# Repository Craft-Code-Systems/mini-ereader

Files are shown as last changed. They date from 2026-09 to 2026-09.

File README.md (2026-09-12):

# Mini E-Reader

> A pocket, frontlit e-paper reader you can build and hack.
> ESP32-S3 + 4.26" E-Paper (800×480) + tunable-white frontlight,
> USB-C charged, LiPo powered.

This repository holds the open hardware (KiCad) and project documentation
for a small e-reader. Docs follow the [Colophon](https://usecolophon.dev)
method: a Brief (this file), Decisions (`docs/adr/`), a Log
(`docs/research-log.md`), a Runbook (`docs/runbook.md`), and a Changelog.

> **One KiCad project, one source of truth.** The board lives at the repo root:
> **`ereader.kicad_pcb`**, with the electrical design in the `ereader-*.md`
> docs — `ereader-connection-list.md` (net-by-net source of truth),
> `ereader-schematic.md` (subsystem schematic), `ereader-pcb-design.md`
> (full spec), `ereader-footprints.md` (BOM/footprint picklist) — and the
> `ereader-kicad.net` netlist. (Rev C — placed, planed, stitched, DRC-ruled;
> routing pending.) An earlier, simpler `hardware/` *reference spec* was
> removed once `ereader.*` superseded it; the historical comparison is in
> `docs/research-log.md`. The Rev C parts are reconciled into the ADRs:
> [0006](./docs/adr/0006-i2c-managed-power-path.md) (power) supersedes 0003
> and [0007](./docs/adr/0007-lm3630a-frontlight-driver.md) (frontlight)
> supersedes 0005.

## Why

Commercial e-readers are closed and hard to modify. This is a compact,
documented reference design — cheap parts, two-layer board, hand- or
JLCPCB-assemblable — for reading plain text / EPUB on a persistent,
sunlight-readable display with an adjustable frontlight and Wi-Fi sync.
A buildable learning platform, not a product.

## Scope & non-scope

**In scope**
- Schematic + 2-layer PCB: MCU, 4.26" SPI E-Paper, tunable frontlight,
  power (USB-C + 1S LiPo), buttons, optional microSD.
- A bill of materials and fabrication-ready outputs.
- Automated ERC/DRC + gerber export in CI.

**Out of scope (for now)**
- Enclosure / industrial design (CAD).
- Firmware (tracked separately once hardware is proven).
- Touch input, audio, multi-panel support.
- Certification / mass production.

## Success criteria

1. Schematic captured with **ERC clean** in KiCad 8.
2. PCB placed + routed with **DRC clean**; gerbers export in CI.
3. A built prototype: powers from USB and battery, charges, enumerates
   over native USB, refreshes the E-Paper, and lights the frontlight with
   independent brightness + colour-temperature control.

## Capabilities

- Render text/EPUB to a 4.26" 800×480 monochrome E-Paper panel over SPI.
- Tunable-white frontlight: independent cold/warm channels, PWM brightness
  and colour-temperature mixing.
- Wi-Fi/BLE (ESP32-S3) for fetching and syncing books.
- Battery power (1S LiPo) with USB-C charging and USB-priority power path.
- Battery state-of-charge and charge-status telemetry.
- Three navigation buttons; BOOT/RESET jumper pads (screwdriver-shortable) for flashing.
- Optional microSD for local library storage.

## Non-functional baseline

- **Power:** deep-sleep with the page retained in the µA range; runs from a
  single LiPo; charges over USB-C.
- **Cost/build:** two-layer FR-4, common parts, low-cost assembly.
- **Serviceability:** test points on key rails and buses; native-USB
  programming with no external bridge.
- **Docs:** every significant decision captured as an ADR before it is
  built.

## Stack

- **MCU:** ESP32-S3-WROOM-1 (Wi-Fi/BLE, PSRAM, native USB).
- **Display:** Good Display **GDEY0426T82-FL01C** — 4.26" 800×480 E-Paper,
  controller **SSD1677**, 4-wire SPI, 24-pin FPC, with an integrated dual
  frontlight (5+5 series white LEDs, VF≤15 V, IF≤15 mA).
- **Power:** MCP73831 charger, discrete USB-priority load-share,
  AP2112K-3.3 LDO; 2× TPS61165 frontlight boost drivers.
- **EDA:** KiCad 8. **CI:** GitHub Actions (`kicad-cli` ERC/DRC/export).

## Status & milestones

**v0.1 — design captured; reviewable schematic in `ereader-schematic.md`; native Eeschema `.kicad_sch` + routed PCB not yet drawn in KiCad.**

- [x] Architecture, power tree, net list, pin map — `ereader-pcb-design.md` + `ereader-connection-list.md`
- [x] Decisions recorded — `docs/adr/0001`–`0005`
- [x] KiCad board `ereader.*` placed + config that opens cleanly
- [x] BOM + SKiDL netlist generator
- [x] CI: `kicad-cli` ERC/DRC/export workflow
- [~] Schematic — reviewable subsystem diagrams in `ereader-schematic.md`; native Eeschema capture + **ERC clean** pending
- [ ] PCB placed, routed + **DRC clean**
- [ ] Prototype built + brought up

Live verification state: the milestone checklist above.

## Key decisions

| # | Decision |
|---|---|
| [0001](./docs/adr/0001-mcu-esp32-s3.md) | ESP32-S3-WROOM-1 as the MCU |
| [0002](./docs/adr/0002-display-and-frontlight.md) | 4.26" 800×480 E-Paper + laminated tunable frontlight |
| [0003](./docs/adr/0003-power-architecture.md) | USB-C + 1S LiPo, load-share, 3.3 V LDO *(superseded by 0006)* |
| [0004](./docs/adr/0004-native-usb-programming.md) | Native-USB programming (no UART bridge) |
| [0005](./docs/adr/0005-frontlight-driver.md) | Dual boost constant-current frontlight driver *(superseded by 0007)* |
| [0006](./docs/adr/0006-i2c-managed-power-path.md) | I2C-managed power path: BQ25628E + TPS62840 + MAX17048 |
| [0007](./docs/adr/0007-lm3630a-frontlight-driver.md) | LM3630A single-boost dual-sink frontlight driver |
| [0008](./docs/adr/0008-navigation-input.md) | Navigation input: 3 side buttons + ALPS SLLB510200 lever switch |

## Getting started

```
# Open the board in KiCad 8
kicad ereader.kicad_pro

# Read the electrical design (source of truth)
less ereader-connection-list.md
```

See [`docs/runbook.md`](./docs/runbook.md) for capture, verification,
CI, fabrication, and bring-up. Component-level detail lives in
[`ereader-pcb-design.md`](./ereader-pcb-design.md) and
[`ereader-schematic.md`](./ereader-schematic.md).

## Repository layout

```
README.md              This Brief
CHANGELOG.md           Project history
ereader.*              The KiCad board (project, PCB, netlist, cmp)
ereader-*.md           Electrical source of truth: connection-list, schematic, pcb-design, footprints, README
ereader.pretty/        Project footprints (side tactile, ALPS SLLB5 lever)
ereader.3dshapes/      Simple 3D bodies for the project footprints
fp-lib-table           Registers the ereader.pretty footprint library
fab.py                 Gerber/drill export helper (preflight-gated)
gen_netlist.py         SKiDL netlist generator (real symbols → clean import)
preflight.py           Board↔netlist parity check (CI gate; fab.py guard)
docs/
  adr/                 Decisions (0001–0008 + template)
  research-log.md      Dated exploration notes
  runbook.md           Capture / verify / fabricate / bring-up
templates/             Colophon document templates (for ongoing use)
.github/workflows/     CI (KiCad ERC/DRC/export)
```

## License

[MIT](./LICENSE) for code, hardware, and documentation. *(This repository
started from the [Colophon](https://usecolophon.dev) template; the doc
method is reused under MIT here — the template's separate CC BY methodology
license has been removed.)*

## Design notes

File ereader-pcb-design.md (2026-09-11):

# Mini E-Reader — PCB Design Spec (Rev C)

Schematic-level ref. Not gerbers. Follow in KiCad. All part numbers byte-exact — verify against latest datasheets before order.

Rev C: frontlight FULLY RESOLVED from FL0426-S01C (2 independent 4-wire strings), CHG_CE hardware fallback locked in, magnet alignment silk markers, battery band set.

---

## 1. Decisions / assumptions

- MCU = **ESP32-S3-WROOM-1-N16R8** (kept). 8 MB octal PSRAM holds 800×480×2-plane framebuffer (96 KB) + EPUB render + fonts. 16 MB flash = OTA A/B + fonts + cache.
- Panel = **GDEY0426T82-FL01C** (frontlight cool/warm, 800×480, SSD1677, SPI, 3V3 logic). Panel FPC = 24-pin 0.5 mm. Frontlight FPC = 6-pin 0.5 mm (**FL0426-S01C**, confirmed §7).
- Battery = single-cell Li-Po, **~1000–2000 mAh, thin large-area**. Fast charge not needed → conservative Ichg (§8).
- USB-C = charge + native USB-OTG data + program (one connector; native USB-Serial/JTAG on S3).
- SoC charge cap (stop 80 / resume 50) = ESP32 over I2C, + hardware CE fallback (§8).
- Program/recovery = native USB + BOOT + RESET **jumper pads** (bare exposed
  pads, momentarily shorted with a screwdriver tip or tweezers — no switch part).

---

## 2. Block diagram

```
              USB-C (16p)
          VBUS │ CC1/CC2(5.1k) │ D+ D-  │ SBU(nc)
               │               │        │
        ┌──────┴──────┐   ┌────┴────┐   │
   ESD  │ USBLC6-2SC6 │   │(to S3   │   ESD (same array)
        └──────┬──────┘   │ USB19/20)│
               │VBUS               │
        ┌──────┴───────┐           │
        │ BQ25628E     │ I2C0(0x6B)│
        │ 2A buck chg  ├───────────┼──┐
        │ CE ◄─GPIO14  │           │  │
        └──┬────────┬──┘           │  │I2C0
        BAT│      SYS│             │  │
     ┌─────┴───┐  ┌──┴─────────┐   │  │
     │ Li-Po 1S│  │ TPS62840   │   │  │
     └────┬────┘  │ buck 3V3   │   │  │
      VBAT│       └──┬─────────┘   │  │
     ┌────┴─────┐ 3V3│             │  │
     │MAX17048  │    ├─────────────┼──┼──► ESP32-S3-WROOM-1-N16R8
     │gauge 0x36│────┘ I2C0        │  │      │  │  │
     └──────────┘                  │  │      │  │  └─I2C1(0x36)─► LM3630A ─► FL 6p FPC
                                   USB │      │  └─SPI──────────► EPD 24p FPC
                                       └─USB  └─SPI──────────► microSD
   Inputs: 3× side btn + SLLB510200 (CW/CCW/push) → GPIO pull-up, wake
   Prog:   BOOT(GPIO0) + RESET(EN) jumper pads (short w/ screwdriver)
```

---

## 3. BOM (core)

| Ref | Part | Fn | Notes |
|-----|---|-----|---|
| U1 | ESP32-S3-WROOM-1-N16R8 | MCU+radio | pre-certified module (FCC/IC/CE). Follow integration guide |
| U2 | TI **BQ25628E** | 1S I2C buck charger 2A | addr 0x6B. EN_CHG reg + CE pin (§8) |
| U3 | Maxim **MAX17048G+T10** | fuel gauge (ModelGauge, no sense R) | addr 0x36, I2C0 |
| U4 | TI **LM3630A** | dual-string I2C backlight boost | addr 0x36 → I2C1 (§7) |
| U5 | TI **TPS62840** | 3V3 buck 750 mA, Iq 60 nA | LDO alt if area-tight |
| U6 | ST **USBLC6-2SC6** | USB ESD array | D+/D-/CC/VBUS |
| J1 | USB-C recept 16-pin (e.g. GCT USB4085) | power+data | |
| J2 | 24-pin 0.5 mm FPC, bottom-contact | EPD | flip-lock |
| J3 | 6-pin 0.5 mm FPC | frontlight | 1=C+ 2=C− 3=NC 4=NC 5=W+ 6=W− |
| J4 | microSD push-pull holder | storage | |
| SW1–3 | Würth **WS-TASU 436351045816** (side push) | page/menu | `ereader:WE_WS-TASU_436351045816`; actuator faces board edge; Ø0.75 boss holes |
| SW4 | ALPS **SLLB510200** (510100 = alt) | lever+push (CW/CCW/press) | 10 mA/5 V max, 9.5×8.8×2.2 mm; `ereader:ALPS_SLLB5_Lever`; 2mm-pitch pads + Ø1.1 locators |
| JP5 | Bare pads (no MPN) | BOOT | GPIO0→GND, shorted momentarily w/ screwdriver/tweezers; `ereader:JumperPad_2P_P2.0mm` |
| JP6 | Bare pads (no MPN) | RESET | EN→GND, shorted momentarily w/ screwdriver/tweezers; `ereader:JumperPad_2P_P2.0mm` |
| — | 5.1 kΩ ×2 | CC1/CC2 Rd (sink) | |
| — | 100 kΩ | EN pull-up + 1 µF | module EN weak ~2 MΩ |
| — | 100 kΩ pull-up ×2 | EPD_CS, SD_CS idle-high thru boot | §5 |
| — | 100 kΩ pull-down ×1 | FL_HWEN (FL off at boot) | §5 |
| — | 100 kΩ strap ×1 | CHG_CE boot-default = charge-on | §8 |
| — | 4.7 kΩ ×4 | I2C0 + I2C1 pull-ups | |
| LE/QE/DE1-3/RE1-2/CE1-9 | SSD1677 external DC-DC (L+N-FET+3×Schottky+sense R+rail caps) | now captured line items | §6; copy interconnect 1:1 from Good Display ref |

---

## 4. Power tree

```
USB VBUS 5V ──► BQ25628E ──► SYS ──► TPS62840 ──► 3V3 rail
                    └──────► BAT (Li-Po 1S)
3V3  → U1 (≥500 mA headroom; RF bursts >avg), microSD, EPD VDD, gauge, logic
VBAT → LM3630A boost → ~15–18 V (2×5-series strings), Iset ≤15 mA/ch
VBAT → MAX17048 sense
```

- 3V3 survives S3 TX burst (~0.5 A): TPS62840 (750 mA) + 22 µF bulk at module 3V3.
- **I2C clash fix = 2 buses (locked).** Keeps sense-less MAX17048 + dual-ch LM3630A. 1-bus alt only if forced: gauge → BQ27441-G1A @0x55 (needs sense R).

---

## 5. ESP32-S3 pin map

Safe pins: 1–18, 21, 38–42, 47, 48. **Never 26–37** (26–32 flash, 33–37 octal PSRAM). USB 19/20 native. GPIO21 = static enable only.

| Signal | GPIO | Dir | Note |
|---|---|-----|---|
| EPD_SCLK | 12 | O | SPI ≤10–20 MHz |
| EPD_MOSI | 11 | O | DIN |
| EPD_CS | 10 | O | 100k pull-up (idle-high thru boot) |
| EPD_DC | 9 | O | |
| EPD_RST | 8 | O | boot-low harmless (re-reset in init) |
| EPD_BUSY | 7 | I | |
| SD_SCK | 41 | O | own SPI bus |
| SD_MOSI | 42 | O | |
| SD_MISO | 40 | I | |
| SD_CS | 39 | O | 100k pull-up (idle-high) |
| I2C0_SDA | 17 | IO | charger 0x6B + gauge 0x36 |
| I2C0_SCL | 18 | IO | |
| I2C1_SDA | 16 | IO | LM3630A 0x36 |
| I2C1_SCL | 38 | IO | |
| BTN_A | 4 | I | pull-up, RTC-wake |
| BTN_B | 5 | I | pull-up, RTC-wake |
| BTN_C | 6 | I | pull-up, RTC-wake |
| LEV_CW | 1 | I | pull-up, RTC-wake |
| LEV_CCW | 2 | I | pull-up, RTC-wake |
| LEV_PUSH | 15 | I | pull-up, RTC-wake |
| CHG_INT | 47 | I | BQ25628E /INT |
| GAUGE_ALRT | 48 | I | MAX17048 /ALRT (low-SoC wake) |
| FL_HWEN | 21 | O | LM3630A HWEN; 100k pull-down (FL off at boot) |
| CHG_CE | 14 | O | BQ25628E CE; 100k strap = charge-on default (§8) |
| BOOT | 0 | I | strap; JP5→GND (jumper pad); module 10k pull-up |
| RESET | EN | I | JP6→GND (jumper pad); 100k pull-up + 1 µF |
| USB_D- | 19 | — | native → J1 |
| USB_D+ | 20 | — | native → J1 |

Free/unused after this map: 3(strap), 13. All 6 btn/lever inputs RTC-capable → wake sources; assign BTN_A + LEV_PUSH, ext1-mask rest.

### Glitch-safe by design
- ⚠ GPIO1–18 ~60 µs low pulse at power-up; 18/19/20 glitch high. Audited:
- EPD_CS(10) + SD_CS(39): 100k pull-up → idle high thru boot → no spurious select. ✓
- FL_HWEN(21): 100k pull-down → frontlight OFF until firmware. ✓
- CHG_CE(14): 100k strap to charge-on level → boot-low pulse benign (charger debounces; default is charge-on anyway). ✓
- EPD_RST(8): boot-low benign (re-reset in init). ✓
- I2C0/1 + all btn/lever: pull-ups present → absorbed. ✓
- No glitch-sensitive load (gate/latch/relay) hangs unpulled off a glitchy pin. Glitch-safe. ✓

---

## 6. EPD subsystem (SSD1677)

4-line SPI (SDA-in only; write-mostly). Tie **BS1** for 4-wire SPI.

Match the **panel datasheet pin numbers exactly** (24-pin EPD FPC, 0.5 mm):
- Logic: SCLK, SDA(MOSI), CS, DC, RST, BUSY, VDD=3V3, VSS=GND, BS (tie low = 4-wire SPI).
- Booster/analog: GDR, RESE, VSH1/VSH2, VSL, VGL, VGH, VCOM, VCI, VDD, VPP — external DC-DC + reservoir caps per the **Good Display reference circuit** ("ESP32 Sample Code" zip). Copy 1:1; rail values non-negotiable. Short FPC stubs; guard-ground under booster caps.

**External DC-DC — exact values** (from the Good Display GDEY0426T82-FL01C reference circuit; verify against the panel datasheet before order. Designators are from that reference — renumber to match the `ereader` schematic):
- **L** 47 µH, ≥500 mA (NR3015 class): +3V3 → switch node (boost FET drain).
- **Q** Si1308EDL N-MOSFET (SOT-23): gate = GDR, drain = switch node, source = RESE. **R** 1 MΩ GDR→GND (gate pulldown) + **R** 2.2 Ω RESE→GND (current sense).
- **D×3** MBR0530 Schottky (≥30 V, ≥500 mA): one builds PREVGH (→ VGH); two build the PREVGL (→ VGL) charge-pump path.
- **Caps (all ≥25 V, X5R/X7R):** 4.7 µF on VSH1, VSH2, VSL, VGL/PREVGL, VGH/PREVGH, and the +3V3 boost input; 1 µF on VCI, VDD, VCOM.
- Internal rails: **VGH ≈ +20 V, VGL ≈ −20 V, VSH ≈ +15 V, VSL ≈ −15 V, VCOM ≈ −2 V** — hence the ≥25 V cap rating. Panel VCI draw is small (~7.5 mA), so the +3V3 boost input is light.

> **Now captured** (Rev C4) in `ereader-kicad.net` / `ereader-connection-list.md` as
> `LE` (47µH), `QE` (Si1308EDL), `DE1‑DE3` (MBR0530), `RE1` (2.2Ω sense), `RE2` (1MΩ
> GDR pulldown), `CE1‑CE6` (4.7µF/25V rails), `CE7‑CE9` (1µF/25V). ⚠ The diode/charge‑pump
> **interconnect + orientation + J2 FPC pin numbers are a functional placeholder** —
> transcribe them 1:1 from the Good Display reference before capture/route. Some SSD1677
> rails may be internally generated (external reservoir cap only); the reference is the
> authority on the actual diode/pump-cap count.

- Mechanical: EPD 24p FPC + FL 6p FPC both exit the bottom edge → place J2 + J3 adjacent on bottom edge.

---

## 7. Frontlight (LM3630A) — CONFIRMED

Source: **FL0426-S01C** drawing. Two **independent 4-wire** series strings (NOT common-anode):

| FL pin | Net | String |
|---|---|---|
| 1 | LED C+ | Cold anode |
| 2 | LED C− | Cold cathode |
| 3 | NC | — |
| 4 | NC | — |
| 5 | LED W+ | Warm anode |
| 6 | LED W− | Warm cathode |

- Cold = 5 series LED, Warm = 5 series LED. Per-LED Vf 2.8–3.6 V → string VF ≤15 V; IF ≤15 mA each. (10 LEDs total; "7 LED" web spec = wrong rev.)

**Final wiring (LM3630A single boost, dual sink):**
```
LM3630A OUT (boost) ──┬── FL pin1 (C+)
                      └── FL pin5 (W+)      ← both anodes tie to OUT
FL pin2 (C−) ── LM3630A LED1 sink (Bank A = COOL)
FL pin6 (W−) ── LM3630A LED2 sink (Bank B = WARM)
FL pin3,4 = NC
```
- Equal string length → shared boost OUT is efficient; boost regulates to the active sink. Set OVP ≥18 V (5×3.6). Program each bank Iset ≤15 mA; PWM per bank.
- Independent on/off + brightness per bank → full cool/warm blend + global dim. Firmware over I2C1 (0x36). FL_HWEN(21) = hard off in standby.
- No common-anode strap option needed (topology confirmed 4-wire). Drop that DNP.
- EMI: boost L + Cout loop <5 mm, local ceramics, far from antenna + FPC.

---

## 8. Charging + SoC optimization (ESP32-managed + HW fallback)

Chain: BQ25628E (charge control) + MAX17048 (SoC truth), both I2C0.

Primary control = **ESP32 over I2C** (BQ25628E EN_CHG) — the 80/50 mechanism, no fixed hardware threshold:
```c
soc = max17048_read_soc();            // %
if (soc >= 80) bq25628_charge_dis();  // clear EN_CHG
if (soc <= 50) bq25628_charge_en();   // set EN_CHG
```
- Hysteresis 50↔80 stops chatter.
- Default charge-on at power-up (before firmware) → dead-battery recovery; firmware then applies 80/50.
- **HW fallback (locked): CHG_CE → GPIO14**, 100k strap to charge-on level. Firmware can hard-cut even if I2C hangs; still ESP32-commanded (not a fixed threshold).
- **Ichg conservative** (fast charge not needed): set ~0.3–0.5C via reg → e.g. 500 mA for a 1.5 Ah cell. Gentler on a thin large-area pack; less heat. BQ25628E caps at 2 A regardless.
- Optional longevity: VREG 4.10–4.15 V (vs 4.20).
- Gauge /ALRT → GPIO48: low-SoC → wake + graceful shutdown.
- Enable BQ25628E thermal reg / JEITA; add NTC if pack has one.

---

## 9. USB-C

- Sink only: CC1,CC2 each 5.1 kΩ → GND (Rd). No source/DRP.
- VBUS → BQ25628E VBUS (+ input cap, + TVS via U6).
- D+/D- → S3 GPIO19/20 native + through U6 ESD. 90 Ω diff, length-match, short.
- SBU1/2 = NC. Shield → chassis via R+C (or direct per EMC).
- Full-speed (12 Mbps) fine for book sync/MSC + JTAG/programming.

---

## 10. Compliance (FCC / CE)

**Intentional radiator** handled by module. ESP32-S3-WROOM-1 = **FCC ID 2AC7Z-ESPS3WROOM1** + IC + CE/RED (modular). Inherit by:
- Module at board edge, antenna over edge, honor keep-out (no copper any layer, no traces, no fill, no parts).

**Magnets (phone-attach) — #1 RF risk:**
- Magnets live in the **3D-printed shell** (avoid NdFeB near reflow). PCB carries **silk alignment markers only** (see §11) so you register the shell's magnet pockets to the board — magnets are NOT on the PCB.
- Keep magnet zone ≥10–15 mm from antenna keep-out; opposite end from module.
- ⚠ Bigger issue = the **phone's own MagSafe ring + metal chassis** (always behind device). Orient antenna edge to overhang / clear the phone magnet array + metal. Antenna over free space, not over phone metal.

**Unintentional radiator / product testing still required:**
- FCC Part 15B (verification) — USB, switchers, digital.
- CE: EN 55032 + EN 55035; RED via module + product EMC; LVD N/A (<50 V). RoHS + REACH.
- Switchers (charger buck + FL boost) = main 15B risk: minimal switch-node loops, ceramics close, solid GND, spread-spectrum if available, optional shield can over FL boost.
- USB: ESD array (U6) + DNP common-mode choke footprint on D+/D-.
- Solid uninterrupted GND on layer 2; stitch vias around edge + keep-out.
- Use WROOM-1 (PCB antenna), not WROOM-1U, unless you certify an external antenna.

---

## 11. Layout rules (priority order)

1. Module antenna at edge, keep-out clear; magnet zone far (+ mind phone magnet ring, §10).
2. Continuous GND plane under everything except antenna keep-out.
3. FL boost: L + Schottky + Cout in <5 mm loop, far from antenna + FPC.
4. Charger buck loop tight; input cap at VBUS pin.
5. EPD booster caps hugging FPC pins; short stubs. J2 + J3 adjacent on bottom edge.
6. USB D+/D- 90 Ω diff, ESD at connector then module.
7. Decouple module 3V3: 22 µF + 4×0.1 µF at power pins; bulk at buck.
8. EN: 100 kΩ pull-up + 1 µF + RESET(JP6). BOOT(JP5)→GPIO0→GND.
9. Boot-default pulls: EPD_CS/SD_CS 100k↑, FL_HWEN 100k↓, CHG_CE 100k strap = charge-on.
10. I2C0 + I2C1: 4.7 kΩ pull-ups each to 3V3.
11. **Magnet alignment silk markers**: on the face nearest the shell magnets, print crosshair/circle fiducials at each magnet pocket center so the printed shell registers to the PCB. Copper-free zones there (mechanical only). Mirror position on far end from antenna.
12. Test points: 3V3, VBAT, SYS, I2C0, I2C1, BOOT, EN.

---

## 12. Stack / process

- 4-layer (SIG / GND / PWR / SIG). Controlled-Z for USB pair. ENIG finish (FPC + fine pitch).

---

## 13. Status

- Frontlight: **RESOLVED** — 2 independent strings (5 cool + 5 warm), 4-wire, LM3630A dual-bank (§7).
- Battery: ~1000–2000 mAh thin cell; only sets Ichg reg + case (non-schematic-blocking). Watch mechanical: recess the thin cell, no flex over components.
- Nothing outstanding blocks schematic capture.

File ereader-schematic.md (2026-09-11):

# Mini E-Reader — Schematic (subsystem view)

> **Why this file exists / why there is no `.kicad_sch`.** This board was captured
> **netlist-first**: the electrical design lives in
> [`ereader-connection-list.md`](./ereader-connection-list.md) (source of truth) →
> [`ereader-kicad.net`](./ereader-kicad.net) (netlist) → [`ereader.kicad_pcb`](./ereader.kicad_pcb)
> (placement). No schematic sheet was ever drawn, so KiCad's **Schematic Editor
> (Eeschema) has nothing to open** — that is the answer to "why is there no schematic".
>
> KiCad **cannot** auto-generate a schematic from a netlist or from the PCB (there is
> no netlist→schematic or PCB→schematic importer). A native `.kicad_sch` has to be
> *drawn* in Eeschema. The diagrams below are that schematic in reviewable form —
> they render directly on GitHub (Mermaid) and mirror the connection list net-for-net.
>
> **To get a native Eeschema schematic:** create a new schematic in the `ereader`
> project, drop the symbols for U1–U6 / J1–J5 / SW1–SW4 / JP5–JP6 / passives, and
> wire them to match these diagrams (label-based wiring is fine — same-named net
> labels connect). Run **ERC**, then it drives the same `ereader-kicad.net`.

All pin **numbers** on U1 are the exact ESP32‑S3‑WROOM‑1 datasheet pins; IC pins on
U2–U6 are by **function name** (remap to your chosen symbol's pads). Nets are taken
verbatim from the connection list.

---

## 1. System block diagram

```mermaid
flowchart LR
  USBC["USB-C J1<br/>(VBUS + USB2 + CC)"]
  ESD["U6 USBLC6-2SC6<br/>ESD"]
  CHG["U2 BQ25628E<br/>1S buck charger (I2C 0x6B)"]
  BATT["J5 Li-Po 1S"]
  GAUGE["U3 MAX17048<br/>fuel gauge (I2C 0x36)"]
  BUCK["U5 TPS62840<br/>3V3 buck"]
  MCU["U1 ESP32-S3-WROOM-1<br/>N16R8"]
  FL["U4 LM3630A<br/>dual FL boost (I2C1)"]
  EPD["J2 EPD FPC 24p<br/>SSD1677 / GDEY0426T82"]
  FLC["J3 Frontlight FPC 6p<br/>FL0426-S01C"]
  SD["J4 microSD"]
  NAV["SW1-3 side buttons<br/>SW4 SLLB5 lever"]

  USBC -->|"+VBUS"| CHG
  USBC --- ESD
  ESD ---|"USB_DP/DM"| MCU
  CHG -->|"+SYS"| BUCK
  CHG <-->|"+VBAT"| BATT
  CHG -->|"+VBAT"| GAUGE
  CHG -->|"+VBAT"| FL
  BUCK -->|"+3V3"| MCU
  MCU -->|"SPI 4-wire"| EPD
  MCU -->|"SPI"| SD
  MCU <-->|"I2C0"| CHG
  MCU <-->|"I2C0"| GAUGE
  MCU <-->|"I2C1"| FL
  FL -->|"FL_OUT + sinks"| FLC
  NAV -->|"GPIO active-low"| MCU
```

---

## 2. Power tree

```mermaid
flowchart TB
  J1["USB-C J1<br/>VBUS A4/B4/A9/B9"]
  CVBUS["C_VBUS"]
  U2["U2 BQ25628E"]
  LC["L_C ~1uH"]
  J5["J5 Li-Po +"]
  U3["U3 MAX17048"]
  U4["U4 LM3630A IN"]
  L2["L2 22uH"]
  U5["U5 TPS62840"]
  L1["L1 2.2uH"]
  RAIL3V3["+3V3 rail<br/>U1.2, J2.VDD, J4.VDD, pull-up rails, C_3V3 22uF+4x0.1uF"]

  J1 -->|"+VBUS"| U2
  J1 --- CVBUS
  U2 -->|"SW"| LC -->|"+SYS"| U5
  U2 <-->|"BAT = +VBAT"| J5
  U2 -->|"+VBAT"| U3
  U2 -->|"+VBAT"| U4
  U2 -->|"+VBAT"| L2
  U5 -->|"SW"| L1 -->|"+3V3"| RAIL3V3
  U5 -.->|"VIN = +SYS"| U2
```

`GND`: U1.1/40/41(EPAD), U2 PGND/GND/EP, U3/U4/U5/U6 GND, J1 GND+shield, J2.VSS,
J4.VSS, J5.−, all cap returns, all pull-down / switch returns.

---

## 3. MCU GPIO map (U1 = ESP32‑S3‑WROOM‑1)

| Pin | GPIO | Net | Goes to |
|-----|---|-----|---|
| 2 | 3V3 | +3V3 | supply |
| 1 / 40 / 41 | GND/EPAD | GND | ground |
| 3 | EN | EN | JP6 (RESET), R3 pull-up, C_EN |
| 27 | IO0 | IO0_BOOT | JP5 (BOOT) |
| 4 | IO4 | BTN_A | SW1.1 |
| 5 | IO5 | BTN_B | SW2.1 |
| 6 | IO6 | BTN_C | SW3.1 |
| 39 | IO1 | LEV_CW | SW4.CW |
| 38 | IO2 | LEV_CCW | SW4.CCW |
| 8 | IO15 | LEV_PUSH | SW4.PUSH |
| 10 | IO17 | I2C0_SDA | U2, U3, R8 |
| 11 | IO18 | I2C0_SCL | U2, U3, R9 |
| 9 | IO16 | I2C1_SDA | U4, R10 |
| 31 | IO38 | I2C1_SCL | U4, R11 |
| 20 | IO12 | EPD_SCLK | J2 |
| 19 | IO11 | EPD_MOSI | J2 |
| 18 | IO10 | EPD_CS | J2, R4 |
| 17 | IO9 | EPD_DC | J2 |
| 12 | IO8 | EPD_RST | J2 |
| 7 | IO7 | EPD_BUSY | J2 |
| 34 | IO41 | SD_SCK | J4 |
| 35 | IO42 | SD_MOSI | J4 |
| 33 | IO40 | SD_MISO | J4 |
| 32 | IO39 | SD_CS | J4, R5 |
| 14 | IO20 | USB_DP | U6, J1 |
| 13 | IO19 | USB_DM | U6, J1 |
| 24 | IO47 | CHG_INT | U2.INT, R12 |
| 22 | IO14 | CHG_CE | U2.CE, R7 |
| 23 | IO21 | FL_HWEN | U4.HWEN, R6 |

Strap/PSRAM/unused pins (IO3/13/45/46/35/36/37, RXD0/TXD0) → NC or test-point.

---

## 4. Navigation input (this is the input scheme from ADR 0008)

Nav contacts are **active-low momentary to GND** with the ESP32‑S3 **internal
pull-ups**; every one sits on an RTC‑capable GPIO so it can wake the MCU from deep
sleep. **SW1–SW3 are side-actuated (right-angle) tactiles** and **SW4 is the ALPS
SLLB5 two-way lever + push** — the actuators face the **board edge** because the
screen covers the whole front and magnets hold the back to the phone, so nothing
can be pressed from the top or bottom faces. **JP5/JP6 (BOOT/RESET) are not
switches** — they're bare exposed 2-pad jumpers, momentarily shorted with a
screwdriver tip or tweezers when you actually need to flash/recover the board;
they read open (floating high through the pull-up) in normal use, so there's no
switch part, cap, or accidental-press risk sitting on a rarely-used recovery path.

```mermaid
flowchart LR
  subgraph MCU["U1 ESP32-S3 (internal pull-ups, RTC-wake)"]
    IO4["IO4"]; IO5["IO5"]; IO6["IO6"]
    IO1["IO1"]; IO2["IO2"]; IO15["IO15"]
    IO0["IO0"]; EN["EN"]
  end
  SW1["SW1 side tact<br/>BTN_A"]; SW2["SW2 side tact<br/>BTN_B"]; SW3["SW3 side tact<br/>BTN_C"]
  SW4["SW4 ALPS SLLB5 lever<br/>CW / CCW / PUSH / COM"]
  JP5["JP5 jumper pad<br/>BOOT (screwdriver-shortable)"]; JP6["JP6 jumper pad<br/>RESET (screwdriver-shortable)"]
  GND(["GND"])

  IO4 -- "BTN_A" --> SW1 --> GND
  IO5 -- "BTN_B" --> SW2 --> GND
  IO6 -- "BTN_C" --> SW3 --> GND
  IO1 -- "LEV_CW" --> SW4
  IO2 -- "LEV_CCW" --> SW4
  IO15 -- "LEV_PUSH" --> SW4
  SW4 -- "COM" --> GND
  IO0 -- "IO0_BOOT" --> JP5 --> GND
  EN -- "EN" --> JP6 --> GND
```

`R3` (100k) pulls **EN** up with `C_EN` (1µF) for a clean reset; BOOT uses the
module's internal strap pull-up.

---

## 5. I2C buses

```mermaid
flowchart LR
  U1["U1 ESP32-S3"]
  R8["R8 4.7k"]; R9["R9 4.7k"]; R10["R10 4.7k"]; R11["R11 4.7k"]
  U2["U2 BQ25628E 0x6B"]; U3["U3 MAX17048 0x36"]; U4["U4 LM3630A"]
  V3["+3V3"]

  U1 -- "I2C0_SDA (IO17)" --> U2 & U3
  U1 -- "I2C0_SCL (IO18)" --> U2 & U3
  U1 -- "I2C1_SDA (IO16)" --> U4
  U1 -- "I2C1_SCL (IO38)" --> U4
  V3 --- R8 & R9 & R10 & R11
  R8 --- U2
  R9 --- U2
  R10 --- U4
  R11 --- U4
```

U3 (fuel gauge) and U4 (frontlight) both answer at 0x36 — that clash is exactly why
U4 is on a **separate bus (I2C1)**.

---

## 6. E‑paper (SSD1677 @ J2, 4‑wire SPI)

```mermaid
flowchart LR
  U1["U1 ESP32-S3"]
  R4["R4 100k"]; V3["+3V3"]
  J2["J2 EPD FPC 24p<br/>SSD1677 / GDEY0426T82"]

  U1 -- "EPD_SCLK (IO12)" --> J2
  U1 -- "EPD_MOSI (IO11)" --> J2
  U1 -- "EPD_CS (IO10)" --> J2
  U1 -- "EPD_DC (IO9)" --> J2
  U1 -- "EPD_RST (IO8)" --> J2
  J2 -- "EPD_BUSY (IO7)" --> U1
  V3 --- R4 --- J2
```

`J2.BS1` tied **low** (→GND) for 4‑wire SPI.

### 6a. EPD external DC‑DC (SSD1677 boost + charge pumps)

The SSD1677 needs an external boost + charge‑pump for its ±20 V gate / ±15 V source
rails. Now captured as real parts (LE/QE/DE1‑3/RE1‑2/CE1‑9) feeding J2's support pins:

```mermaid
flowchart LR
  V3["+3V3"]; LE["LE 47µH"]; QE["QE Si1308EDL<br/>N-FET"]
  SW["EPD_SW"]; DE1["DE1 MBR0530"]; DE2["DE2"]; DE3["DE3"]
  J2["J2 SSD1677<br/>GDR/RESE/VGH/VGL<br/>VSH1/VSH2/VSL/VCOM/VCI"]
  RE1["RE1 2.2Ω"]; RE2["RE2 1MΩ"]; GND(["GND"])

  V3 --> LE --> SW
  SW --> QE
  J2 -- "GDR" --> QE
  QE -- "RESE" --> RE1 --> GND
  J2 -- "GDR" --> RE2 --> GND
  SW --> DE1 -- "VGH" --> J2
  SW --> DE2 --> DE3 -- "VGL" --> J2
  J2 -. "VSH1/VSH2/VSL/VCOM reservoir caps CE1-3,CE9→GND" .- GND
  V3 -. "VCI/VDD caps CE6-8→GND" .- GND
```

> ⚠ **VERIFY & COPY 1:1.** The diode/charge‑pump interconnect, diode **orientation**, and
> the J2 (GDEY0426T82) **FPC pin numbers** are a functional PLACEHOLDER — transcribe them
> exactly from the Good Display GDEY0426T82‑FL01C reference schematic ("ESP32 Sample Code"
> zip) and the panel datasheet before capture + route. Rail cap **values are
> non‑negotiable** (≥25 V). See `ereader-connection-list.md` → *EPD external DC‑DC*.

---

## 7. microSD (SPI @ J4) and USB‑C data

```mermaid
flowchart LR
  U1["U1 ESP32-S3"]
  R5["R5 100k"]; V3["+3V3"]
  J4["J4 microSD"]
  U6["U6 USBLC6-2SC6"]
  J1["J1 USB-C"]
  R1["R1 5.1k"]; R2["R2 5.1k"]; GND(["GND"])

  U1 -- "SD_SCK (IO41)" --> J4
  U1 -- "SD_MOSI (IO42)" --> J4
  J4 -- "SD_MISO (IO40)" --> U1
  U1 -- "SD_CS (IO39)" --> J4
  V3 --- R5 --- J4
  U1 -- "USB_DP (IO20)" --- U6 --- J1
  U1 -- "USB_DM (IO19)" --- U6 --- J1
  J1 -- "CC1" --- R1 --> GND
  J1 -- "CC2" --- R2 --> GND
```

---

## 8. Charger (BQ25628E) + 3V3 buck (TPS62840)

```mermaid
flowchart LR
  VBUS["+VBUS"]; SYS["+SYS"]; VBAT["+VBAT"]; V3["+3V3"]
  U2["U2 BQ25628E"]; LC["L_C ~1uH"]; CBTST["C_BTST 0.047uF"]
  R7["R7 100k"]; R12["R12 10k"]; R14["R14 10k"]; R15["R15 10k"]; GND(["GND"])
  U5["U5 TPS62840"]; L1["L1 2.2uH"]
  U1["U1 ESP32-S3"]

  VBUS --> U2
  U2 -- "SW" --> LC --> SYS
  U2 -- "BTST" --- CBTST
  U2 --- VBAT
  U1 -- "CHG_CE (IO14)" --> U2
  U2 -- "CHG_INT" --> U1
  U2 -- "INT" --- R12 --> V3
  U2 -- "CE" --- R7 --> GND
  U2 -- "TS" --- R14 --> V3
  U2 -- "TS" --- R15 --> GND
  SYS --> U5
  U5 -- "SW" --> L1 --> V3
```

`CE low = charge enabled`; R7→GND makes charge-on the power-up default, GPIO14 drives
high to hard-disable.

---

## 9. Frontlight boost (LM3630A → FL0426‑S01C, 4‑wire)

```mermaid
flowchart LR
  VBAT["+VBAT"]; U4["U4 LM3630A"]; L2["L2 22uH"]; D1["D1 Schottky 30V"]
  CFL["C_FL >=25V"]; J3["J3 FL FPC 6p"]
  U1["U1 ESP32-S3"]; R6["R6 100k"]; GND(["GND"])

  VBAT --> U4
  VBAT --> L2 -- "FL_SW" --> U4
  U4 -- "FL_SW" --> D1 -- "FL_OUT" --> CFL
  D1 -- "FL_OUT" --> J3
  J3 -- "FL_COOL_K (C-)" --> U4
  J3 -- "FL_WARM_K (W-)" --> U4
  U1 -- "FL_HWEN (IO21)" --> U4
  U4 --- R6 --> GND
```

`FL_OUT` feeds both J3.1 (C+) and J3.5 (W+); LED1/LED2 sink the cool/warm banks;
`R6→GND` keeps the frontlight off by default until GPIO21 enables it.

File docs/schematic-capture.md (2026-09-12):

# Schematic Capture Worksheet (Eeschema)

Follow this once to draw a native `ereader.kicad_sch`. It turns the netlist-first
design into a proper schematic-driven project so that **Update PCB from Schematic**
works cleanly and the "pad *X* not found in footprint" errors disappear.

## Why this is needed (read once)

`ereader-kicad.net` names IC pins by **function** (`IN`, `SDA`, `SW`, `LED1`…).
KiCad's netlist import binds those names to footprint **pads**, but real footprints
number their pads (QFN `1..n`, BGA `A1/B1…`). With no symbol in between, the names
never match — that is the 56 `pad ... not found` errors seen on netlist import.

A **symbol** solves it: the symbol pairs each pin *name* with the datasheet pad
*number*. So in schematic capture you only attach nets to named pins; KiCad maps
name → pad number for you. **You never hand-map pads.**

> `ereader-connection-list.md` stays the human source of truth (net-by-net).
> The schematic *implements* it. Once the schematic drives the board, the
> hand-authored `ereader-kicad.net` is retired (Eeschema generates its own).

## One-time setup

1. Open `ereader.kicad_pro` in the KiCad project manager.
2. Open the **Schematic Editor**. It will be empty (there is no `.kicad_sch`
   yet — that is expected, and is why *Update PCB from Schematic* / F8 errored).
   Save immediately as `ereader.kicad_sch` in the project folder.
3. Capture per the tables below, then annotate → ERC → assign footprints →
   **Update PCB from Schematic**.

## Capture method: label-based wiring (do this, it's fast)

You do **not** need to draw wires across the sheet. Use **global labels**
(`Place → Add Global Label`, hotkey **Ctrl+H**) whose text is the **net name**
from `ereader-connection-list.md`. Two pins carrying the same-named global label
are connected. So the loop for every pin is:

1. Place the symbol.
2. On each pin, drop a short wire stub + a **global label** named after its net.
3. Move on. Same net name anywhere = one net.

Power nets (`+3V3`, `+VBAT`, `+SYS`, `+VBUS`, `GND`) are cleanest with **power
symbols** (`Place → Add Power`, **P**) instead of labels — `GND`, `+3V3`, etc.

## Symbol + footprint picklist

The symbol carries the pin→pad map, so **use a matched symbol+footprint pair**.
KiCad-stock ones are safe as-is; for the `SnapEDA` rows, download the symbol AND
its footprint together (they are internally consistent) and confirm the package
against the MPN. Footprints reflect the corrections in `ereader-footprints.md`.

| Ref | MPN | Symbol (lib_id or source) | Footprint |
|-----|-----|---|---|
| U1 | ESP32-S3-WROOM-1-N16R8 | `RF_Module:ESP32-S3-WROOM-1` (stock) | `RF_Module:ESP32-S3-WROOM-1` |
| U2 | BQ25628ERYKR | SnapEDA / TI | **18-pin WQFN 2.5×3.0mm (RYK)** — vendor land |
| U3 | MAX17048G+T10 | KiCad `Battery_Management` if present, else SnapEDA/ADI | µDFN-8 2×2mm |
| U4 | LM3630AYFQR | SnapEDA / TI | DSBGA-12, 0.4mm |
| U5 | TPS62840DLCR | KiCad `Regulator_Switching` if present, else SnapEDA/TI | **VSON-HR 8-pin 2.0×2.0mm (DLC)** |
| U6 | USBLC6-2SC6 | `Power_Protection:USBLC6-2SC6` (stock) | `Package_TO_SOT_SMD:SOT-23-6` |
| J1 | USB-C 16P | `Connector:USB_C_Receptacle_USB2.0` | `...:USB_C_Receptacle_HRO_TYPE-C-31-M-12` |
| J2 | EPD 24p FPC | `Connector:Conn_01x24` (numbered) | `...:Hirose_FH12-24S-0.5SH...` |
| J3 | FL 6p FPC | `Connector:Conn_01x06` | `...:Hirose_FH12-6S-0.5SH...` |
| J4 | microSD | `Connector:microSD_HC` (or holder symbol) | `...:microSD_HC_Hirose_DM3AT-SF-PEJM5` |
| J5 | Li-Po 1S | `Connector:Conn_01x02` | `Connector_JST:JST_PH_S2B-PH-K...` |
| SW1-3 | WE WS-TASU | `Switch:SW_Push` | `ereader:WE_WS-TASU_436351045816` |
| SW4 | ALPS SLLB510200 | `Switch:SW_...` w/ pins CW/CCW/PUSH/COM | `ereader:ALPS_SLLB5_Lever` |
| JP5/JP6 | jumper pads | `Jumper:SolderJumper_2_Open` | `ereader:JumperPad_2P_P2.0mm` |
| QE | Si1308EDL | `Transistor_FET:Si1308EDL` or `Device:Q_NMOS_GSD` | `Package_TO_SOT_SMD:SOT-23` |
| DE1-3 | MBR0530 | `Device:D_Schottky` | `Diode_SMD:D_SOD-123` |
| D1 | Schottky 30V | `Device:D_Schottky` | `Diode_SMD:D_SOD-123` |
| L1/LC | 2.2µH / 1µH | `Device:L` | `Inductor_SMD:L_0805_2012Metric` |
| L2/LE | 22µH / 47µH | `Device:L` | `L_1210_3225Metric` |
| R* | see BOM | `Device:R` | `Resistor_SMD:R_0402_1005Metric` |
| C* | see BOM | `Device:C` | per `ereader-footprints.md` |

## Wiring — go subsystem by subsystem

`ereader-connection-list.md` is the authoritative pin→net list; the Mermaid
diagrams in `ereader-schematic.md` show each subsystem. Capture in this order,
labeling each pin with its net name from the connection list:

1. **U1 (MCU).** Its pins are **numbered** in the connection list (exact
   WROOM-1 datasheet pins) and the stock symbol uses those same numbers —
   attach each net (`+3V3`, `GND`, `EPD_SCLK`, `I2C0_SDA`, `USB_DP`, …) to the
   matching pin. Tie unused strap/PSRAM pins per §"Unused module pins".
2. **Power** (§ Power): USB-C `J1` → `U6` ESD → `U2` charger → `U5` buck →
   `+3V3`; `U3` gauge; `J5` battery. Use power symbols for the rails.
3. **I²C** (§ I2C): `R8/R9` on `I2C0`, `R10/R11` on `I2C1`.
4. **EPD `J2`** (§ EPD): logic pins + the support rails.
5. **EPD external DC-DC** (§ EPD external DC-DC): `LE/QE/DE1-3/RE1/RE2/CE1-9`.
6. **microSD `J4`**, **USB-C `J1`** (§ microSD / USB-C).
7. **Buttons/lever** (§ Buttons/lever), **BOOT/RESET** (§ Program/reset).
8. **Charger switching**, **buck**, **frontlight boost** (their § sections).
9. **Decoupling** (§ Decoupling): place each cap on its rail per the table.

## Three things that need care

- **J2 (EPD FPC) pin numbers.** The connection list gives J2 pins by function
  (`SCLK`, `GDR`, `VGH`, …). The `Conn_01x24` symbol has numbered pins 1-24. Map
  each function to its **FPC pin number from the GDEY0426T82-FL01C datasheet**
  before wiring — this is the one mapping the datasheet must supply. (J4 microSD
  uses named pads that already line up.)
- **EPD DC-DC interconnect is a placeholder.** Capture `LE/QE/DE1-3/RE1-2/CE1-9`
  per § EPD external DC-DC, but **transcribe the diode/charge-pump topology and
  orientation 1:1 from the Good Display GDEY0426T82-FL01C reference schematic**
  before trusting it. Rail cap values are non-negotiable (≥25V).
- **Footprint swaps will re-do routing.** When you assign the correct U2/U5
  lands (and any others), *Update PCB from Schematic* replaces the placeholder
  footprints on the board — the traces routed to those old lands are dropped and
  must be re-routed. Expect this; it is why the wrong placeholders should be
  fixed before investing in routing them.

## Finish

1. **Annotate** (`Tools → Annotate`) — keep the existing refdes (U1, U2, …).
2. **ERC** (`Inspect → Electrical Rules Checker`) — resolve every error.
3. **Assign footprints** (the table above) — every symbol gets one.
4. **Update PCB from Schematic** (F8) — the parts bind by pad number; the
   "pad not found" errors are gone.
5. Place + route the new/changed parts; stitch the 3 `GND_F.Cu` islands.
6. `python3 preflight.py` (still valid: board must contain every part) → DRC → 0/0.

Once the schematic drives the board, delete or stop maintaining
`ereader-kicad.net` (Eeschema now generates the netlist), and update the
milestone checklist in `README.md`.

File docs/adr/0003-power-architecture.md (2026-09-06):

# Decision 0003: USB-C + 1S LiPo, discrete load-share, 3.3 V LDO

**Status:**      Superseded by [Decision 0006](./0006-i2c-managed-power-path.md)
**Date:**        2026-09-05

> Superseded 2026-09-06: the canonical board (`ereader.*`, Rev C) uses an
> I2C-managed power path (BQ25628E charger, TPS62840 buck, MAX17048 gauge).
> See [Decision 0006](./0006-i2c-managed-power-path.md). The Context and
> reasoning below are preserved as the trail.

## Context

The reader must run from a rechargeable battery, charge over USB-C, and
provide a clean 3.3 V rail to an MCU whose Wi-Fi TX peaks near 500 mA. A
single-cell LiPo (3.0–4.2 V) is the obvious chemistry for a pocket device.
Three sub-decisions: charger, source selection (USB vs battery), and
regulation. (The frontlight's ~15 V rail is a separate boost stage — see
[Decision 0005](./0005-frontlight-driver.md).)

The tension is regulation: an LDO is tiny and quiet but cannot boost, so
the 3.3 V rail sags once the cell falls below ~3.4 V, wasting the battery
tail; a buck-boost uses the whole range but adds cost, area, and switching
noise near the RF module and ADC.

## Decision

Charge with **MCP73831** (PROG-set, 500 mA). Select the source with a
**discrete load-share** — a DMG2305UX P-FET (battery→VSYS, off when USB
present) plus a Schottky (USB→VSYS) — so USB powers the system and only
charges the cell when plugged. Regulate VSYS→3.3 V with an **AP2112K-3.3**
LDO (600 mA), generously bulk-decoupled for TX bursts.

## Considerations

**Pro:** Minimal BOM and board area; every part is cheap, common, and
hand-solderable; the load-share avoids charging and discharging the cell
at once; the LDO is silent (no switching noise near the RF module or ADC).

**Con:** LDO dropout wastes the 3.0–3.4 V battery tail; the discrete
load-share has a Schottky drop (~0.3 V) on the USB path and no proper DPPM.

Rejected for v0.1, kept as upgrade paths:
- **MCP73871** power-path charger — seamless switching + DPPM, but larger
  and more complex. Adopt if "run while charging a dead battery" matters.
- **TPS63020 buck-boost** on 3.3 V — uses the full 3.0–4.2 V range, at the
  cost of area, EMI, and BOM. Adopt if runtime per charge is the priority.

## Consequences

- Bulk capacitance near the module 3V3 pins must cover 500 mA TX bursts
  (≥ 22 µF local + 10 µF rail); see `ereader-pcb-design.md`.
- Usable battery floor is ~3.4 V; firmware low-battery warning triggers
  above that.
- Charge current (R_PROG) is re-chosen for the actual cell capacity
  (≤ 1C). 2.0 kΩ = 500 mA is the placeholder.
- A battery-sense divider to an ADC and the charger STAT line to a GPIO
  give firmware state-of-charge and charge state.
- The frontlight boost stage draws from VSYS, not +3V3.

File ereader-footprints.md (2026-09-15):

# Mini E-Reader — Footprint / Land-Pattern Picklist

✓ = in KiCad 8 official libs (use as-is). ⚑ = pull from SnapEDA / Ultra-Librarian / mfr, verify pad map.
Always DRC land vs the ordered part's datasheet before route.

## Actives

| Ref | MPN | Package | Footprint | Source | Notes |
|-----|-----|---|---|---|---|
| U1 | ESP32-S3-WROOM-1-N16R8 | 41-pin SMD module | `RF_Module:ESP32-S3-WROOM-1` | ✓ KiCad | symbol `RF_Module:ESP32-S3-WROOM-1`. Honor antenna keep-out in courtyard |
| U2 | BQ25628E**RYK**R | **18-pin WQFN-HR (HotRod), 2.5×3.0mm, 0.5mm pitch (RYK), no EP** | `ereader:WQFN-HR18__RYK_TEX` | ⚑ TI Ultra-Librarian | ✅ package confirmed (SLUSFA4C). HotRod = pads 1–18, **no thermal pad** (ground via the pin array) |
| U3 | MAX17048G+T10 | **TDFN-8, 2.0×2.0mm, 0.5mm pitch, WITH EP** | `ereader:SON50P200X200X80-9N` | ⚑ SnapEDA / ADI | ✅ EP confirmed (symbol package = "TDFN-8", SnapEDA pairs the 9N/EP land). EP = pad 9 → GND. Uses the same 2×2 9N land as U5 (both TDFN/VSON-8+EP); confirm EP/pad dims vs the ADI drawing before route |
| U4 | LM3630A**YFQ**R | DSBGA-12 (12-bump, 0.4mm pitch) | ⚑ TI Ultra-Librarian | ✅ DSBGA-only part (no WSON variant exists — earlier note was wrong). 0.4mm BGA → check fab min ball/via; hardest part to self-assemble (see README) |
| U5 | TPS62840**DLC**R | **VSON-HR-8 (DLC), 2.0×2.0mm, 0.5mm pitch, WITH EP** | `ereader:SON50P200X200X80-9N` | ⚑ TI Ultra-Librarian | ✅ package confirmed (SLVSEC6D). EP = pad 9 → GND (added to symbol) |
| U6 | USBLC6-2SC6 | SOT-23-6 | `Package_TO_SOT_SMD:SOT-23-6` | ✓ KiCad | symbol `Power_Protection:USBLC6-2SC6` ✓ |

## Connectors

| Ref | MPN | Footprint | Source | Notes |
|-----|-----|---|---|---|
| J1 | USB-C 16-pin recept (USB2, e.g. HRO TYPE-C-31-M-12 / GCT USB4085) | `Connector_USB:USB_C_Receptacle_HRO_TYPE-C-31-M-12` | ✓ KiCad | 16-pin = power+USB2 only. Add 2 mount posts to GND |
| J2 | EPD FPC 24p 0.5mm | `Connector_FFC-FPC:Hirose_FH12-24S-0.5SH_1x24-1MP_P0.50mm_Horizontal` ✓ KiCad | ⚑ verify | ⚠ match **contact side** (GDEY0426T82 FPC = bottom-contact) + flip-lock. Pick a flip-lock ZIF |
| J3 | FL FPC 6p 0.5mm | `Connector_FFC-FPC:Hirose_FH12-6S-0.5SH_1x06-1MP_P0.50mm_Horizontal` ✓ KiCad | ⚑ verify | same contact-side rule as J2 |
| J4 | microSD push-pull | `Connector_Card:microSD_HC_Hirose_DM3AT-SF-PEJM5` | ✓ KiCad | or Molex 5031821852 |
| J5 | Li-Po 1S | `Connector_JST:JST_PH_S2B-PH-K_1x02_P2.00mm_Horizontal` | ✓ KiCad | or SH 1.0mm if slim |

## Switches

| Ref | MPN | Footprint | Source | Notes |
|-----|-----|---|---|---|
| SW1-3 | Würth **WS-TASU 436351045816** (4.7×3.5mm side push, boss) | `ereader:WE_WS-TASU_436351045816` | ⚑ project lib (from WE datasheet) | **Side-actuated** — actuator faces the board edge (screen covers the front, magnets the back, so no top/bottom access). The old `SW_SPST_TL3342` was **top-actuated** — wrong. Land per WE datasheet rev 001.003: 4 pads 1.2×0.7mm at x=±2.8/y=±1.35 + **2× Ø0.75 boss holes** at y=±1.375 (pins 1≡3 / 2≡4). DRC vs datasheet before fab |
| SW4 | ALPS **SLLB510200** (SLLB510100 = pin-compatible alt) | `ereader:ALPS_SLLB5_Lever` | ⚑ project lib (from ALPS datasheet) | 2-dir lever + push, 9.5×8.8×2.2mm. Land per ALPS SLLB5 datasheet (p.491): 4 signal pads 1.0×1.3mm on 2mm pitch in order CW/COM/PUSH/CCW + **2× Ø1.1 locator holes** at x=±1.9 + solder lugs. DRC vs the ALPS drawing before fab |
| JP5, JP6 | — (bare pads; no switch part, no MPN to order) | `ereader:JumperPad_2P_P2.0mm` | ⚑ project lib (hand-drawn, no datasheet) | **BOOT/RESET are now exposed jumper pads, not tactiles.** Two 1.2×1.2mm SMD pads on 2.0mm pitch (0.8mm exposed air-gap) at the same board location the SW5/SW6 tactiles used to occupy — still edge-adjacent so the same case cutout/access point works. Momentarily bridge the pair with a screwdriver tip or tweezers to pull BOOT/RESET low; open circuit (floating on the pull-up) otherwise. No mechanical part to place or order, so this also drops two BOM line items. Pads must stay reachable from outside the case, same access constraint that drove the side-tactile placement |

## Passives / discrete

| Ref | Value | Footprint | Notes |
|-----|---|---|---|
| R1-15 | see BOM | `Resistor_SMD:R_0402_1005Metric` | 0603 if hand-solder |
| C* (0.1/1µF) | — | `Capacitor_SMD:C_0402_1005Metric` | |
| CS,CB,CI,CO,CF,CU1 (10-22µF) | — | `Capacitor_SMD:C_0805_2012Metric` | CF ≥25V (FL_OUT) |
| L1 | 2.2µH | `Inductor_SMD:L_0805_2012Metric` | buck; ≥1A Isat |
| LC | ~1µH | `Inductor_SMD:L_0805_2012Metric` | charger buck; per BQ25628E |
| L2 | 22µH | `Inductor_SMD:L_1210_3225Metric` | FL boost; ≥0.3A, per LM3630A |
| D1 | Schottky 30V | `Diode_SMD:D_SOD-123` | FL boost rectifier |

## EPD support (SSD1677 external DC-DC, local to J2)
Now captured as real BOM line items (designators from `ereader-kicad.net`), place hugging J2:

| Ref | Value | Footprint | Notes |
|-----|---|---|---|
| LE | 47µH | `Inductor_SMD:L_1210_3225Metric` | boost inductor +3V3→SW, ≥500mA (NR3015 class) |
| QE | Si1308EDL | `Package_TO_SOT_SMD:SOT-23` | boost N-FET; verify SOT-23 pin order G/S/D vs the chosen MPN |
| DE1..3 | MBR0530 | `Diode_SMD:D_SOD-123` | charge-pump Schottky ≥30V; verify count/orientation vs reference |
| RE1 | 2.2Ω | `Resistor_SMD:R_0402_1005Metric` | RESE current-sense |
| RE2 | 1MΩ | `Resistor_SMD:R_0402_1005Metric` | GDR gate pull-down |
| CE1..6 | 4.7µF/25V X7R | `Capacitor_SMD:C_0805_2012Metric` | VSH1/VSH2/VSL/VGL/VGH + boost input |
| CE7..9 | 1µF/25V X7R | `Capacitor_SMD:C_0603_1608Metric` | VCI/VDD/VCOM |

⚠ The exact **diode/charge-pump interconnect, orientation, and J2 FPC pin numbers** are a
functional placeholder — **copy 1:1 from the Good Display GDEY0426T82-FL01C reference
schematic** before route. Rail cap values non-negotiable; keep ratings ≥25V.

## Library setup
1. KiCad official libs cover ✓ rows out of the box.
2. For ⚑ rows: SnapEDA (free login) or TI/ADI Ultra-Librarian → export KiCad symbol+footprint → add as project-local lib.
3. Confirm every ⚑ package suffix against the exact orderable MPN (JLCPCB/LCSC/Mouser stock) before committing land patterns.

## Project footprint library (`ereader.pretty`)
The switches now resolve from a **project-local library** registered in
[`fp-lib-table`](./fp-lib-table) as nickname **`ereader`** (`${KIPRJMOD}/ereader.pretty`):
- `WE_WS-TASU_436351045816` — Würth WS-TASU side-push tactile (SW1-3); land + Ø0.75 boss holes drawn from the WE datasheet.
- `ALPS_SLLB5_Lever` — the SLLB5 lever (SW4), pads CW/COM/PUSH/CCW on 2mm pitch + 2× Ø1.1 locator holes + lugs, drawn from the ALPS datasheet.
- `JumperPad_2P_P2.0mm` — bare 2-pad jumper (JP5 BOOT, JP6 RESET), two 1.2×1.2mm exposed pads on 2mm pitch, no switch part.

The two switches carry simplified 3D bodies in `ereader.3dshapes/*.wrl` (referenced with
`scale 0.3937` so KiCad renders them 1:1 in mm) so they show in the 3D viewer without
KiCad's stock libraries, **except `JumperPad_2P_P2.0mm`**, which is flat copper with no
3D body — nothing to model. The switch lands are **stand-ins** — swap in the vendor
STEP/WRL and DRC the land vs the ordered MPN before fab; the jumper pad is hand-drawn
geometry (no datasheet to verify against) — DRC the pad size/spacing against your
fab's minimum clearance and your enclosure's access cutout before fab.

- `ALPS_SLLB5_Lever` 3D body — the SLLB5 is a **flat, low "fan"/semicircular puck**
  (W 9.5 × D 8.8 × **H 2.2 mm**, the datasheet Lever-Return family) that lies on the
  board with the terminal row along the front edge and a **low sideways rocker/toggle
  lever** on top (flick left↔right = CW/CCW, press = PUSH). The earlier body rendered as
  a tall block with an upward knob — wrong; it is now the flat puck + sideways lever.

## Self-contained 3D bodies (whole board renders without KiCad's stock libraries)
Every placed component now references a **project-local** body in
`ereader.3dshapes/*.wrl` (`${KIPRJMOD}/…`, `scale 0.3937`) instead of KiCad's stock
`${KICAD*_3DMODEL_DIR}` packs, so `ereader.kicad_pcb` shows a full 3D view even on a
machine/CI without the KiCad 3D-model add-on installed (the previous stock refs went
missing there). These are **simplified stand-ins** (boxes/cylinders sized from each
part's datasheet/footprint outline, colour-coded by class: black IC epoxy, beige MLCC,
grey inductors/plastics, metal shells for USB-C/microSD, natural nylon for the JST) —
they are for visualisation only. Swap in vendor STEP/WRL models before fabrication.
Fiducials, M2 mounting holes, and the bare `JumperPad_2P_P2.0mm` have no body — nothing
to model.

## Netlist / .cmp footprint status (Rev C3)
In `ereader-kicad.net` + `ereader.cmp`:
- **Assigned (import clean):** U1, U6, J1, J2 (full FH12-24S name), J3 (full FH12-6S name), J4, J5, L1/L2/LC, D1, **SW1-4** (SW1-3 → `ereader:WE_WS-TASU_436351045816`, SW4 → `ereader:ALPS_SLLB5_Lever`), **JP5/JP6** (→ `ereader:JumperPad_2P_P2.0mm`), all R/C.
- **Left BLANK on purpose → assign in KiCad *Footprint Assignment* (CvPcb):** U2 BQ25628E, U3 MAX17048, U4 LM3630A, U5 TPS62840. No official KiCad footprint exists → pull from SnapEDA/Ultra-Librarian per confirmed MPN, or draw the land from the datasheet. Blank = no "not found" error; component just awaits a footprint.
- ⚠ J1 USB-C string assumes `USB_C_Receptacle_HRO_TYPE-C-31-M-12` exists in your install (it imported fine for you). If a future error hits it, blank it and assign your exact 16-pin part.
- SW4 is no longer a pin-header placeholder — its pads are named **CW / CCW / PUSH / COM**, so the lever's nets (LEV_CW/CCW/PUSH + GND) now connect on netlist import. Verify the land against the ALPS SLLB5 drawing before route.
- **JP5/JP6 replace the SW5/SW6 tactiles (Rev C3).** BOOT/RESET are no longer a switch part — they're bare exposed pads you short momentarily with a screwdriver tip or tweezers. Same board position as the old SW5/SW6, same nets (`IO0_BOOT`/`EN` on pad 1, `GND` on pad 2), so nothing else in the netlist changed. Drops two Würth tactiles from the BOM.

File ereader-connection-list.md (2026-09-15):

# Mini E-Reader — Net-by-Net Connection List (tool-agnostic)

Master connectivity. Source of truth for the netlist + schematic. Endpoints = `RefDes.PinName`.
Module U1 pin **numbers** are exact (ESP32-S3-WROOM-1 datasheet). IC pins by **function name** — remap to your symbol's pads.

⚠ Polarity note: BQ25628E **CE low = charge ENABLED**. Default charge-on = CE pulled **low** (R7→GND). GPIO14 drives high to hardware-disable.

---

## Components

| Ref | Part | Notes |
|-----|---|---|
| U1 | ESP32-S3-WROOM-1-N16R8 | 41-pin module |
| U2 | BQ25628E | 1S buck charger, I2C 0x6B |
| U3 | MAX17048 | fuel gauge, I2C 0x36 |
| U4 | LM3630A | dual backlight boost, I2C 0x36 (I2C1) |
| U5 | TPS62840 | 3V3 buck |
| U6 | USBLC6-2SC6 | USB/CC ESD (SOT-23-6) |
| J1 | USB-C recept 16-pin | power + USB2 |
| J2 | FPC 24p 0.5mm | EPD (SSD1677) |
| J3 | FPC 6p 0.5mm | frontlight (FL0426-S01C) |
| J4 | microSD holder | |
| J5 | JST-PH/SH 2p | Li-Po battery |
| L1 | 2.2µH | TPS62840 buck |
| L2 | 22µH | LM3630A boost |
| L_C | ~1µH | BQ25628E buck (SW→SYS) |
| D1 | Schottky ~30V | LM3630A boost |
| SW1..3 | tactile | BTN_A/B/C |
| SW4 | SLLB510200 | lever CW/CCW/PUSH + COM |
| JP5 | jumper pad (2-pin, open) | BOOT |
| JP6 | jumper pad (2-pin, open) | RESET |
| R1,R2 | 5.1k | CC1,CC2 Rd |
| R3 | 100k | EN pull-up (+C_EN 1µF) |
| R4,R5 | 100k | EPD_CS, SD_CS pull-up |
| R6 | 100k | FL_HWEN pull-down |
| R7 | 100k | CHG_CE pull-down (charge-on default) |
| R8,R9 | 4.7k | I2C0 SDA/SCL pull-up |
| R10,R11 | 4.7k | I2C1 SDA/SCL pull-up |
| R12,R13 | 10k | CHG_INT, GAUGE_ALRT pull-up |
| R14,R15 | 10k+10k | BQ25628E TS divider (or NTC) |
| LE | 47µH | EPD SSD1677 boost inductor (+3V3→SW), ≥500mA |
| QE | Si1308EDL | EPD boost N-MOSFET (SOT-23): G=GDR, S=RESE, D=EPD_SW |
| DE1..3 | MBR0530 | EPD charge-pump Schottky (≥30V), builds VGH / VGL rails |
| RE1 | 2.2Ω | EPD RESE current-sense (RESE→GND) |
| RE2 | 1MΩ | EPD GDR gate pull-down (GDR→GND) |
| CE1..CE6 | 4.7µF/25V | EPD rail reservoirs: VSH1, VSH2, VSL, VGL, VGH, +3V3 boost input |
| CE7..CE9 | 1µF/25V | EPD rail decoupling: VCI, VDD, VCOM |
| CGA,CGB | 0.1µF+1µF | MAX17048 CELL local decoupling (+VBAT) |
| C4I | 1µF | LM3630A IN local decoupling (+VBAT) |
| C_RG (CRG) | 4.7µF | BQ25628E REGN internal-LDO bypass (→GND) [datasheet Fig 9-1] |
| C_PM (CPM) | 10µF | BQ25628E PMID bulk bypass (→GND) [datasheet Fig 9-1] |
| CPM2 | 0.1µF | BQ25628E PMID HF bypass (→GND) [datasheet Fig 9-1] |
| R17 | 1.65k (E96, 1%) | BQ25628E ILIM set (→GND) → ~1.5A input limit (RILIM=2500/IINREG) |
| R16 | 267k (E96, 1%) | TPS62840 VSET output-select (→GND) = 3.3V out (datasheet Table 1, TPS62840DLC column) |
| C_* | decoupling | see notes |

---

## Nets

### Power
```
+VBUS   : J1.VBUS(A4,B4,A9,B9), U2.VBUS, U6.VBUS, C_VBUS.1, TVS
+SYS    : U2.SYS, L_C.2, U5.VIN, U5.EN, C_SYS.1
          (U5.EN sits on the INPUT rail = always-on. Do NOT tie EN to +3V3:
           it is the buck's own output, so the rail could never start.)
+VBAT   : U2.BAT, U3.CELL, U3.VDD, U4.IN, L2.1, J5.+, C_BAT.1
          (U3.VDD is a SEPARATE fuel-gauge supply pin, 2.5–4.5V, not the same
           pad as CELL sense — both sit on +VBAT.)
+3V3    : U5.VOS(=output sense; VOS←L1←SW), U1.2, J2.VCI, J2.VDDIO, J4.VDD,
          R3.1, R4.1, R5.1, R8.1, R9.1, R10.1, R11.1, R12.1, R13.1,
          C_3V3(bulk 22µF + 4×0.1µF)
          (J2.VDD is the SSD1677 internal LDO output → decap only, NOT on +3V3.)
GND     : U1.1, U1.40, U1.41(EPAD), U2.GND (RYK HotRod WQFN-HR18: pads 1-18, no exposed pad),
          U3.GND, U3.CTG, U3.QSTRT, U3.EP, U4.GND, U4.SEL, U4.PWM,
          U5.GND, U5.EP(pad9 thermal), U5.MODE, U5.STOP,
          U6.GND, J1.GND(A1,B1,A12,B12)+shield, J2.VSS, J2.BS1,
          J4.VSS, J4.shield(P1–P4), J5.-, all C.2 / pull-down returns / SW returns
```

### I2C
```
I2C0_SDA : U1.10(IO17), U2.SDA, U3.SDA, R8.2
I2C0_SCL : U1.11(IO18), U2.SCL, U3.SCL, R9.2
I2C1_SDA : U1.9(IO16),  U4.SDA, R10.2
I2C1_SCL : U1.31(IO38), U4.SCL, R11.2
```

### EPD (SSD1677 @ J2) — match GDEY0426T82 datasheet pin numbers
```
EPD_SCLK : U1.20(IO12), J2.SCLK
EPD_MOSI : U1.19(IO11), J2.SDA(DIN)
EPD_CS   : U1.18(IO10), J2.CS,  R4.2
EPD_DC   : U1.17(IO9),  J2.DC
EPD_RST  : U1.12(IO8),  J2.RST
EPD_BUSY : U1.7(IO7),   J2.BUSY
J2.BS1   : GND (tie low = 4-wire SPI, per datasheet)
```

### EPD external DC-DC (SSD1677 boost + charge pump, local to J2)
Transcribed **1:1 from the Good Display GDEY0426T82-FL01C spec §8.2 Reference Circuit.**
The external L1(=LE) boost + charge pump builds VGH(+)/VGL(−); the panel derives
VSH1/VSH2/VSL/VCOM internally (external reservoir caps only). Ref part map:
LE=L1(47µH), QE=Q1(Si1308EDL), DE1/DE2/DE3=D1/D2/D3(MBR0530), RE2=R1(1M), RE1=R2(2.2Ω),
CE6=C4, CE10=C3, CE5=C5, CE2=C2, CE7=C6, CE8=C7, CE1=C9, CE3=C10, CE4=C11, CE9=C12.
```
+3V3       : LE.1 (boost input), CE6.1 (=C4 input cap)      [CE6.2→GND, 4.7µF/25V]
EPD_SW     : LE.2, QE.D, DE3.A, CE10.1(=C3)                 (boost switch node / pump drive)
EPD_GDR    : J2.GDR, QE.G, RE2.1                             [RE2.2→GND, 1MΩ pulldown]
EPD_RESE   : J2.RESE, QE.S, RE1.1                            [RE1.2→GND, 2.2Ω sense]
EPD_NODEX  : CE10.2(=C3), DE2.A, DE1.K                       (charge-pump node)
EPD_VGH    : J2.VGH, DE3.K, CE5.1  (PREVGH, +)              [CE5.2→GND, 4.7µF/25V]
EPD_VGL    : J2.VGL, DE1.A, CE4.1  (PREVGL, −)              [CE4.2→GND, 4.7µF/25V]
GND        : DE2.K   (D2 cathode clamps node X to GND)
EPD_VSH1   : J2.VSH1, CE1.1                                   [CE1.2→GND, 4.7µF/25V]
EPD_VSH2   : J2.VSH2, CE2.1                                   [CE2.2→GND, 4.7µF/25V]
EPD_VSL    : J2.VSL, CE3.1                                    [CE3.2→GND, 4.7µF/25V]
EPD_VCOM   : J2.VCOM, CE9.1                                   [CE9.2→GND, 1µF/25V]
+3V3       : J2.VCI (analog 3.3V), CE7.1                      [CE7.2→GND, 1µF/25V]
+3V3       : J2.VDDIO (=VCI, both 3.3V)
EPD_VDD    : J2.VDD, CE8.1 (SSD1677 internal LDO out, decap only)  [CE8.2→GND, 1µF/25V]
J2.VPP     : NC (OTP program pin, per ref)
```
> ✅ **Now matches the Good Display reference** (diode roles, C3 coupling cap, and the
> node-X charge pump). Rail caps are ≥25V per the ref spare-part table (C1–C12).
> Historical caveat retained below for context:
> and the J2 (GDEY0426T82) **FPC pin numbers** above are a functional PLACEHOLDER —
> transcribe them exactly from the Good Display GDEY0426T82-FL01C reference schematic
> ("ESP32 Sample Code" zip) and the panel datasheet before schematic capture and
> routing. Rail **cap values are non-negotiable**; ratings must stay ≥25V. Some SSD1677
> rails (VGH/VGL/VSH/VSL) may be generated internally with only reservoir caps external —
> the reference is the authority on how many diodes/pump caps are actually needed.

### microSD (SPI mode @ J4)
```
SD_SCK  : U1.34(IO41), J4.CLK
SD_MOSI : U1.35(IO42), J4.CMD(DI)
SD_MISO : U1.33(IO40), J4.DAT0(DO)
SD_CS   : U1.32(IO39), J4.CD/DAT3(CS, pin2), R5.2
(J4.DAT1,DAT2 → pull-up 10k to 3V3 or leave per holder)
(J4 shell/shield tabs P1–P4 → GND; card-detect SWA/SWB left NC)
```

### Buttons / lever (active-low, internal pull-up)
```
BTN_A    : U1.4(IO4),  SW1.1     (SW1.2→GND)
BTN_B    : U1.5(IO5),  SW2.1     (SW2.2→GND)
BTN_C    : U1.6(IO6),  SW3.1     (SW3.2→GND)
LEV_CW   : U1.39(IO1), SW4.CW
LEV_CCW  : U1.38(IO2), SW4.CCW
LEV_PUSH : U1.8(IO15), SW4.PUSH
SW4.COM  : GND
```

### Program / reset
```
IO0_BOOT : U1.27(IO0), JP5.1     (JP5.2→GND)
EN       : U1.3(EN),   JP6.1, R3.2, C_EN.1   (JP6.2→GND, C_EN.2→GND)
```
JP5/JP6 are bare exposed pads (no switch part) — short them momentarily with a
screwdriver tip or tweezers to trigger BOOT/RESET. See §4 of
`ereader-schematic.md` and `ereader-footprints.md`.

### USB-C
```
USB_DP : U1.14(IO20), U6.I/O1(pads 1+6), J1.DP1(A6)+DP2(B6)
USB_DM : U1.13(IO19), U6.I/O2(pads 3+4), J1.DM1(A7)+DM2(B7)
CC1    : J1.CC1(A5), R1.1   (R1.2→GND)
CC2    : J1.CC2(B5), R2.1   (R2.2→GND)
J1.SBU1(A8), J1.SBU2(B8) : NC ; J1.shield = pad SH → GND
U6.VBUS(pad5) : +VBUS (clamp ref) ; U6.GND(pad2) → GND
```

### Charger switching (BQ25628E)
```
CHG_SW   : U2.SW, L_C.1, C_BTST.1
CHG_BTST : U2.BTST, C_BTST.2      (0.047µF SW→BTST)
TS_BIAS  : U2.TS_BIAS, R14.1                        (regulated bias for the TS divider)
TS       : U2.TS, R14.2, R15.1    (R15.2→GND)       (fixed divider, or NTC to GND)
REGN     : U2.REGN, C_RG(CRG).1   (→GND, 4.7µF)   internal-LDO bypass  [datasheet Fig 9-1]
PMID     : U2.PMID, C_PM(CPM).1 + CPM2.1  (→GND, 10µF + 0.1µF)          [datasheet Fig 9-1]
CHG_INT  : U1.24(IO47), U2.*INT(pin11), R12.2
CHG_CE   : U1.22(IO14), U2.*CE(pin14), R7.1   (R7.2→GND = charge-on default)
ILIM     : U2.ILIM, R17.1  (R17.2→GND, 1.65kΩ)  → IINREG = 2500/RILIM ≈ 1.5A input limit.
           REQUIRED: EN_EXTILIM resets to 1 (ILIM pin active from power-on); an open pin
           would clamp input current to ~0. Retune RILIM=2500/IINREG(A); keep 0.4–2A (no RC).
U2.*PG, U2.STAT, U2.*QON : NC (open-drain / internal pull-up; optional in Fig 9-1).
```

### 3V3 buck (TPS62840DLCR — resistor-programmed output)
```
BUCK_SW : U5.SW, L1.1        (L1.2→+3V3)
U5.VIN  : +SYS
U5.EN   : +SYS (always-on from the INPUT rail; NOT +3V3 — see Power note)
VSET    : U5.VSET, R16.1     (R16.2→GND)  ← R16 = 267k (E96,1%) sets 3.3V out (TPS62840DLC, datasheet Table 1)
U5.VOS  : +3V3 (output-voltage sense; this part has VOS, no FB pin)
U5.MODE : GND (Power-Save, auto PFM/PWM; tie high for forced-PWM)
U5.STOP : GND (normal switching; STOP high halts switching for noise-free measurement)
```

### Frontlight boost (LM3630A) — FL0426-S01C confirmed 4-wire
```
FL_SW     : U4.SW, L2.2, D1.A
FL_OUT    : D1.K, C_FL.1(≥25V), J3.1(C+), J3.5(W+)
FL_COOL_K : J3.2(C-), U4.LED1 (Bank A = COOL sink)
FL_WARM_K : J3.6(W-), U4.LED2 (Bank B = WARM sink)
J3.3, J3.4 : NC
U4.HWEN   : FL_HWEN = U1.23(IO21), R6.1   (R6.2→GND = FL off default)
U4.OVP    : set ≥18V per datasheet resistors (or internal)
L2.1      : +VBAT   (boost inductor VBAT→SW)
U4.IN     : +VBAT
```

---

## Decoupling / bulk (place close to pins)
```
U1 3V3  : 22µF + 4×0.1µF          → CU1 + CU2..CU5
U2 VBUS : 1µF ; SYS: 10µF ; BAT: 10µF ; BTST: 0.047µF   → CV / CS / CB / CBT
U5      : Cin 10µF (SYS), Cout 10µF (3V3)   → CI / CO
U4      : Cin 1µF (VBAT), Cout ≥1µF/25V (FL_OUT)   → C4I / CF
U3 CELL : 0.1µF + 1µF             → CGA / CGB
EPD     : rail reservoirs CE1..CE6 (4.7µF/25V), CE7..CE9 (1µF/25V)  — see EPD DC-DC above
```

## Unused module pins (leave NC / test-point)
```
U1.15(IO3 strap), U1.16(IO46 strap), U1.21(IO13), U1.26(IO45 strap),
U1.28(IO35 PSRAM), U1.29(IO36 PSRAM), U1.30(IO37 PSRAM),
U1.36(RXD0/IO44), U1.37(TXD0/IO43), U1.13? no(used).
Tip: bring RXD0/TXD0 to test-points for a UART fallback console.
```

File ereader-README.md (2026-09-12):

# Mini E-Reader — KiCad Package (README)

Open **`ereader.kicad_pro`** in KiCad 7/8 → open the **PCB Editor** (Pcbnew). Press `Home` to zoom-to-fit.

## What's here
| File | What |
|---|---|
| `ereader.kicad_pro` | project |
| `ereader.kicad_pcb` | **board: all 49 parts placed by subsystem + outline (66×115mm) + antenna keep-out silk + magnet markers + 71% of nets wired (ratsnest)** |
| `ereader-kicad.net` | netlist (import to refresh nets) |
| `ereader.cmp` | ref↔footprint map |
| `ereader-connection-list.md` | master net-by-net (source of truth) |
| `ereader-schematic.md` | schematic (subsystem Mermaid diagrams; renders on GitHub) |
| `ereader-footprints.md` | footprint picklist + ✓/⚑ status |
| `ereader.pretty/` + `ereader.3dshapes/` | project footprints (side tactile, SLLB5 lever, bare jumper pad) + simple 3D bodies for the switches |
| `ereader-pcb-design.md` | full design spec (power, pinmap, compliance, layout) |

## Honest status — what this IS / IS NOT
**IS:** an openable project; every part positioned in a real floorplan; board outline; keep-out + magnet fiducials; ratsnest for the module, all passives, and most of USB-C; a reviewable schematic (`ereader-schematic.md`).
**IS NOT:** routed, not a Gerber, not manufacturing-ready, **not** a native Eeschema `.kicad_sch` — the design is netlist-first (see `ereader-schematic.md` for why, and how to draw one).

## Manual steps remain (unavoidable — this is the engineering)

> **First:** in the PCB editor, `File → Import → Netlist… → ereader-kicad.net`
> (match **by Reference**, leave **"Delete extra footprints" unchecked** so the
> FID/H board-only parts survive, then **Update PCB**).
> Rev C4 added the **EPD external DC-DC block** (LE/QE/DE1-3/RE1-2/CE1-9) plus
> local decoupling (CGA/CGB/C4I). These are in the netlist/`.cmp` but **not yet
> placed on the .kicad_pcb** — the re-import brings them in as unplaced parts.
>
> ⚠ **Not** *Update PCB from Schematic* (F8) and **do not open the Schematic
> Editor** — there is no `.kicad_sch`, so those error with "The schematic for
> this board cannot be found." This project is netlist-first; import the `.net`.

1. **Fix the flagged parts + name-only pins** (~29% of endpoints unconnected by design, listed below):
   - **Placeholder footprints (real land = wrong)** → replace with exact per datasheet: `U2` BQ25628E (**18-pin WQFN 2.5×3.0mm RYK** — current placeholder is a wrong 24-pin QFN), `U3` MAX17048 (µDFN-8 2×2), `U4` LM3630A (DSBGA-12 0.4mm), `U5` TPS62840 (**VSON-HR/DLC 8-pin 2×2mm** — current placeholder is oversized 3×2). Pull from SnapEDA / Ultra-Librarian; see `ereader-footprints.md`. (`SW1-4` use the project-local `ereader.pretty` lands — still DRC vs the ordered MPN. `JP5`/`JP6` bare jumper pads — check pad spacing vs fab minimum.)
   - **Name-only pins** don't auto-match numeric pads → assign in symbol or connect while routing:
     - `J2` (EPD FPC): logic + the new support rails (GDR, RESE, VGH, VGL, VSH1, VSH2, VSL, VCOM, VCI, BS1) → **map each to the GDEY0426T82 24-pin FPC number from the panel datasheet.** This is the one genuinely datasheet-blocked remap.
     - `J4` (microSD): the netlist uses the DM3AT pad names (CLK/CMD/DAT0/DAT3/VDD/VSS) so it should map on import — just add DAT1/DAT2 pull-ups + wire the card-detect/shield pads.
     - `U2-U5`/`U6`: IC function-name pins → pads of the real symbol.
     (`SW4` resolved — pads named CW/CCW/PUSH/COM.)
   - **EPD DC-DC interconnect** → the diode/charge-pump wiring + orientation are a functional placeholder; **copy 1:1 from the Good Display GDEY0426T82-FL01C reference schematic** (see `ereader-connection-list.md` → *EPD external DC-DC*).
2. **Place-tune → route → DRC → Gerbers.** Follow §11 layout rules in the design spec (antenna keep-out, FL-boost + charger loops tight, EPD boost loop tight, USB 90Ω diff, GND plane).

## EasyEDA instead?
EasyEDA **Pro** → File → Import → *KiCad* accepts `ereader.kicad_pcb`. No separate EasyEDA project provided (KiCad is the cleaner base here).

## Notes baked into the board
- Antenna keep-out = top silk band + label. No copper any layer there; keep magnets ≥10-15mm away.
- Magnet fiducials = 2 silk crosshair circles (align the printed shell magnets; magnets NOT on PCB).
- BQ25628E `CE` low = charge enabled → `R7`→GND = charge-on default; GPIO14 drives high to hard-disable.

## Rev 2 — route-ready additions
- **4-layer stackup** (SIG / GND / PWR / SIG).
- **GND planes**: filled zones on In1.Cu (plane), F.Cu, B.Cu — poured everywhere except the antenna keep-out band. Re-fill with `B` after you move parts.
- **Net classes** (Board Setup → Net Classes):
  - `Power` 0.40mm track / 0.20 clearance / 0.8-0.4 via → GND, +VBUS, +SYS, +VBAT, +3V3, FL_OUT, FL_SW, CHG_SW, BUCK_SW, **EPD_SW, EPD_VGH, EPD_VGL, EPD_VSH1, EPD_VSH2, EPD_VSL, EPD_PREVGL** (EPD boost node + ±20V/±15V rails — keep the EPD_SW loop tight, and give the ±20V rails clearance for their ~40V swing).
  - `USB` 0.25mm, diff-pair 0.20/0.13 → USB_DP, USB_DM (tune to 90Ω against your real stackup).
  - `Default` 0.20/0.15 → everything else.
- **`ereader-placement.svg`** = subsystem floorplan to eyeball before you commit.

## Rev 3 — mechanical + fab pipeline
- **Mounting holes** H1-H4 (M2, 2.2mm) at corners — relocate to match your shell.
- **Fiducials** FID1-3 (bottom edge) for assembly.
- **GND via stitching** — 58 vias, ~6mm pitch perimeter ring, tied to GND, knitting the planes.
- **DRC ruleset (JLCPCB 4-layer)** baked into `ereader.kicad_pro`: min track 0.15mm, clearance 0.15mm, via 0.45/0.30, edge clearance 0.30, annular ≥0.13. Track/via/diff-pair presets loaded.
- **`fab.py`** — one command to emit Gerbers + Excellon drill + zip:  `python3 fab.py`  → `ereader-gerbers.zip` (11 layers + PTH/NPTH). The zip is a build artifact (git-ignored) — regenerate it, don't commit it.

## ⛔ The one gate that remains: ROUTING
The board is **placed, planed, stitched, and DRC-ruled — but NOT routed** (no signal traces).
Gerbers from `fab.py` at this stage = pours + pads + vias, **no traces between pads → not manufacturable yet.** Fab them and you get a dead board.

To finish:
1. Swap the 4 placeholder footprints (U2-U5) for exact parts; remap the name-only pins (EPD/microSD/ICs) so their nets connect. (SW1-6 lands are in `ereader.pretty` — still DRC vs the ordered switch datasheets.)
2. **Route** every ratsnest line (Route → Route Tracks). Honor §11 of the design spec: antenna keep-out, tight FL-boost + charger switch loops, USB 90Ω diff pair, star-ground the analog returns.
3. Run **DRC** → zero unconnected, zero violations.
4. `python3 fab.py` (or Pcbnew → Plot) → upload `ereader-gerbers.zip` to JLCPCB.

**Why I don't autoroute it for you:** this is an RF (2.4GHz module) + USB + switching-converter board. An autorouter connects nets but wrecks the antenna keep-out, switch-node loops, and diff-pair impedance — i.e. exactly the FCC/CE compliance you specified. Routing is the engineering, and it's yours (or a layout contractor's). I can export a **Specctra DSN** for freerouting if you accept it won't be compliance-ready.

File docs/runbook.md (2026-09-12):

# Runbook

How to work on the Mini E-Reader: open the design, verify it, run CI,
produce fabrication files, and bring up a board.

## Prerequisites

- **KiCad 8.x** with its standard symbol/footprint libraries (they ship
  with KiCad). The project files are KiCad 8 format. The switch footprints
  come from the project-local `ereader.pretty` library (`fp-lib-table`).

## Open the project

```
kicad ereader.kicad_pro
```

This is the single canonical KiCad project (at the repo root). The board
(`ereader.kicad_pcb`) is **placed but not routed**; no native Eeschema
schematic is captured yet. The electrical design itself is
`ereader-connection-list.md` (net-by-net source of truth) +
`ereader-pcb-design.md`, drawn up in `ereader-schematic.md`.
First check: the PCB editor opens without file errors. If KiCad offers to
upgrade the file version, accept and re-save.

## Capture the schematic

Three routes:

0. **Regenerate the netlist with SKiDL** (`gen_netlist.py`) — the automated
   path. `pip install skidl` and run `python3 gen_netlist.py` in your KiCad
   environment: it builds every connection from `ereader-connection-list.md`
   using **real symbols**, so pins carry their datasheet pad numbers and the
   emitted `ereader-kicad.net` imports with **no "pad not found"** errors. Fill
   the `CFG` block for the non-stock parts (U2-U5, J2, SW4 — SnapEDA symbols in
   `ereader.kicad_sym`) and read "KNOWN ITEMS TO VERIFY" at the bottom of the
   script (U5.FB, diode polarity, J2 FPC pinout, EPD DC-DC 1:1). First run
   surfaces any pin-name/library mismatch to fix. Then import per route 2.
1. **By hand in Eeschema** (a real schematic makes IC pins bind to footprint
   pads by number — same fix, visual + ERC). Follow the step-by-step
   [`docs/schematic-capture.md`](./schematic-capture.md) worksheet: symbol +
   footprint picklist, label-based wiring, and the per-subsystem order, drawn
   from `ereader-schematic.md` / `ereader-connection-list.md` /
   `ereader-footprints.md`.
2. **Refresh nets from the netlist**: in the PCB editor, *File → Import →
   Netlist…* → click the folder icon → pick `ereader-kicad.net` → match
   footprints **by Reference** → **Update PCB**. New parts drop in (piled at
   one spot) to be placed + routed. This is the connectivity source; it does
   not draw a schematic (see `ereader-schematic.md` for why the design is
   netlist-first and how to get a native `.kicad_sch`).

   > ⚠ **Do NOT use *Tools → Update PCB from Schematic* (F8), and do not open
   > the Schematic Editor** — this project has no `.kicad_sch`, so both fail
   > with "The schematic for this board cannot be found." Use *File → Import →
   > Netlist…* instead. In that dialog, **leave "Delete extra footprints"
   > unchecked**, or KiCad will remove the fiducials (FID1-3) and mounting
   > holes (H1-4), which are board-only and not in the netlist.

## Verify (the "review" step)

- **ERC** in Eeschema: *Inspect → Electrical Rules Checker*. Resolve every
  error; justify any warning kept.
- **Footprint assignment**: every symbol → a real footprint.
- **DRC** in the PCB editor after layout: *Inspect → Design Rules Checker*.
  Zero unrouted, zero clearance errors.
- Update the milestone checklist in `/README.md` as items go green.

## CI: KiCad in the cloud

`.github/workflows/kicad.yml` runs on pushes/PRs that touch
`ereader.kicad_pcb`, `ereader-kicad.net`, or the workflow itself (and on demand
via *Run workflow*). In the `kicad/kicad:8.0` container it:

- prints `kicad-cli version`,
- runs **DRC** on the board (`ereader.kicad_pcb`),
- exports **gerbers** + drill, uploaded as the `kicad-outputs`
  build artifact.

CI is now a **hard gate** (the board is meant to be routed):

1. **`preflight.py`** — fails if any `ereader-kicad.net` component is missing
   from `ereader.kicad_pcb`. kicad-cli DRC never compares board vs netlist, so
   this catches a board routed before *Update PCB from Netlist* (which is how a
   board reached `main` missing the whole EPD DC-DC block — see CHANGELOG).
2. **DRC** — `kicad-cli pcb drc --refill-zones --exit-code-violations`; a
   nonzero result (violations or unconnected items) fails the job.
3. Gerbers export only when both gates pass, so no fab output is ever produced
   from an out-of-sync or DRC-dirty board.

This is the persistent "KiCad-capable environment"; day-to-day capture and
routing happen locally in KiCad. Run `python3 preflight.py` locally before you
commit a routed board.

## Fabrication outputs (JLCPCB / generic)

**First run `python3 preflight.py`** — it must report every netlist component
present on the board. `fab.py` runs the same check and refuses to emit gerbers
from an out-of-sync board (override with `--force` only for a deliberate
partial/debug export). Then, from the PCB editor once DRC is clean (or download
the CI artifact):

- **Gerbers**: *File → Plot* → F.Cu, B.Cu, F/B.SilkS, F/B.Mask, F/B.Paste,
  Edge.Cuts → `fab/`. Then *Generate Drill Files* (Excellon).
- **BOM**: *Tools → Generate BOM*, or use `ereader-footprints.md` as the master picklist.
- **Placement (CPL)**: *File → Fabrication Outputs → Component Placement*.
- Zip the gerbers + drill for the fab house.

`fab/`, `gerbers/`, `*.zip`, and `*.kicad_prl` are git-ignored (outputs /
per-user state, not source).

## Bring-up (first power-on)

1. Inspect solder; ohmmeter-check VBUS/VBAT/VSYS/+3V3 → GND for shorts.
2. Power via USB-C only (no battery). Confirm +3V3 = 3.3 V.
3. Confirm the board enumerates as a USB serial/JTAG device.
4. Flash a blinky/serial test over native USB (if the toolchain can't
   auto-enter the bootloader: bridge the JP5 BOOT pads with a screwdriver tip
   or tweezers and hold, briefly bridge the JP6 RESET pads and release them,
   then release JP5).
5. Bring up the E-Paper with a controller driver matched to the panel.
6. Bring up the frontlight (LM3630A over **I2C1**, addr 0x36 — SDA=GPIO16,
   SCL=GPIO38): drive **FL_HWEN=GPIO21 high** to enable, then set each bank's
   brightness/current over I2C (Bank A = cool, Bank B = warm). Start at a low
   current setting and confirm ≤ 15 mA/channel before going bright. (There is no
   direct-GPIO PWM to the LEDs — GPIO15/16 are LEV_PUSH / I2C1_SDA, not backlight
   PWM; the LM3630A does the boost + per-bank PWM internally.)
7. Add battery; confirm charging (STAT LED) and the battery-sense ADC.

## Adding a decision

When you make a real design choice, copy `docs/adr/0000-template.md` to the
next number and fill it in. Decisions are immutable once accepted — write a
superseding Decision rather than editing an old one.

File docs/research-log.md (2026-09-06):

# Research Log

Dated, append-only exploration notes for the Mini E-Reader. Newest last.

---

## 2026-09-05 — Project kickoff / hardware design captured

- Repository started from the Colophon docs template; adapted into the
  Mini E-Reader project.
- Chose the core stack (ESP32-S3, 1S LiPo + USB-C, SPI E-Paper). Recorded
  as ADRs 0001, 0003, 0004.

## 2026-09-05 — Display identified from frontlight datasheet

- Owner supplied **Good Display FL0426-S01C** — this is a **frontlight**
  module (light guide + LEDs), *not* the e-paper panel. It fixes the
  display size at **4.26", 480×800 dots**.
- Frontlight electricals (from the drawing): two channels, **5 series
  white LEDs each, VF ≤ 15 V, IF ≤ 15 mA**; 6-pin 0.5 mm FPC
  (1 LEDC+, 2 LEDC−, 3 NC, 4 NC, 5 LEDW+, 6 LEDW−); LGP 61.40 × 104.10 mm,
  total thickness 0.685 mm; operating 0–50 °C.
- Implication: need a **dual constant-current boost driver** (~15 V,
  ≤15 mA/channel, independent PWM) for brightness + colour temperature.
  Recorded as ADR 0002 (display) and ADR 0005 (frontlight driver).
- Corrected the earlier 2.13" assumption; grew the board outline.

### Open questions
- Enclosure + battery capacity (sets charge current, board outline, button
  placement).
- microSD: keep, or rely on on-module flash?

## 2026-09-05 — EPD panel datasheet received (GDEY0426T82-FL01C)

- Owner supplied the panel datasheet. Confirms **GDEY0426T82-FL01C**:
  4.26" 800×480, controller **SSD1677**, 4-wire SPI, 24-pin 0.5 mm FPC;
  active area 92.8 × 55.68 mm; module outline 105.33 × 62.37 × 1.8 mm.
- Locked the **24-pin EPD FPC pinout** and the **SSD1677 external DC-DC**
  reference circuit (L 47 µH / Q Si1308EDL / D×3 MBR0530 / R 2.2 Ω sense +
  1 M pulldown / caps ≥25 V), fed from +3V3. Rails: VGH≈+20, VGL≈−20,
  VSH≈+15, VSL≈−15, VCOM≈−2 V.
- The module's mechanical drawing shows the **same dual (cold+warm) 6-pin
  frontlight** as FL0426-S01C → dual-driver design (ADR 0005) confirmed.
- Updated DESIGN.md §5, BOM (J4 24-pin + boost parts), the SKiDL generator
  (real EPD block), and ADR 0002. Verification table: EPD FPC now ✅.

## 2026-09-05 — Tooling note

- The web/CI container has no KiCad, so ERC/DRC/routing can't run here.
  Added a GitHub Actions workflow using the `kicad/kicad:8.0` image to run
  `kicad-cli` ERC/DRC and export gerbers on push — the persistent
  "KiCad-capable environment". Interactive capture/layout is done locally
  in KiCad 8.

## 2026-09-05 — Branch merge + design comparison

Merged `claude/schematics-pcb-review-rq1i2t` into `main` (the
`colophon-standard-compliance` branch had no unique commits). Main now holds
two design tracks; **`ereader.*` (Rev C) is canonical**.

Comparison — first-try board (`ereader.*`) vs the `hardware/` reference spec:

| Area | ereader.* (Rev C, canonical) | hardware/ (reference spec) |
|---|---|---|
| MCU | ESP32-S3-WROOM-1-**N16R8** | ...-N8R2 (same family) |
| Charger | **BQ25628E** I2C buck 2A, SoC-managed 80/50 | MCP73831 linear 500 mA |
| 3V3 reg | **TPS62840** buck (60 nA Iq) | AP2112 LDO |
| Fuel gauge | **MAX17048** ModelGauge (I2C) | resistor divider → ADC |
| Frontlight | **LM3630A** single-boost/dual-sink (I2C) | 2× TPS61165 (2 inductors) |
| Input | 3 buttons + **rotary encoder** | 3 buttons |
| EPD | SSD1677 24-pin + boost ("copy ref schematic") | SSD1677 24-pin + boost **with exact values** |
| USB ESD | USBLC6-2 (placed) | USBLC6-2 (recommended) |
| PCB | **real: 56 fp, 237 nets, 4-layer, placed/planed/stitched, DRC-ruled, NOT routed** | scaffold outline only |
| Compliance | detailed FCC/CE + magnet/phone-attach analysis | notes |
| Fab | `fab.py` + `ereader-gerbers.zip` | CI (`kicad-cli`) |

Verdict: `ereader.*` is more advanced and is the real board → **canonical**.
`hardware/` keeps value only as (a) the CI, now retargeted to
`ereader.kicad_pcb`; (b) repo hygiene (Colophon cleanup, e-reader docs);
(c) the **exact SSD1677 boost values** worth porting into
`ereader-pcb-design.md` §6.

Recommended consolidation (deferred to owner): adopt Rev C parts as
canonical (write a superseding ADR; my `docs/adr/0003` power + `0005`
frontlight describe the simpler variant), fold the SSD1677 boost values
into `ereader-pcb-design.md`, then remove the `hardware/` scaffold KiCad
files and remaining cruft (`.history`, `ereader-gerbers.zip`).

## 2026-09-06 — Consolidation executed (single project + ADRs reconciled)

- Removed the `hardware/` scaffold KiCad project (`mini-ereader.*` + empty
  lib tables). The board is now a single canonical KiCad project, `ereader.*`
  at the repo root; `hardware/` keeps only the electrical source-of-truth
  docs. Docs/runbook/CI/ADR-0002 references retargeted.
- Reconciled the ADRs to the Rev C parts: **0006** (I2C-managed power path —
  BQ25628E + TPS62840 + MAX17048, two I2C buses) supersedes **0003**;
  **0007** (LM3630A single-boost dual-sink frontlight) supersedes **0005**.
  0003/0005 marked Superseded, reasoning preserved.
- The `-N16R8` module variant is treated as a selection under ADR 0001, not a
  new decision. Also added **0008** (navigation input: 3 side buttons + ALPS
  SLLB510200 lever switch — CW/CCW/press, not a quadrature encoder).
- Folded the exact SSD1677 external DC-DC values (L 47 µH, Q Si1308EDL,
  D×3 MBR0530, R 2.2 Ω sense + 1 M pulldown, 4.7 µF/1 µF ≥25 V caps, rails
  VGH/VGL/VSH/VSL/VCOM) from `hardware/DESIGN.md` §5 into
  `ereader-pcb-design.md` §6, so the canonical spec is self-contained.
- Removed the committed `ereader-gerbers.zip` build artifact (regenerable via
  `fab.py`; already git-ignored).
- Fixed the panel part-number prefix in the `ereader-*` docs: **GDEQ0426T82 →
  GDEY0426T82** (`ereader-pcb-design.md`, `ereader-README.md`,
  `ereader-connection-list.md`, `ereader-footprints.md`), matching the panel
  datasheet confirmed in README/`DESIGN.md` (GDEY0426T82-FL01C). No
  consolidation items remain open.

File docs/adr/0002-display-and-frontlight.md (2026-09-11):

# Decision 0002: 4.26" 800×480 E-Paper with a laminated tunable frontlight

**Status:**      Accepted
**Date:**        2026-09-05
**Supersedes:**  (supersedes the earlier 2.13" assumption made before the
panel was known)

## Context

An e-reader needs a persistent, sunlight-readable display — E-Paper — and,
to be usable in the dark, a **frontlight** (light laminated *in front of*
the reflective panel, never a backlight). The physical size is set by the
frontlight datasheet the owner supplied: **Good Display FL0426-S01C**, a
frontlight built for a **4.26", 480×800-dot EPD**, LGP 61.40 × 104.10 mm.

The frontlight provides two independently driven LED channels for
colour-temperature control:

- **Cold:** 5 white LEDs in **series**, VF ≤ 15 V, IF ≤ 15 mA
- **Warm:** 5 white LEDs in **series**, VF ≤ 15 V, IF ≤ 15 mA
- 6-pin 0.5 mm FPC: 1 = LEDC+, 2 = LEDC−, 3 = NC, 4 = NC, 5 = LEDW+,
  6 = LEDW−

The matching display is confirmed by the owner's second datasheet as the
**Good Display GDEY0426T82-FL01C** — 4.26" 800×480 mono E-Paper, controller
**SSD1677**, 4-wire SPI, 24-pin 0.5 mm FPC, with the frontlight laminated
on (integrated module). Storage: on-module flash, removable microSD, or
both.

## Decision

Target the **Good Display GDEY0426T82-FL01C** (4.26" 800×480, SSD1677,
4-wire SPI) with its integrated dual-channel frontlight, driven by a dual
constant-current boost driver ([Decision 0005](./0005-frontlight-driver.md)).
The SSD1677 needs an external DC-DC (inductor + N-FET + Schottkys + sense
resistor) per the datasheet reference circuit. Include a **microSD (SPI)**
socket as an *optional*, depopulatable part; on-module flash is the default
store.

## Considerations

**Pro:** 4.26"/800×480 is a genuinely readable page size while staying
"mini"; SPI panels are well-supported; the frontlight makes it usable in
the dark with adjustable warmth — a premium feature at low cost.

**Con:** The panel is larger (bigger board, more current) and the SSD1677
needs its own external DC-DC (inductor + N-FET + Schottkys + sense R) for
the ±20 V gate / ±15 V source rails; the frontlight needs a separate ~15 V
boost driver (see 0005). Two switching subsystems to keep quiet near the
antenna and ADC.

Rejected: **2.13" SPI EPD** (original assumption — too small, and does not
match the supplied frontlight); **no frontlight** (unusable in the dark,
and the owner supplied a frontlight); **SD-only storage** (unnecessary
when on-module flash already holds a large text library).

## Consequences

- Board outline grows to fit the 105.33 × 62.37 mm display module
  (`ereader.kicad_pcb` outline ~66 × 115 mm; match
  to the final enclosure).
- A frontlight subsystem is required (connector J5 + dual boost driver);
  see [Decision 0005](./0005-frontlight-driver.md).
- An SSD1677 external DC-DC is required (J4 pins GDR/RESE + L2/Q2/D4-D6 +
  ≥25 V caps), fed from +3V3, per the datasheet reference circuit
  (`ereader-pcb-design.md` §6).
- **Resolved:** the full 24-pin EPD FPC pinout and controller are locked
  from the GDEY0426T82-FL01C datasheet (`ereader-pcb-design.md` §6).
- EPD and microSD share one SPI bus; EPD is write-only (no MISO), SD needs
  MISO + pull-ups.
- Firmware brings up the panel with a controller driver matched to the
  panel's waveform/LUT.

## Reconciliation note (Rev C — non-normative erratum, 2026-09-11)

The decision above stands, but its **designators predate the Rev C board** and
must not be read literally — the canonical designators live in
`ereader-connection-list.md` / `ereader-kicad.net`:

- EPD panel FPC = **J2** (this ADR's prose says "J4"); frontlight FPC = **J3**
  (prose says "J5"); the 1S Li-Po = **J5**; microSD = **J4**.
- The SSD1677 external DC-DC parts are now captured as **LE / QE / DE1–DE3 /
  RE1 / RE2 / CE1–CE9** (this ADR's "L2/Q2/D4-D6" was placeholder naming; note
  `L2` in Rev C is the *frontlight* boost inductor, not the EPD one).

No decision is changed here — only the part references are mapped to the built
design so the ADR can't be misread during the remaining EPD-booster work.

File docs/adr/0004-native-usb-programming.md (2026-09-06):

# Decision 0004: Program over native USB, no UART bridge or auto-reset circuit

**Status:**      Accepted
**Date:**        2026-09-05

## Context

ESP32 boards traditionally add a USB-UART bridge (CP2102/CH340) plus a
two-transistor auto-reset circuit driven by DTR/RTS, so a host can flash
and reset without touching buttons. The ESP32-S3, however, has a **native
USB peripheral (USB-Serial-JTAG)** that exposes a serial/JTAG interface
directly and supports host-initiated download — no bridge chip needed.

## Decision

Connect USB-C D+/D− straight to the ESP32-S3 (GPIO20/GPIO19). Provide plain
**BOOT (GPIO0)** and **RESET (EN)** buttons with pull-ups. **Omit** the
USB-UART bridge and the DTR/RTS auto-reset transistor pair.

## Considerations

**Pro:** Fewer parts (no bridge IC, no transistor pair), less board area,
lower cost; JTAG debugging over the same USB port; one connector for power,
data, and debug.

**Con:** No classic DTR/RTS auto-reset, so some toolchains may need a manual
bootloader entry (hold BOOT, tap RESET) if auto-download misbehaves; relies
on the native-USB stack being healthy in firmware.

Rejected: **CP2102 + auto-reset** — the familiar path, but redundant on the
S3 and pure added cost/area. Reconsider only if a variant must present a
legacy COM port with hardware auto-reset for a fixed toolchain.

## Consequences

- BOM drops the bridge IC and two transistors + resistors.
- USB D± must still be routed as a ~90 Ω differential pair and protected
  (USBLC6-2 ESD recommended).
- Bring-up docs note the manual bootloader gesture as a fallback.
- GPIO19/20 are reserved for USB and excluded from the peripheral pin map.
- The physical BOOT/RESET contacts started as tactile switches and were
  replaced with bare jumper pads in Rev C3 — see
  [Decision 0008](./0008-navigation-input.md) for the current implementation
  (`JP5`/`JP6`, screwdriver/tweezer-shortable). This ADR's "buttons" language
  describes the original implementation; the architectural call it documents
  (plain GPIO0/EN triggers, no UART bridge, no auto-reset circuit) is
  unaffected by that change.

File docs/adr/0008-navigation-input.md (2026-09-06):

# Decision 0008: Navigation input — 3 side buttons + a lever switch

**Status:**      Accepted
**Date:**        2026-09-06

## Context

The reader needs navigation input — page forward/back, menu, scroll, select —
and it must work from deep sleep: the device sleeps with the page retained in
the µA range (README non-functional baseline), so every input has to be able
to wake the ESP32-S3. No prior ADR covered input; the earlier reference spec
(the since-removed `hardware/` lineage) assumed three buttons, while the
canonical board (`ereader.*`, Rev C) settled on a richer scheme. This
decision documents that
scheme.

The tension is affordance vs. cost/pins. Plain buttons are cheap, obvious,
and trivially wake-capable, but paging through a long library or menu with
two or three buttons is clunky. A scroll-and-select control fixes that, but a
true quadrature rotary encoder adds A/B decode, rotational travel/mechanics,
and more firmware. A middle option — a multi-directional lever switch — gives
CW/CCW/press as three ordinary momentary contacts, no quadrature decode.

## Decision

Use **three side tactile buttons** (SW1–SW3: page/menu) plus **one ALPS
SLLB510200 multi-directional lever switch** (SW4: CW / CCW / press). All are
active-low momentary contacts to GND with pull-ups, each on an **RTC-capable
GPIO** so any can wake the S3 from deep sleep. Firmware debounces and decodes
them (no hardware quadrature). BOOT (JP5→GPIO0) and RESET (JP6→EN) remain for
native-USB programming/recovery (see
[Decision 0004](./0004-native-usb-programming.md)) — as of Rev C3 they're bare
exposed jumper pads rather than tactiles, momentarily shorted with a
screwdriver tip or tweezers, since that recovery path is used rarely enough
that a dedicated switch part isn't worth the BOM cost or the accidental-press
risk of a labelled button sitting on the case.

## Considerations

**Pro:** The lever gives one-handed scroll (CW/CCW) + select (press) in a
single part while the three side buttons cover page-forward/back/menu; every
input is a simple momentary contact (debounce in firmware, no encoder decode);
all sit on RTC GPIOs, so any is a deep-sleep wake source — matching the µA
sleep budget; low BOM cost and only six GPIOs for the whole navigation set.

**Con:** The SLLB510200 is a specific ALPS part (sourcing + footprint risk;
small 9.5 × 8.8 × 2.2 mm SMD; contacts rated 10 mA / 5 V — signal-level only);
six inputs consume six GPIOs; waking on several pins needs `ext1`-mask setup;
a lever is less self-evident than labelled buttons.

Rejected:
- **Three buttons only** (the reference spec) — simplest, but no scroll/select
  affordance; long menus and the library list are tedious.
- **A true quadrature rotary encoder** — finer scroll resolution, but needs
  A/B decode, more mechanics/travel, and more firmware; the lever covers
  CW/CCW/press with three plain contacts for less.
- **Capacitive touch / touchscreen** — out of scope (README non-scope) and
  adds cost and standby power.

## Consequences

- Add **SW1–SW3** (side tactiles) and **SW4** (ALPS SLLB510200). Pin map:
  `BTN_A`=GPIO4, `BTN_B`=GPIO5, `BTN_C`=GPIO6; `LEV_CW`=GPIO1,
  `LEV_CCW`=GPIO2, `LEV_PUSH`=GPIO15 — all pull-up, RTC-wake
  (`ereader-pcb-design.md` §5).
- All six are RTC-capable wake sources: assign `BTN_A` + `LEV_PUSH` as the
  primary wakes and `ext1`-mask the rest.
- `LEV_PUSH` takes GPIO15 — one reason the frontlight moved to I2C control,
  freeing the LEDC pins 0005 had reserved; see
  [Decision 0007](./0007-lm3630a-frontlight-driver.md).
- The 10 mA / 5 V contact rating is signal-level only (GPIO + pull-up) — do
  not switch any power rail through the lever.
- Firmware provides debounce and CW/CCW/press decode; no hardware quadrature
  or encoder peripheral is used.
- Sourcing: verify SLLB510200 stock before order. **SLLB510100** is a
  pin-compatible alternative in the same SLLB5 series (same 9.5×8.8×2.2 mm
  envelope and CW/CCW/PUSH/COM terminals) — swap the value if it sources better.
- **Footprints (Rev C2):** the three nav tactiles use a genuinely
  **side-actuated** land, `ereader:WE_WS-TASU_436351045816` (Würth WS-TASU
  436351045816, 4.7×3.5 mm side push), drawn from the WE datasheet — 4 pads
  1.2×0.7 mm + two Ø0.75 boss holes — with the actuator facing the board edge. The
  earlier `SW_SPST_TL3342` stand-in was **top-actuated**, unusable here because the
  screen covers the whole front and magnets hold the back to the phone. SW4 uses
  `ereader:ALPS_SLLB5_Lever`, drawn from the ALPS SLLB5 datasheet (4 signal pads on
  2 mm pitch in CW/COM/PUSH/CCW order + two Ø1.1 locator holes + solder lugs), so
  `LEV_CW/CCW/PUSH` and `COM→GND` connect on netlist import instead of sitting
  unconnected. Both lands are drawn from the datasheets but still to be DRC'd against
  the ordered part before route/fab; tune SW4's placement/orientation to the
  enclosure edge.
- **BOOT/RESET → bare jumper pads (Rev C3).** SW5/SW6 (the Würth tactiles on
  BOOT/RESET) are replaced by `ereader:JumperPad_2P_P2.0mm` under refs `JP5`/`JP6`:
  two 1.2×1.2 mm exposed pads on 2 mm pitch, no switch part, at the same board
  location the tactiles occupied. Short the pair momentarily with a screwdriver tip
  or tweezers to pull `IO0_BOOT`/`EN` low; open circuit otherwise. Hand-drawn
  geometry (no datasheet to check against, since there's no part to order) — DRC
  the pad spacing against fab minimum clearance and confirm the case cutout still
  reaches them before fab.

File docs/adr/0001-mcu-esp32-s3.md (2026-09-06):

# Decision 0001: Use ESP32-S3-WROOM-1 as the MCU

**Status:**      Accepted
**Date:**        2026-09-05

## Context

A mini e-reader must render text to an E-Paper panel, drive a frontlight,
and — to be useful — fetch books over the network. That argues for an MCU
with wireless, enough RAM to hold an 800×480 framebuffer and decompress
text, native USB for programming without an extra bridge chip, and a large
hobbyist/tooling ecosystem. Candidates: ESP32-S3, RP2040, nRF52840.

Constraints for v0.1: a certified pre-made RF module (no custom RF layout),
solderable by hand or low-cost assembly, and driveable from Arduino /
ESP-IDF / MicroPython with existing E-Paper libraries.

## Decision

Use the **ESP32-S3-WROOM-1** module (N8R2 baseline: 8 MB flash, 2 MB
PSRAM; N16R8 as a drop-in upgrade).

## Considerations

**Pro:** Wi-Fi + BLE on-module and pre-certified; PSRAM comfortably holds
an 800×480 framebuffer and decompression buffers; native USB
(USB-Serial-JTAG) removes the CP2102/CH340 bridge; broad library support
(GxEPD2/epdiy) for E-Paper; cheap and widely stocked; plenty of GPIO/PWM
(LEDC) channels for the frontlight.

**Con:** Higher active/Wi-Fi-TX current than an nRF52 (peaks ~500 mA on
TX), which stresses the power path; the module antenna keep-out constrains
layout.

Rejected: **RP2040** — no wireless (needs a co-processor for sync), which
defeats "fetch books". **nRF52840** — excellent low power and native USB,
but BLE-only wireless is awkward for downloading books and its RAM is
tight for an 800×480 framebuffer; revisit for an ultra-low-power,
sideload-only variant.

## Consequences

- Power path must tolerate 500 mA bursts; bulk decoupling sized accordingly
  ([Decision 0003](./0003-power-architecture.md)).
- Layout must honour the module antenna keep-out (module at board edge,
  no copper under antenna).
- Programming/reset assumes native USB
  ([Decision 0004](./0004-native-usb-programming.md)).
- Two LEDC/PWM pins are reserved for the frontlight
  ([Decision 0005](./0005-frontlight-driver.md)).
- The pin map in `ereader-connection-list.md` / `ereader-pcb-design.md`
  avoids strapping pins and on-module flash/PSRAM pins (26–37).

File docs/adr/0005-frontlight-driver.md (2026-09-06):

# Decision 0005: Dual constant-current boost driver for the frontlight

**Status:**      Superseded by [Decision 0007](./0007-lm3630a-frontlight-driver.md)
**Date:**        2026-09-05

> Superseded 2026-09-06: the canonical board (`ereader.*`, Rev C) uses a
> single LM3630A dual-string driver (one boost + two current sinks) instead
> of two TPS61165 boosts. See
> [Decision 0007](./0007-lm3630a-frontlight-driver.md). The Context and
> reasoning below are preserved as the trail.

## Context

The chosen frontlight (Good Display FL0426-S01C,
[Decision 0002](./0002-display-and-frontlight.md)) has two independent LED
channels, each **5 white LEDs in series**: **VF ≤ 15 V, IF ≤ 15 mA**. To
control both brightness and colour temperature, each channel must be driven
at a regulated constant current, dimmable independently, from a battery/USB
rail of only 3.0–5.0 V — well below the ~15 V the string needs. So the
driver must **boost** and **regulate current**, per channel.

Options: (a) two single-channel WLED boost drivers; (b) one boost to ~16 V
plus two low-side constant-current sinks; (c) an integrated dual/multi-
channel LED driver.

## Decision

Use **two TPS61165 WLED boost drivers** (one per channel), input from VSYS,
output a regulated LED current set by a sense resistor, dimmed by **PWM on
each driver's control pin from two MCU LEDC pins** (FL_COLD_PWM = GPIO15,
FL_WARM_PWM = GPIO16). Set LED current with R_SET = 0.2 V / I_LED
(≈ 13 Ω for 15 mA; start lower, e.g. 10 mA, and tune).

## Considerations

**Pro:** Each channel is fully independent (true colour-temperature mixing
by ratioing the two PWM duties); TPS61165 integrates the switch and current
regulation, needing only L + Schottky + Cout + Cin + R_SET; PWM dimming maps
directly onto the ESP32-S3 LEDC peripheral; components are cheap.

**Con:** Two boost inductors (board area) and two switching nodes (EMI) that
must be kept away from the RF module and the battery-sense ADC; boost
efficiency and inrush to manage; the small SOT-23/WSON driver is fiddly to
hand-solder.

Rejected:
- **One boost + two linear current sinks** — saves an inductor but burns the
  headroom difference as heat in the sinks and still needs two control loops;
  revisit if area beats efficiency.
- **Integrated dual-channel LED driver** — cleanest in principle, but common
  parts target higher-current backlights or RGB; kept as a future
  consolidation if a suitable ≤15 mA, ~16 V dual driver is sourced.
- **Direct/parallel drive from 3.3 V** — impossible; the series string needs
  ~15 V.

## Consequences

- Add connector **J5** (6-pin 0.5 mm FPC) wired to the FL0426-S01C pinout;
  route LEDC+/− and LEDW+/− to their respective drivers, NC pins left open.
- Reserve two ESP32-S3 LEDC pins (GPIO15, GPIO16) for PWM dimming.
- Frontlight draws from **VSYS** (not +3V3); budget ~0.15 A input at full
  brightness (both channels).
- Layout: keep both boost stages and their inductors in one corner, away
  from the antenna and BAT_SENSE; local ground pour and short switch loops.
- **Confirm the LED electrical spec** (VF, IF, series count) against the
  full FL0426-S01C datasheet before finalising R_SET and the boost Cout
  voltage rating (≥ 20 V).

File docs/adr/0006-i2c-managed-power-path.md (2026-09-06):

# Decision 0006: I2C-managed power path — BQ25628E charger, TPS62840 buck, MAX17048 gauge

**Status:**      Accepted
**Date:**        2026-09-06
**Supersedes:**  [Decision 0003](./0003-power-architecture.md)

## Context

[Decision 0003](./0003-power-architecture.md) chose the minimal discrete
power path — MCP73831 linear charger (PROG-set 500 mA), a discrete P-FET +
Schottky load-share, an AP2112K-3.3 LDO, and a resistor divider to an ADC
for battery sense — to get an openable board quickly. The actual board
(`ereader.*`, Rev C) that is now the canonical KiCad project took a
different route across the whole power/telemetry chain, and it is the real,
placed design. The ADRs must reconcile to it.

Three forces drove the change. The LDO wastes the 3.0–3.4 V battery tail and
the divider gives only coarse state-of-charge; the design instead wants to
use the full cell and read accurate SoC. Charge behaviour should be
firmware-managed (charge-cap hysteresis for cell longevity), not fixed by a
PROG resistor. And the deep-sleep µA budget (README non-functional baseline)
favours a nanoamp-Iq buck over an LDO's quiescent draw plus an always-on
sense divider.

## Decision

Charge with **TI BQ25628E** (1S I2C buck charger, up to 2 A; addr 0x6B on
I2C0), firmware-managed via `EN_CHG` (stop at 80 % SoC, resume at 50 %), with
a hardware **`CE` pin on GPIO14** (100 kΩ strap = charge-on default) as the
fail-safe and dead-battery power-up path. Regulate SYS→3.3 V with **TI
TPS62840** buck (750 mA, 60 nA Iq). Read state-of-charge with **Maxim
MAX17048** ModelGauge (addr 0x36, no sense resistor; `/ALRT`→GPIO48). Run
two I2C buses to break the MAX17048-vs-LM3630A 0x36 address clash: **I2C0** =
charger + gauge, **I2C1** = the frontlight driver (see
[Decision 0007](./0007-lm3630a-frontlight-driver.md)).

## Considerations

**Pro:** The buck uses the whole 3.0–4.2 V cell instead of stranding the
tail; ModelGauge gives accurate SoC with no sense resistor; firmware-set
charge caps extend pack life; ~60 nA Iq slashes deep-sleep drain; BQ25628E
integrates a power path (run-while-charging), JEITA/thermal regulation, and
headroom to 2 A for a larger cell.

**Con:** Two more I2C devices plus a second bus (firmware, four pull-ups,
extra pins); a switching charger and buck add EMI to manage near the RF
module and the gauge; the parts cost more and are finer-pitch than the
discrete path; the shared 0x36 address forces the second bus.

Rejected:
- **Keep the 0003 path** (MCP73831 / AP2112 / divider) — simpler and
  cheaper, but strands the battery tail, gives coarse SoC, and cannot do
  SoC-managed charge caps.
- **Single I2C bus** with a BQ27441-G1A gauge (@0x55) — avoids the second
  bus but needs a sense resistor; kept only as a forced fallback.

## Consequences

- **I2C0** (SDA GPIO17 / SCL GPIO18): BQ25628E 0x6B + MAX17048 0x36.
  **I2C1** (SDA GPIO16 / SCL GPIO38): LM3630A. 4.7 kΩ pull-ups per bus.
- GPIO14 = `CHG_CE` (100 kΩ strap, charge-on default); GPIO47 = `CHG_INT`;
  GPIO48 = `GAUGE_ALRT` (low-SoC wake → graceful shutdown).
- Firmware implements the 50↔80 % charge state machine (hysteresis stops
  chatter); default is charge-on before firmware runs, for dead-battery
  recovery. Ichg set conservative (~0.3–0.5C) by register; optional VREG
  4.10–4.15 V for longevity.
- The 3.3 V rail must survive the S3 TX burst (~0.5 A): TPS62840 (750 mA) +
  22 µF bulk at the module 3V3 pins.
- Layout: keep the charger buck loop tight with the input cap at VBUS, and
  hold both switch nodes away from the antenna and BAT_SENSE. Detail in
  `ereader-pcb-design.md` §4 (power tree) and §8 (charging + SoC).
- The frontlight boost draws from VBAT/SYS, not +3V3 (unchanged from 0003).
- MCU note: Rev C uses the **-N16R8** variant of the module chosen in
  [Decision 0001](./0001-mcu-esp32-s3.md) (16 MB flash / 8 MB PSRAM, for
  OTA A/B + the 800×480 framebuffer + fonts). That is a variant selection
  under 0001, not a new decision.

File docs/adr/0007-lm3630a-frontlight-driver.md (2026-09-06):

# Decision 0007: LM3630A single-boost dual-sink frontlight driver

**Status:**      Accepted
**Date:**        2026-09-06
**Supersedes:**  [Decision 0005](./0005-frontlight-driver.md)

## Context

[Decision 0005](./0005-frontlight-driver.md) chose two TPS61165 WLED boost
drivers (one per channel), PWM-dimmed from two ESP32-S3 LEDC pins. It was
sound but assumed each channel needed its own boost. The canonical board
(`ereader.*`, Rev C) took a different route, and the ADRs must reconcile to
it.

The frontlight topology is now confirmed from the FL0426-S01C drawing
([Decision 0002](./0002-display-and-frontlight.md), Rev C §7): two
**independent 4-wire** series strings — cool and warm, **5 LEDs each**,
VF ≤ 15 V, IF ≤ 15 mA, equal length, sharing nothing (not common-anode).
Equal-length strings mean a *single* boost can feed both anodes while two
current sinks regulate each string independently — exactly what an
integrated dual-string LED driver provides, which 0005 had rejected only
because no suitable ≤15 mA / ~16 V dual part was sourced at the time.

## Decision

Drive the frontlight with **TI LM3630A** (I2C dual-string backlight boost,
addr 0x36 on **I2C1**): one boost `OUT` feeds both string anodes (FL pin 1
C+, pin 5 W+), and the two integrated current sinks — Bank A = cool at FL
pin 2 C−, Bank B = warm at pin 6 W− — regulate each string. Per-bank Iset
≤ 15 mA and per-bank brightness are set over I2C1; **`FL_HWEN` on GPIO21**
(100 kΩ pull-down = off at boot) is the hard standby cut. OVP ≥ 18 V.

## Considerations

**Pro:** One inductor and one switch node instead of two — less board area
and one fewer EMI aggressor near the antenna and FPCs; the integrated dual
sink gives true per-channel current regulation and independent cool/warm
brightness for colour-temperature blend; I2C control frees the two LEDC pins
0005 reserved; equal string lengths make the shared boost efficient (it
regulates to the active sink).

**Con:** Adds a device to I2C — and because the LM3630A is 0x36 it clashes
with the MAX17048, forcing the second I2C bus (see
[Decision 0006](./0006-i2c-managed-power-path.md)); dimming is firmware over
I2C, not a raw LEDC pin; boost OVP and inrush must be managed; a single boost
is a shared point of failure for both channels (two independent boosts were
not).

Rejected:
- **Two TPS61165 boosts** (0005) — more area and two switch nodes for no
  functional gain now that the strings are confirmed equal-length.
- **One boost + two discrete linear sinks** — the LM3630A integrates exactly
  this in one part.
- **Direct/parallel drive from 3.3 V** — impossible; the series string needs
  ~15 V.

## Consequences

- Connector **J3** (6-pin 0.5 mm FPC): 1 C+ / 2 C− / 3 NC / 4 NC / 5 W+ /
  6 W−; both anodes to boost `OUT`, cathodes to the LED1/LED2 sinks. (This is
  J3 in `ereader-pcb-design.md` §3/§7; it was labelled J5 in 0005.)
- **I2C1** (SDA GPIO16 / SCL GPIO38) carries the LM3630A at 0x36; GPIO21 =
  `FL_HWEN` (100 kΩ pull-down). This frees GPIO15/16 that 0005 reserved for
  PWM — on Rev C, GPIO16 is now I2C1_SDA and GPIO15 is the encoder push.
- Frontlight draws from VBAT/SYS, not +3V3; set OVP ≥ 18 V (5 × 3.6 V) and
  per-bank Iset conservative, then tune.
- Layout: boost L + Cout loop < 5 mm with local ceramics, far from the
  antenna and the FPCs. Detail in `ereader-pcb-design.md` §7 and §11.
- ADR 0005 marked Superseded by this decision.

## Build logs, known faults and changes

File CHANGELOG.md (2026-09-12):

# Changelog

All notable changes to the Mini E-Reader project. Format loosely follows
[Keep a Changelog](https://keepachangelog.com/); dates are ISO-8601.

## [Unreleased]

### SKiDL netlist generator to resolve the pin-name↔pad-number wall (2026-09-12)
Importing the hand-authored `ereader-kicad.net` into Pcbnew threw 56 "pad *X*
not found in footprint" errors: the netlist names IC pins by function while
footprints use numbered pads, and with no symbol layer KiCad can't map them.
- Added **`gen_netlist.py`** — a SKiDL generator that rebuilds the netlist from
  real symbols, so each pin carries its datasheet pad number and the output
  imports cleanly. It encodes all 53 nets verbatim from
  `ereader-connection-list.md`; a `CFG` block at the top holds the non-stock
  symbols (U2-U5, J2, SW4) for the user to point at SnapEDA/`ereader.kicad_sym`.
  Runs ERC and writes `ereader-kicad.net`.
- Also surfaced two latent gaps now flagged in the script's "KNOWN ITEMS TO
  VERIFY": `U5.EN` was never wired (added → +3V3, always-on) and `U5.FB` is
  left for the user to set per the fixed-vs-adjustable TPS62840 variant.
- Documented as capture route 0 in the runbook; the by-hand Eeschema route
  (`docs/schematic-capture.md`) remains for a visual schematic. Both fix the
  same root cause. `gen_netlist.py` is syntax-checked here; functional
  validation is the user's first run (SKiDL's build deps don't compile in the
  cloud CI sandbox), which surfaces any symbol/pin-name mismatch to iterate on.

### Fab preflight gate + honest CI, after a routed board reached main out of sync (2026-09-12)
The board was routed and pushed to `main` (commit `board routed and gerber file
generated incl. DRC report`), but it was routed **before** *Update PCB from
Netlist* was run, so the 19 Rev C4 parts never landed on it. Analysis of that
commit:
- **Board ≠ netlist.** The routed `ereader.kicad_pcb` carries the original 56
  footprints; the EPD external DC-DC block (LE/QE/DE1-3/RE1-2/CE1-9) and the
  decoupling caps (CGA/CGB/C4I) added to `ereader-kicad.net` in Rev C4 are
  **absent**. The EPD panel therefore still has no boost/charge-pump and cannot
  display. `kicad-cli` DRC does not compare board vs netlist, so it stayed
  silent about this.
- **Placeholder footprints still in place.** U2 is still on the wrong 24-pin
  QFN 4x4 (BQ25628E is 18-pin WQFN 2.5x3.0) and U5 on the oversized SON-8 3x2
  (should be VSON-HR 2x2). Traces route to lands the real parts do not fit.
- **DRC (CI, KiCad 10.0.0, --refill-zones):** 0 violations, 0 footprint errors,
  **3 unconnected items** — all isolated `GND_F.Cu` pour islands at the antenna
  keepout corner (1, 8). Real (routing-induced): stitch to the GND plane or trim
  the pour. `unconnected_items` is `error` severity in this project.
- **Gerbers/DRC report were NOT committed** despite the message — `.gitignore`
  excludes `fab/`, `gerbers/`, `*.zip`; only the routed board was committed.
- Positives: routing is complete for the placed parts (0 pad-to-pad gaps), net
  classes were honored (Power 0.4mm, USB 0.25mm, default 0.2mm), and the antenna
  keepout is clean (0 copper in the band).

Fixes applied here (tooling/process — the board-layout fixes require KiCad and
are listed as the remaining manual steps):
- **`preflight.py`** — fails if any `ereader-kicad.net` component is missing from
  `ereader.kicad_pcb`. Closes the board/netlist parity gap kicad-cli can't see.
- **CI is now a hard gate** (`.github/workflows/kicad.yml`): runs `preflight.py`,
  then DRC with `--exit-code-violations` (no more `continue-on-error`), and only
  exports gerbers when both pass. CI will be **red until** the board is synced
  and the 3 GND islands are fixed — by design.
- **`fab.py`** refuses to emit gerbers from an out-of-sync board (override:
  `--force`).
- Remaining manual steps (KiCad): *Update PCB from Netlist* to place the 19
  parts; swap U2-U5 to the datasheet lands; place+route the EPD DC-DC block
  (tight boost loop, transcribe the interconnect + J2 FPC pins 1:1 from the
  Good Display reference); stitch/trim the 3 GND_F.Cu islands; re-run DRC.

### Rev C4 — capture the missing EPD DC-DC block, reconcile decoupling, correct IC packages, fix doc drift (2026-09-11)
Design-review pass before a possible manufacturing hand-off found several gaps
that would produce a non-working or non-buildable board. Addressed at the
netlist-first source-of-truth level (`ereader-kicad.net` drives the PCB on
re-import):

- **EPD SSD1677 external DC-DC now captured as real parts.** ADR 0002 /
  `ereader-pcb-design.md` §6 require an external boost + charge-pump for the
  panel's ±20V gate / ±15V source rails, but no such parts existed in the
  netlist/BOM/board — the panel could never have displayed. Added `LE` (47µH),
  `QE` (Si1308EDL N-FET), `DE1–DE3` (MBR0530), `RE1` (2.2Ω RESE sense), `RE2`
  (1MΩ GDR pulldown), `CE1–CE6` (4.7µF/25V rail reservoirs), `CE7–CE9`
  (1µF/25V), wired to J2's support pins (GDR/RESE/VGH/VGL/VSH1/VSH2/VSL/VCOM/
  VCI) with BS1 tied low for 4-wire SPI. **The diode/charge-pump interconnect,
  diode orientation, and J2 FPC pin numbers are a functional placeholder** —
  flagged in-file to be transcribed 1:1 from the Good Display reference before
  route (rail cap values non-negotiable, ≥25V).
- **Decoupling reconciled to spec.** Added the local caps the connection-list
  called for but that were missing: `CGA`/`CGB` (MAX17048 CELL 0.1µF+1µF),
  `C4I` (LM3630A IN 1µF).
- **IC package facts corrected** (verified against vendor datasheets): U2
  BQ25628E is an **18-pin WQFN 2.5×3.0mm (RYK)** — the placeholder
  `HVQFN-24-1EP_4x4mm` is the wrong pincount/size; U5 TPS62840DLCR is
  **VSON-HR 8-pin 2.0×2.0mm** — the placeholder `SON-8_3x2mm` is oversized (and
  it is not SOT-563); U4 LM3630A is DSBGA-only (no WSON variant). Netlist
  footprints left as import-clean placeholders; corrections documented in
  `ereader-footprints.md` so the right vendor land gets pulled.
- **Net classes extended:** the new EPD boost node + ±20V/±15V rails (EPD_SW,
  EPD_VGH/VGL, EPD_VSH1/VSH2/VSL, EPD_PREVGL) added to the `Power` class in
  `ereader.kicad_pro`.
- **Pin-map status clarified:** J4 microSD uses the DM3AT pad names so it maps
  on import; J2's function-name pins (incl. the new rails) still need the
  GDEY0426T82 FPC numbers from the datasheet — the one genuinely
  datasheet-blocked remap.
- **Doc drift fixed:** ADR 0002 got a non-normative Rev C reconciliation note
  (its J4/J5 and L2/Q2/D4-D6 designators predate Rev C); runbook bring-up step 6
  corrected (frontlight is LM3630A over I2C1 + FL_HWEN, not direct GPIO15/16 PWM).
- **Not changed:** routing (still 0 track segments — an RF+USB+switcher board
  whose compliance depends on hand/contractor layout, per the README ROUTING
  gate) and the vendor-exact U2–U5 lands (pull from SnapEDA/Ultra-Librarian).
  The new parts are in the netlist/`.cmp` but not yet placed on `.kicad_pcb`;
  re-import the netlist in KiCad to bring them onto the board.

### Found why the GUI kept showing the stale 3-entry GND_F.Cu result after the fix (2026-09-11)
- The board-level fix was confirmed correct twice over (a real KiCad 7.0.11
  `ZONE_FILLER` run locally, and CI forced to do a genuine from-scratch
  refill on KiCad 10.0.0 - see the two entries below), yet the project
  owner kept seeing the identical stale 3-entry `Zone 'GND_F.Cu'` report
  after every fix, including after fully quitting/reopening KiCad. Confirmed
  the report is generated via the KiCad GUI's own DRC dialog
  (Inspect -> Design Rules Checker), not `kicad-cli` or a CI artifact - so
  the CLI/CI proof didn't rule out something GUI-specific.
- Found it in KiCad's own source (`pcbnew/dialogs/dialog_drc.cpp`): the DRC
  dialog has a "Refill zones before performing DRC" checkbox
  (`m_cbRefillZones`), and its checked/unchecked state **persists across
  sessions** (`cfg->m_DrcDialog.refill_zones`), independent of the project
  file. If it was left unchecked from an earlier run, the dialog reuses
  whatever zone fill happens to already be in memory/on-disk instead of
  recomputing - so closing and reopening KiCad, or pulling new board
  changes, doesn't clear it. This is the same default-off behavior that
  `kicad-cli pcb drc` has (and that `--refill-zones` was added to this
  project's CI to work around, below).
- Action for the project owner: in the DRC dialog, check "Refill zones
  before performing DRC" before clicking "Run DRC". No further board
  changes were made in this entry - the board file itself has been correct
  since the keepout-zone fix two entries below.

### Confirmed the GND_F.Cu fix holds; the CI's pinned KiCad 8.0 was the actual source of the persistent false positive (2026-09-11)
- The previous entry's keepout-zone fix *did* work - the "3 unconnected_items
  between Zone 'GND_F.Cu' and itself" that survived three rounds of board
  fixes turned out to be a false positive specific to KiCad 8.0, not a real
  remaining board defect:
  - A `kicad-cli pcb drc --format json` run on a locally-installed KiCad
    10.0.0 (same version the project owner already runs locally) shows
    **zero** zone-related entries at all - every one of its ~60
    `unconnected_items` is a plain pad-to-pad gap on an unrouted signal net
    (`+3V3`, `I2C0_SDA`, `BTN_A`, `USB_DP`, `LEV_CW`, ... - expected, since
    this board has 0 routed track segments; it's placed but not routed, a
    separate later phase).
  - A `kicad-cli pcb drc` text-report run from this repo's CI - pinned to
    `kicad/kicad:8.0` - kept reproducing the exact same 3 zone entries,
    identical down to the anchor point, across every fix in this pass
    (pad nets, a 23-pad zone_connect sweep, the keepout removal). Two
    different KiCad major versions given the *identical* board file
    disagreeing this completely, with 10.0.0 matching what a ground-up
    KiCad 7.0.11 source read and engine test also predicted, points at an
    8.0-era zone-fill/connectivity bug, not the board.
- Repinned `.github/workflows/kicad.yml` from `kicad/kicad:8.0` to
  `kicad/kicad:10.0.0` so CI's DRC output matches what's actually
  authoritative for this board going forward.

### Remove a mis-scaled antenna keepout zone embedded in U1 that blocked GND fill outside the actual antenna area (2026-09-11)
- The previous pass's pad-level fixes (U1 EPAD net, broad zone_connect sweep)
  had zero effect on unconnected_items - still exactly 3, unchanged across
  three consecutive reports despite a from-scratch local refill confirming
  those fixes merge the zone into 1 island. Since nothing pad-level moved
  the number at all, went looking for something structural that no pad
  setting could route around.
- Found it: U1 (`ESP32-S3-WROOM-1`) carries its own footprint-embedded
  keepout zone (`copperpour not_allowed` on F.Cu/In1.Cu/B.Cu) with polygon
  `(9,6.25)-(57,6.25)-(57,-14.75)-(9,-14.75)` in the footprint's *local*
  frame. At U1's placement (33,13, no rotation) that's absolute
  x:42-90, y:-1.75-19.25 - 48x21mm, dwarfing the module's own ~18mm silk
  outline and running 24mm past the board's right edge and above the top
  edge. The real, documented antenna keep-out (the board-level "ANTENNA
  KEEPOUT" silk strip at y=0-7, full width) is already respected without
  this zone, since GND_F.Cu's own outline starts at y=8 - this extra zone
  only ate into the y=8-19.25 strip, which `ereader-pcb-design.md` explicitly
  wants as continuous ground ("Continuous GND plane under everything except
  antenna keep-out"). Almost certainly leftover data from whatever reference
  footprint this was built from, never rescaled for this board. Removed it.
- This exact keepout was present through every previous local KiCad 7.0.11
  refill test (all of which already showed 1 merged island), so it can't be
  blamed for anything observed locally - but keepout-vs-zone-fill clipping
  is exactly the kind of thing that could differ between the 7.0.11 engine
  available here and the CI's KiCad 8.0, and it's unambiguously a
  placement/scaling bug regardless of whether it's the cause. Re-filled and
  re-spliced the 3 GND zones after removing it - still 1 island, no
  regression.

### Harden every remaining thermal-relief GND pad to a solid zone connection (2026-09-11)
- hole_clearance and lib_footprint_mismatch are confirmed clear (0 DRC
  violations in the latest report). unconnected_items held steady at 3,
  unchanged by the previous pass's net/zone_connect fixes or the spliced-in
  fresh zone fill - strong evidence the CI's KiCad 8.0 zone-fill algorithm
  forms different islands than the KiCad 7.0.11 engine available in this
  sandbox for the *same* pad/net input, since a from-scratch refill in 7.0.11
  now shows a single, fully-merged island on every GND layer.
- Since the fill algorithm itself isn't reliably reproducible here, stopped
  trying to predict exactly which thermal-relief spokes a different KiCad
  version will or won't resolve, and instead removed the dependency:
  swept every GND-net copper/thru-hole pad on the board and gave the 23 that
  were still on default thermal relief a solid connection (`zone_connect 2`)
  - 6 previously-missed 0805 decoupling caps (CS/CF/CB/CU1/CI/CO), SW4's COM
    pad, JP5/JP6's pad 2, J5's pad 2, and all 13 copper features of U1's
    exposed pad/pin 41 (only 1 of which got a net at all in the previous
    pass). `zone_connect` is one of the fields `FootprintNeedsUpdate()`
    explicitly excludes from the library-parity comparison (confirmed in
    source), so this doesn't reopen the footprint-mismatch warnings that
    pass just cleared.
- Re-filled all 3 GND zones with KiCad 7.0.11's real `ZONE_FILLER` again
  after this change (still 1 island each - no regression) and spliced the
  fresh fill into the board file, same as last time.
- Still unverified against the actual `kicad-cli` 8.0 the CI runs - if
  unconnected_items persists after this, the next step is isolating which
  specific pad differs between the two engines' island formation, since
  broad-brush solid-fill sweeps don't have much further room to run.

### Fix remaining DRC errors and warnings, verified against the real KiCad 7 engine (2026-09-10)
- **Root-caused the previous pass's two open items by reading KiCad's own DRC source**
  (`pcbnew/drc/drc_test_provider_library_parity.cpp`, `drc_rule_parser.cpp`,
  `pcb_expr_evaluator.cpp`, `pad.cpp`) and cross-checking every fix against a
  locally-installed KiCad 7.0.11 (`kicad-cli`/`pcbnew` Python bindings aren't
  available in the normal sandbox - installed via apt for this pass only):
  - `FOOTPRINT::FootprintNeedsUpdate()` compares each pad's orientation
    *relative to its parent* (`pad->GetOrientation() - parent->GetOrientation()`),
    not the raw stored angle. KiCad's writer omits the `at` angle for pads
    where rotation doesn't change the rendered shape (circles, squares), but
    the parity check still computes a relative angle from whatever's stored
    (0) minus the footprint's placement rotation - so every omitted-angle pad
    in a rotated footprint instance compared as mismatched even though it
    looks identical on screen. Added the explicit matching angle (matching
    the footprint's own placement rotation, like the already-correct pads in
    the same instance) to: SW4's 2 locator NPTH holes (+90), SW1/SW2/SW3's 2
    boss NPTH holes each (+270), and JP5/JP6's 2 pads each (+270).
  - `FootprintNeedsUpdate()` also compares `descr` and `tags` verbatim - the
    board instances and the library copies had diverged wording for SW4
    (`ALPS_SLLB5_Lever`) and SW1-3 (`WE_WS-TASU_436351045816`). Re-synced the
    library text to the board's (shorter, already-accurate) copy. JP5/JP6
    (`JumperPad_2P_P2.0mm`) had board text hardcoded per-instance ("pull IO0
    low for BOOT" vs "...EN low for RESET") that can't simultaneously match
    one library description - genericized the library + both instances to
    "pull the associated signal low".
  - Verified via `FOOTPRINT.FootprintNeedsUpdate()` (the exact C++ method the
    DRC check calls) through Python bindings: all 6 previously-flagged
    footprints (SW1-4, JP5, JP6) now return `False`.
  - The `ereader.kicad_dru` custom rule from the previous pass used
    `(condition "A.Reference == B.Reference")`, but `Reference` is only
    registered as a property on `FOOTPRINT`, not `PAD` - on a pad the
    expression evaluates to an undefined value, so the condition never
    matched and the rule silently never applied (board setup's global
    0.25mm stayed in force). `PAD` instead registers `Parent` (returns the
    parent footprint's reference). Fixed to `(condition "A.Parent ==
    B.Parent")`. The `hole_clearance` constraint keyword itself was already
    correct (confirmed against `drc_test_provider_copper_clearance.cpp`,
    which is what actually emits this violation and whose implicit rule name
    - "board setup constraints hole" - matches the DRC report verbatim).
  - Re-filled all 3 GND zones with KiCad's real `ZONE_FILLER` to check
    whether the U1/J1 net fixes from the previous pass actually reconnected
    the copper: `GND_F.Cu` now fills as a single island (was 3 disjoint
    islands before those fixes), confirming the unconnected_items fix holds.
    Spliced the freshly-computed `filled_polygon` data for all 3 GND zones
    back into the hand-edited board file (surgical text replacement, not a
    full `pcbnew` re-save, to avoid KiCad 7's writer reformatting/reordering
    the rest of the file) so the committed fill isn't stale relative to the
    net/zone_connect changes.
  - Could not reproduce the exact `kicad-cli pcb drc` command the project's
    CI uses (KiCad 8.0): apt on this box only has KiCad 7.0.11, whose
    `kicad-cli` predates the `pcb drc` subcommand, and kicad.org/PPA hosts
    are blocked by this sandbox's egress policy. All of the above was cross-
    checked against KiCad 7.0.11's real DRC/library-parity source and engine
    instead - a real re-run in KiCad 8 is still worth doing to confirm.

### Fix remaining DRC errors and warnings: U1 EPAD net, J1 shield thermals, SW4 library parity, mechanical hole clearance (2026-09-08)
- **U1 (ESP32-S3-WROOM-1) exposed pad (pin 41/EPAD) wasn't actually on GND.**
  Of the 13 copper features that make up the module's exposed thermal pad
  (the 3.9x3.9mm SMD land plus its 12 small heatsink through-holes), only one
  through-hole carried `(net 5 "GND")` - the rest were floating, even though
  `ereader-connection-list.md` documents `U1.41(EPAD)` as GND. The floating
  copper forced the F.Cu GND zone to clear around most of the pad instead of
  merging with it, splitting the zone into a ~16x17mm island under U1 that
  DRC reported as 2 "unconnected_items" pairs (4 identical entries - KiCad
  lists each ratsnest edge both directions). Added the missing net to all 12
  pads.
- **J1 (USB-C) shield/mechanical pads (S1) starved their own thermal
  reliefs.** All 4 S1 pads were on GND with default (spoke) zone connection;
  one of them resolved to only 1 of the usual spokes on In1.Cu, leaving an
  isolated copper island (`starved_thermal`) - the same failure mode already
  fixed for J1's small SMD GND pads (A1/A12/B1/B12) in an earlier pass, just
  not extended to S1. Also pinched off a second, tiny F.Cu island right next
  to A12/B1 (the other 2 "unconnected_items" pairs). Gave all 4 S1 pads a
  solid zone connection (`zone_connect 2`), matching A1/A12/B1/B12.
- **SW4 (`ereader:ALPS_SLLB5_Lever`) library/board parity - actually fixed
  this time.** The previous "sync footprint library" pass edited the
  library's 2 corner solder-lug pad rotations from 45°/135° to 135°/225° to
  match the board's raw stored angle at SW4's 90° placement - but a pad's
  stored angle in the `.kicad_pcb` already bakes in the footprint's own
  rotation (angle = local + placement), so the *pre*-edit library values
  were the correct local design angles all along; the edit introduced a
  real 90° mismatch instead of fixing one. Reverted to 45°/135°. (SW1-3,
  JP5, JP6 already matched their library copies on inspection - the other 5
  `lib_footprint_mismatch` warnings in the last report look stale.)
- **SW4 hole-clearance errors (CW/COM/PUSH/CCW pads vs. the switch's own
  Ø1.1mm locator holes) are the ALPS SLLB5 datasheet land, not a placement
  bug** - the physical part puts signal pads as close as ~0.05mm from its
  own locator holes, under the board's global 0.25mm min hole clearance.
  Added `ereader.kicad_dru` with a custom rule that relaxes hole clearance
  to 0.02mm only between pads/holes sharing the same footprint reference,
  leaving the global rule intact for every other part on the board.

### 3D views: SW4 lever corrected + self-contained bodies for every component (2026-09-06)
- **SW4 (ALPS SLLB5) 3D body fixed.** The old `ereader.3dshapes/ALPS_SLLB5_Lever.wrl`
  rendered as a tall block with an upward box knob — an "odd big switch". The SLLB5 is
  actually a **flat semicircular "fan" puck** (W 9.5 × D 8.8 × **H 2.2 mm**, the
  datasheet Lever-Return family) that lies on the board with a **low sideways
  rocker/toggle lever** on top (flick left↔right = CW/CCW, press = PUSH). Rebuilt the
  body as the flat puck + sideways lever to match the ALPS datasheet drawing/photo.
- **The whole board now renders in the 3D viewer without KiCad's stock 3D libraries.**
  Every placed component previously pointed at stock `${KICAD6/7_3DMODEL_DIR}` packs,
  which go missing on any machine/CI without the KiCad 3D-model add-on — so most parts
  showed no 3D body. Added simplified project-local bodies for all remaining footprints
  (R/C/L passives, `SOT-23-6`, `SON-8`, `DFN-8`, `HVQFN-24`, `ESP32-S3-WROOM-1`,
  `Maxim_WLP-12`, `D_SOD-123`, `USB_C_Receptacle_HRO_TYPE-C-31-M-12`, `JST_PH_S2B-PH-K`,
  `Hirose_FH12-6S/24S`, `microSD_HC_Hirose_DM3AT`) in `ereader.3dshapes/*.wrl`, and
  repointed all 43 stock `(model …)` refs in `ereader.kicad_pcb` to
  `${KIPRJMOD}/ereader.3dshapes/…` at `scale 0.3937`. Bodies are box/cylinder stand-ins
  sized from each part's datasheet/footprint outline (colour-coded by class) — for
  visualisation only; swap in vendor STEP/WRL before fab. Fiducials, M2 mounting holes,
  and the bare `JumperPad_2P_P2.0mm` keep no body. Updated `ereader-footprints.md`.

### BOOT/RESET switches replaced with bare jumper pads (2026-09-06)
- **SW5/SW6 → JP5/JP6.** BOOT and RESET are no longer Würth WS-TASU tactiles —
  they're bare 2-pad exposed jumpers (`ereader:JumperPad_2P_P2.0mm`, hand-drawn,
  two 1.2×1.2 mm pads on 2 mm pitch, no switch part), momentarily shorted with a
  screwdriver tip or tweezers to pull `IO0_BOOT`/`EN` low. Same board position and
  nets as the tactiles they replace (pad 1 → `IO0_BOOT`/`EN`, pad 2 → `GND`), so
  routing/placement elsewhere is unaffected; drops two tactile switches from the
  BOM. Updated `ereader-connection-list.md`, `ereader-schematic.md`,
  `ereader-pcb-design.md`, `ereader-footprints.md`, `ereader-kicad.net`,
  `ereader.cmp`, `ereader.kicad_pcb`, `ereader-placement.svg`, and ADR 0008.
  Hand-drawn pad geometry (no datasheet, since there's no part to order) —
  still to be DRC'd against fab minimum clearance and the case cutout before fab.

### Switch footprints locked to datasheets (2026-09-06)
- **Tactiles → Würth WS-TASU 436351045816** (4.7×3.5 mm side push with boss).
  Replaced the generic `Tact_Side_TS1187A` stand-in with `ereader:WE_WS-TASU_436351045816`,
  its land drawn from the WE datasheet (rev 001.003): 4 pads 1.2×0.7 mm at x=±2.8 /
  y=±1.35 plus **two Ø0.75 boss holes** at y=±1.375 (pins 1≡3 top, 2≡4 bottom). SW1–SW3
  and SW5/SW6 rotated **270°** so the actuator faces the right board edge.
- **SW4 → exact ALPS SLLB5 land.** Rebuilt `ereader:ALPS_SLLB5_Lever` from the ALPS
  datasheet (p.491): 4 signal pads 1.0×1.3 mm on **2 mm pitch** in terminal order
  **CW / COM / PUSH / CCW**, plus **two Ø1.1 locator holes** at x=±1.9 and side solder
  lugs; body 9.5×8.8 mm. Rotated **90°** so the lever faces the left edge. Nets
  unchanged (LEV_CW/CCW/PUSH + COM→GND).
- 3D bodies (`ereader.3dshapes/*.wrl`) and `ereader-kicad.net` / `ereader.cmp` updated
  to the new footprint ids. Lands are datasheet-drawn but still to be DRC'd against the
  ordered part before fab.

### Switches + schematic (2026-09-06)
- **Navigation buttons are now genuinely side-actuated.** SW1–SW3 (and BOOT/RESET
  SW5/SW6) moved off the top-actuated `Button_Switch_SMD:SW_SPST_TL3342` stand-in
  onto a new project footprint `ereader:Tact_Side_TS1187A_4P_3.5x4.7mm` (TS-1187A /
  YD-3414 class), with the actuator facing the board edge — required because the
  screen covers the whole front and magnets hold the back to the phone, so top/bottom
  actuation is unreachable. SW1–SW3 rotation set to 0° so the actuators point at the
  right edge; nets (BTN_A/B/C, IO0_BOOT, EN, GND) preserved.
- **SW4 lever land built.** Replaced the `PinHeader_1x04` placeholder with
  `ereader:ALPS_SLLB5_Lever` (ALPS SLLB5, ~9.5×8.8×2.2 mm) whose pads are named
  **CW/CCW/PUSH/COM**, so `LEV_CW`(23)/`LEV_CCW`(24)/`LEV_PUSH`(25) and `COM→GND`(5)
  now connect on netlist import instead of sitting unconnected. Noted SLLB510100 as a
  pin-compatible alternative.
- Added project footprint library `ereader.pretty` (registered in a new `fp-lib-table`)
  and simplified 3D bodies in `ereader.3dshapes/*.wrl` (referenced with `scale 0.3937`)
  so the switches render in the 3D viewer without KiCad's stock libraries. Updated
  `ereader-kicad.net` + `ereader.cmp` footprint IDs to match. Lands are approximate
  stand-ins — DRC vs the ordered MPN before fab.
- **Added a reviewable schematic, `ereader-schematic.md`** (subsystem Mermaid
  diagrams built from the connection list; renders on GitHub). Documents why the
  netlist-first design has no native Eeschema `.kicad_sch` and how to draw one. Updated
  `ereader-footprints.md`, `ereader-README.md`, `ereader-pcb-design.md`, and ADR 0008.
- **Removed the legacy `hardware/` reference spec** (`DESIGN.md`, `BOM.csv`,
  `gen_netlist_skidl.py`, its `README.md`) — the older 3-button lineage with a
  conflicting parts list (MCP73831 / AP2112K / TPS61165), superseded by the canonical
  `ereader.*` docs. Redirected all live references (README, `docs/runbook.md`, the
  CI workflow trigger paths + comment, ADRs 0001/0002/0003/0008, and the
  `ereader-pcb-design.md` DC-DC provenance note) to the `ereader-*` docs so there is a
  single source of truth. Historical entries in this changelog and `docs/research-log.md`
  are left as-is.

### Merged / consolidated (2026-09-05)
- Merged `claude/schematics-pcb-review-rq1i2t` into `main` alongside the
  first-try board `ereader.*` (`colophon-standard-compliance` had no unique
  commits). Clean merge (disjoint paths).
- Established the actual KiCad board **`ereader.*` (Rev C) as canonical**;
  `hardware/` is now labelled a reference spec. Full comparison in
  `docs/research-log.md`.
- Retargeted the KiCad CI workflow at `ereader.kicad_pcb` (DRC + gerber
  export). Removed a stray `~ereader.kicad_pro.lck`; git-ignore KiCad/lock/
  history/gerber cruft going forward.
- **Consolidated to a single KiCad project.** Removed the redundant
  `hardware/` scaffold KiCad files (`mini-ereader.kicad_pro`, `.kicad_sch`,
  `.kicad_pcb`, `fp-lib-table`, `sym-lib-table`); the canonical board is now
  the only KiCad project, `ereader.*` at the repo root. `hardware/` keeps the
  electrical source-of-truth (`DESIGN.md`, `BOM.csv`, `gen_netlist_skidl.py`).
  Docs, the runbook, ADR 0002, and CI updated to point at `ereader.*`.
- **Reconciled the ADRs to the canonical Rev C parts.** Added
  [ADR 0006](docs/adr/0006-i2c-managed-power-path.md) (I2C-managed power path:
  BQ25628E charger + TPS62840 buck + MAX17048 gauge, two I2C buses) which
  supersedes ADR 0003, and
  [ADR 0007](docs/adr/0007-lm3630a-frontlight-driver.md) (LM3630A
  single-boost dual-sink frontlight driver) which supersedes ADR 0005. ADRs
  0003 and 0005 are marked Superseded, with their reasoning preserved.
- Documented the navigation input scheme in
  [ADR 0008](docs/adr/0008-navigation-input.md): three side tactile buttons +
  an ALPS SLLB510200 multi-directional lever switch (CW/CCW/press), all on
  RTC-capable wake GPIOs. (New decision; the reference spec had three buttons
  only.)
- Folded the exact SSD1677 external DC-DC values from `hardware/DESIGN.md` §5
  into `ereader-pcb-design.md` §6 (L 47 µH, Si1308EDL FET, MBR0530 ×3,
  2.2 Ω sense + 1 MΩ pulldown, 4.7 µF/1 µF ≥25 V caps, and the VGH/VGL/VSH/
  VSL/VCOM rails) so the canonical spec no longer defers to the vendor zip.
- Removed the committed `ereader-gerbers.zip` build artifact (regenerable with
  `python3 fab.py`; already git-ignored); docs now describe it as a generated
  output, not a shipped file.

### Added
- Hardware design for a 4.26" 800×480 frontlit e-paper reader:
  `hardware/DESIGN.md` (block diagram, power tree, net list, ESP32-S3 pin
  map, frontlight subsystem, PCB guidance, verification status).
- KiCad 8 project scaffold + config: `hardware/mini-ereader.kicad_pro`,
  `.kicad_sch`, `.kicad_pcb`, library tables.
- `hardware/BOM.csv` and `hardware/gen_netlist_skidl.py` (SKiDL netlist
  generator).
- Decisions `docs/adr/0001`–`0005` (MCU, display + frontlight, power,
  native-USB programming, frontlight driver).
- CI: `.github/workflows/kicad.yml` runs `kicad-cli` ERC/DRC and exports a
  schematic PDF + gerbers as build artifacts.

### Changed
- Repository adapted from the Colophon documentation template into the
  Mini E-Reader project: Brief (`README.md`), Log, Runbook, and Changelog
  rewritten; methodology decisions replaced with product decisions.
- Display target corrected from an initial 2.13" assumption to **4.26"
  800×480** after the owner supplied the FL0426-S01C frontlight datasheet;
  a tunable-white frontlight subsystem was added (see ADR 0002 / 0005).
- Display **locked to Good Display GDEY0426T82-FL01C** (controller SSD1677)
  from the panel datasheet: 24-pin EPD FPC pinout and the SSD1677 external
  DC-DC reference circuit captured in DESIGN.md §5; BOM gains J4 + boost
  parts (L2, Q2, D4-D6, R11/R12, ≥25 V caps); the SKiDL generator now emits
  the real EPD block.

### Removed
- Colophon methodology content that no longer applies to this project:
  `docs/faq.md`, `docs/adoption.md`, the methodology ADRs
  (`docs/adr/000{1..5}-*` Colophon versions), the duplicate `hardware/docs/`
  tree, and `LICENSE-TEXT` (the methodology's CC BY 4.0 license). The
  project is MIT (`LICENSE`).

### Notes
- Schematic/PCB are valid scaffolds, not yet captured/routed; ERC/DRC must
  pass in KiCad (now also runnable in CI).
- Two switching subsystems (EPD DC-DC + frontlight boost) must be laid out
  away from the antenna and the battery-sense ADC.

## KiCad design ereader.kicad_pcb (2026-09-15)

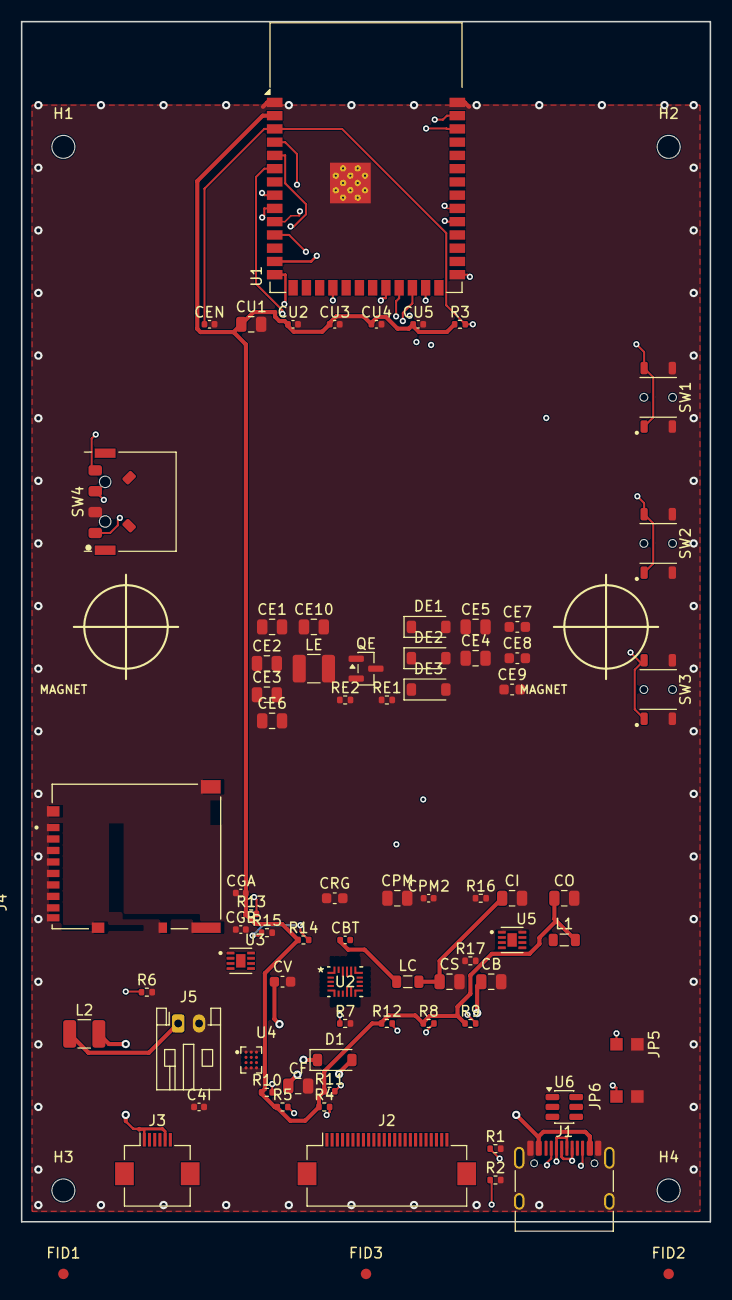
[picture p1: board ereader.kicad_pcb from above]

Board: 4 copper layers, 66.0 x 115.0 mm, 81 parts (0 on the bottom side), 59 nets.

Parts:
C4I: 1uF; C_0402_1005Metric
CB: 10uF; C_0805_2012Metric
CBT: 47nF; C_0402_1005Metric
CE1, CE2, CE3, CE4, CE5, CE6, CE10: 4.7uF/25V; C_0805_2012Metric
CE7, CE8, CE9: 1uF/25V; C_0603_1608Metric
CEN: 1uF; C_0402_1005Metric
CF: 2.2uF/25V; C_0805_2012Metric
CGA: 0.1uF; C_0402_1005Metric
CGB: 1uF; C_0402_1005Metric
CI: 10uF; C_0805_2012Metric
CO: 10uF; C_0805_2012Metric
CPM: 10uF; C_0805_2012Metric
CPM2: 0.1uF; C_0402_1005Metric
CRG: 4.7uF; C_0603_1608Metric
CS: 10uF; C_0805_2012Metric
CU1: 22uF; C_0805_2012Metric
CU2, CU3, CU4, CU5: 0.1uF; C_0402_1005Metric
CV: 1uF; C_0603_1608Metric
D1: Schottky_30V; D_SOD-123
DE1, DE2, DE3: MBR0530; D_SOD-123
FID1, FID2, FID3: FID; Fiducial_1mm_Mask2mm
H1, H2, H3, H4: M2; MountingHole_2.2mm_M2
J1: USB-C-16P; USB_C_Receptacle_HRO_TYPE-C-31-M-12
J2: EPD_FPC_24P; Hirose_FH12-24S-0.5SH_1x24-1MP_P0.50mm_Horizontal
J3: FL_FPC_6P; Hirose_FH12-6S-0.5SH_1x06-1MP_P0.50mm_Horizontal
J4: microSD; HRS_DM3AT-SF-PEJM5
J5: Battery_1S; JST_PH_S2B-PH-K_1x02_P2.00mm_Horizontal
JP5: BOOT; JumperPad_2P_P2.0mm
JP6: RESET; JumperPad_2P_P2.0mm
L1: 2.2uH; L_0805_2012Metric
L2: 22uH; L_1210_3225Metric
LC: 1uH; L_0805_2012Metric
LE: 47uH; L_1210_3225Metric
QE: Si1308EDL; SOT-23
R1, R2: 5.1k; R_0402_1005Metric
R3, R4, R5, R6, R7: 100k; R_0402_1005Metric
R8, R9, R10, R11: 4.7k; R_0402_1005Metric
R12, R13, R14, R15: 10k; R_0402_1005Metric
R16: 267k; R_0402_1005Metric
R17: 1.65k; R_0402_1005Metric
RE1: 2.2R; R_0402_1005Metric
RE2: 1M; R_0402_1005Metric
SW1: BTN_A; WE_WS-TASU_436351045816
SW2: BTN_B; WE_WS-TASU_436351045816
SW3: BTN_C; WE_WS-TASU_436351045816
SW4: SLLB510200; ALPS_SLLB5_Lever
U1: ESP32-S3-WROOM-1-N16R8; ESP32-S3-WROOM-1
U2: BQ25628E; WQFN-HR18__RYK_TEX
U3: MAX17048; SON50P200X200X80-9N
U4: LM3630A; BGA12N50P4X3_196X146X62
U5: TPS62840; SON50P200X200X80-9N
U6: USBLC6-2SC6; SOT-23-6

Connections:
+3V3: CE6.1, CE7.1, CO.1, CU1.1, CU2.1, CU3.1, CU4.1, CU5.1, J2.15, J2.16, J4.4, L1.2, LE.1, R3.1, R4.1, R5.1, R8.1, R9.1, R10.1, R11.1, R12.1, R13.1, U1.2, U5.8
+SYS: CI.1, CS.1, LC.2, U2.9, U5.2, U5.4
+VBAT: C4I.1, CB.1, CGA.1, CGB.1, J5.1, L2.1, U2.8, U3.2, U3.3, U4.C3
+VBUS: CV.1, J1.A4, J1.A9, J1.B4, J1.B9, U2.18, U6.5
BTN_A: SW1.1, U1.4
BTN_B: SW2.1, U1.5
BTN_C: SW3.1, U1.6
BUCK_SW: L1.1, U5.7
CC1: J1.A5, R1.1
CC2: J1.B5, R2.1
CHG_BTST: CBT.2, U2.1
CHG_CE: R7.1, U1.22, U2.14
CHG_INT: R12.2, U1.24, U2.11
CHG_SW: CBT.1, LC.1, U2.16
EN: CEN.1, JP6.1, R3.2, U1.3
EPD_BUSY: J2.9, U1.7
EPD_CS: J2.12, R4.2, U1.18
EPD_DC: J2.11, U1.17
EPD_GDR: J2.2, QE.1, RE2.1
EPD_MOSI: J2.14, U1.19
EPD_NODEX: CE10.2, DE1.1, DE2.2
EPD_RESE: J2.3, QE.2, RE1.1
EPD_RST: J2.10, U1.12
EPD_SCLK: J2.13, U1.20
EPD_SW: CE10.1, DE3.2, LE.2, QE.3
EPD_VCOM: CE9.1, J2.24
EPD_VDD: CE8.1, J2.18
EPD_VGH: CE5.1, DE3.1, J2.21
EPD_VGL: CE4.1, DE1.2, J2.23
EPD_VSH1: CE1.1, J2.20
EPD_VSH2: CE2.1, J2.5
EPD_VSL: CE3.1, J2.22
FL_COOL_K: J3.2, U4.D3
FL_HWEN: R6.1, U1.23, U4.B1
FL_OUT: CF.1, D1.1, J3.1, J3.5, U4.D1
FL_SW: D1.2, L2.2, U4.A3
FL_WARM_K: J3.6, U4.D2
GAUGE_ALRT: R13.2, U1.25, U3.5
GND: C4I.2, CB.2, CE1.2, CE2.2, CE3.2, CE4.2, CE5.2, CE6.2, CE7.2, CE8.2, CE9.2, CEN.2, CF.2, CGA.2, CGB.2, CI.2, CO.2, CPM.2, CPM2.2, CRG.2, CS.2, CU1.2, CU2.2, CU3.2, CU4.2, CU5.2, CV.2, DE2.1, J1.A1, J1.A12, J1.B1, J1.B12, J1.SH, J2.8, J2.17, J4.6, J4.P1, J4.P2, J4.P3, J4.P4, J5.2, JP5.2, JP6.2, R1.2, R2.2, R6.2, R7.2, R15.2, R16.2, R17.2, RE1.2, RE2.2, SW1.2, SW2.2, SW3.2, SW4.COM, U1.1, U1.40, U1.41, U2.15, U3.1, U3.4, U3.6, U3.9, U4.B3, U4.C1, U4.C2, U5.1, U5.3, U5.6, U5.9, U6.2
I2C0_SCL: R9.2, U1.11, U2.13, U3.7
I2C0_SDA: R8.2, U1.10, U2.12, U3.8
I2C1_SCL: R11.2, U1.31, U4.A2
I2C1_SDA: R10.2, U1.9, U4.A1
ILIM: R17.1, U2.4
IO0_BOOT: JP5.1, U1.27
LEV_CCW: SW4.CCW, U1.38
LEV_CW: SW4.CW, U1.39
LEV_PUSH: SW4.PUSH, U1.8
PMID: CPM.1, CPM2.1, U2.17
REGN: CRG.1, U2.2
SD_CS: J4.2, R5.2, U1.32
SD_MISO: J4.7, U1.33
SD_MOSI: J4.3, U1.35
SD_SCK: J4.5, U1.34
TS: R14.2, R15.1, U2.6
TS_BIAS: R14.1, U2.5
USB_DM: J1.A7, J1.B7, U1.13, U6.3, U6.4
USB_DP: J1.A6, J1.B6, U1.14, U6.1, U6.6
VSET: R16.1, U5.5

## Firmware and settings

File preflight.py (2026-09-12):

#!/usr/bin/env python3
"""Fabrication preflight: is ereader.kicad_pcb in sync with ereader-kicad.net?

kicad-cli's DRC checks a board's *internal* connectivity only — it never
compares the board against the netlist. So a board that is simply missing
components (e.g. routed before "Update PCB from Netlist" was run) passes DRC
with zero errors while silently omitting whole subsystems. That exact gap let
a routed board reach main without the EPD external DC-DC block on it.

This script closes that gap: every component in the netlist MUST exist on the
board. Board-only parts that legitimately have no netlist entry (fiducials,
mounting holes, and unannotated placeholders) are allowed via ALLOW_BOARD_ONLY.

Exit 0 = in sync (safe to fab). Exit 1 = out of sync (do NOT fab).
Run standalone (`python3 preflight.py`) or import `check()` from fab.py.
"""
import os
import re
import sys

HERE = os.path.dirname(os.path.abspath(__file__))
NET = os.path.join(HERE, "ereader-kicad.net")
PCB = os.path.join(HERE, "ereader.kicad_pcb")

# Board-only references that are expected to have no netlist component.
ALLOW_BOARD_ONLY = re.compile(r"^(FID\d+|H\d+|REF\*\*|G\*\*+|\*\*)$")


def netlist_refs(path):
    s = open(path, encoding="utf-8").read()
    return set(re.findall(r'\(comp\s+\(ref\s+"([^"]+)"', s))


def board_refs(path):
    s = open(path, encoding="utf-8").read()
    # New KiCad format stores the ref as a property; older format as fp_text.
    refs = set(re.findall(r'\(property\s+"Reference"\s+"([^"]+)"', s))
    refs |= set(re.findall(r'fp_text\s+reference\s+"([^"]+)"', s))
    return refs


def check():
    net = netlist_refs(NET)
    board = board_refs(PCB)
    missing = sorted(net - board)                       # in netlist, not on board
    extra = sorted(r for r in (board - net)             # on board, not in netlist
                   if not ALLOW_BOARD_ONLY.match(r))

    print(f"preflight: netlist components = {len(net)}, board footprints = {len(board)}")
    ok = True
    if missing:
        ok = False
        print(f"\nERROR: {len(missing)} netlist component(s) are NOT on the board:")
        print("  " + ", ".join(missing))
        print("  -> In KiCad: Tools > Update PCB from Netlist (F8), then place + route them.")
    if extra:
        # Unexpected board-only parts: warn, do not fail (may be intentional).
        print(f"\nWARNING: {len(extra)} board footprint(s) have no netlist entry:")
        print("  " + ", ".join(extra))
    if ok:
        print("\nOK: every netlist component is present on the board.")
    return ok


if __name__ == "__main__":
    sys.exit(0 if check() else 1)

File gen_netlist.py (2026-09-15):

#!/usr/bin/env python3
"""SKiDL generator for the Mini E-Reader netlist.

WHY: `ereader-kicad.net` was hand-authored with IC pins named by *function*
(IN, SDA, SW...). KiCad binds netlist pins to footprint *pads* by name/number,
so those function names never match numbered pads -> the "pad X not found"
errors on import. This script instead builds the design from real *symbols*:
the symbol carries the pin-name -> pad-number map, so the generated netlist
references correct pad numbers and imports cleanly.

RUN (in your KiCad environment, where the symbol libraries live):
    pip install skidl
    python3 gen_netlist.py
It writes `ereader-kicad.net`, then in Pcbnew: File > Import > Netlist... >
match **by Reference**, "Delete extra footprints" UNCHECKED, Update PCB.

FIRST RUN WILL LIKELY REPORT ISSUES, and that is the intended loop:
  * "Can't find library ..." / "Can't find part ..."  -> a CFG symbol below is
    not installed yet (see CFG: add the SnapEDA symbol to ereader.kicad_sym,
    or point lib_id at your stock lib).
  * "... has no pin named X"  -> the symbol names that pin differently; fix the
    name here (or rename in the symbol). Paste the output back and I'll adjust.
Nothing is guessed: net membership is transcribed verbatim from
`ereader-connection-list.md`; pin identifiers are the datasheet function names.

SAFETY: verify diode anode/cathode and every IC power/EP pin against the real
symbol before you fabricate. See "KNOWN ITEMS TO VERIFY" at the bottom.
"""
import os, glob, re

# ---------------------------------------------------------------------------
# Point SKiDL at the installed KiCad symbol libraries. KiCad does NOT export
# KICAD*_SYMBOL_DIR to the shell, so a script run outside KiCad cannot find the
# stock libs -> "Can't open file: RF_Module". Auto-detect the symbols folder
# (override by exporting KICAD_SYMBOL_DIR), and add this project dir so the
# project library `ereader.kicad_sym` (U2-U5, J2, SW4) resolves too.
# ---------------------------------------------------------------------------
HERE = os.path.dirname(os.path.abspath(__file__))
_ENV_KEYS = ("KICAD_SYMBOL_DIR", "KICAD10_SYMBOL_DIR", "KICAD9_SYMBOL_DIR",
             "KICAD8_SYMBOL_DIR", "KICAD7_SYMBOL_DIR", "KICAD6_SYMBOL_DIR")

def _find_symbols():
    for _k in _ENV_KEYS:
        _d = os.environ.get(_k)
        if _d and glob.glob(os.path.join(_d, "*.kicad_sym")):
            return _d
    for _c in ("/usr/share/kicad/symbols", "/usr/local/share/kicad/symbols",
               "/app/share/kicad/symbols",                      # flatpak
               os.path.expanduser("~/.local/share/kicad/symbols"),
               "/Applications/KiCad/KiCad.app/Contents/SharedSupport/symbols",
               r"C:\Program Files\KiCad\10.0\share\kicad\symbols",
               r"C:\Program Files\KiCad\9.0\share\kicad\symbols",
               r"C:\Program Files\KiCad\8.0\share\kicad\symbols"):
        if glob.glob(os.path.join(_c, "*.kicad_sym")):
            return _c
    return None

_SYM = _find_symbols()
if _SYM:
    for _k in _ENV_KEYS:
        os.environ.setdefault(_k, _SYM)
else:
    print("WARNING: KiCad stock symbols not found. Export KICAD_SYMBOL_DIR to "
          "your KiCad 'symbols' folder (e.g. /usr/share/kicad/symbols) and re-run.")

from skidl import *
import skidl as _skidl

# Belt-and-suspenders: ensure the stock dir and this project dir are searched.
for _paths in getattr(_skidl, "lib_search_paths", {}).values():
    for _p in (HERE, _SYM):
        if _p and _p not in _paths:
            _paths.append(_p)

# ---------------------------------------------------------------------------
# CFG: symbols NOT in KiCad stock libraries. Install each (SnapEDA / vendor)
# into a project symbol lib `ereader.kicad_sym`, or point lib_id at a stock lib
# your KiCad has. The symbol MUST expose the pin names listed in "needs pins".
# Footprints follow ereader-footprints.md (corrected packages).
# ---------------------------------------------------------------------------
CFG = {
    # ref : (symbol lib_id,                         footprint)
    # SnapEDA symbols the user imported: BQ25628ERYKR, MAX17048G+T10, LM3630ATME,
    # TPS62840DLCR, DM3AT-SF-PEJM5. Symbol wants are the BASE name so the
    # resolver prefix-matches whatever suffix SnapEDA used. Footprints prefer a
    # matching .kicad_mod in ereader.pretty/ (auto), falling back to the string
    # here. ref : (symbol lib_id, fallback footprint)
    "U2": ("ereader:BQ25628E",  "ereader:WQFN-HR18__RYK_TEX"),  # BQ25628E (Ultra Librarian). pins used: VBUS SYS BAT GND SDA SCL *INT(11) *CE(14) TS TS_BIAS REGN PMID SW BTST. RYK HotRod WQFN-HR18: footprint is pads 1-18, NO exposed pad -> nothing to tie.
    "U3": ("ereader:MAX17048",  "ereader:SON50P200X200X80-9N"),  # MAX17048G+T10 = TDFN-8 2x2 WITH EP (pad 9), per the symbol's own package/footprint pairing. The 8N (2x1.5, no-EP) was wrong -> import error "U3 pad 9 not found". pins: CELL VDD GND SDA SCL ~ALERT(5) + CTG/QSTRT/EP->GND.
    "U4": ("ereader:LM3630A",   "ereader:BGA12N50P4X3_196X146X62"),  # LM3630A DSBGA-12. pins: IN GND SDA SCL HWEN SW ILED1 ILED2 OVP (SEL/PWM->GND).
    "U5": ("ereader:TPS62840",  "ereader:SON50P200X200X80-9N"),  # TPS62840 VSON-HR-8 + thermal pad. pins: VIN SW VOS(8=output) GND EN MODE STOP VSET(5=Rset) EP(9=thermal->GND, added to symbol). No FB pin. (9N footprint has pad 9; symbol's own 8N property is overridden by SKiDL.)
    "J2": ("ereader:EPD_GDEY0426T82_FPC24", "Connector_FFC-FPC:Hirose_FH12-24S-0.5SH_1x24-1MP_P0.50mm_Horizontal"),  # 24 pins named by function AND numbered to the panel FPC datasheet
    "J4": ("ereader:DM3AT", "ereader:HRS_DM3AT-SF-PEJM5"),  # DM3AT-SF-PEJM5 microSD. needs: CLK CMD DAT0 DAT3 VDD VSS
    "SW4": ("ereader:ALPS_SLLB5", "ereader:ALPS_SLLB5_Lever"),        # needs: CW CCW PUSH COM
}

# --- Resolve CFG symbols: auto-use a stock symbol if your KiCad already ships
#     one; otherwise it must live in ereader.kicad_sym. Report ALL missing at
#     once (instead of crashing on the first) so you get the full list. --------
def _symbol_index():
    idx = {}
    for _d in [p for p in (_SYM, HERE) if p]:
        for _f in sorted(glob.glob(os.path.join(_d, "*.kicad_sym"))):
            _lib = os.path.splitext(os.path.basename(_f))[0]
            try:
                _txt = open(_f, encoding="utf-8", errors="ignore").read()
            except OSError:
                continue
            for _m in re.finditer(r'\(symbol\s+"([^"]+)"', _txt):
                _nm = _m.group(1)
                if re.search(r'_\d+_\d+$', _nm):   # skip unit sub-symbols
                    continue
                idx.setdefault(_nm.lower(), f"{_lib}:{_nm}")
    return idx

_INDEX = _symbol_index()
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

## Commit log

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2026-09-05 Adapt repo to Mini E-Reader; add 4.26" display + frontlight + KiCad CI
    Full Colophon->project adaptation and incorporation of the owner-supplied
    Good Display FL0426-S01C frontlight datasheet.
    Project docs (Colophon "adopt forward"):
    - README.md rewritten as the Mini E-Reader Brief.
    - docs/adr/0001-0005 = e-reader decisions (MCU, display+frontlight, power,
    native-USB programming, frontlight driver).
    - docs/research-log.md, docs/runbook.md, CHANGELOG.md restarted for the
    project.
    Display/frontlight (from FL0426-S01C):
    - Corrected display to 4.26" 800x480 EPD (was a 2.13" assumption). The PDF
    is a FRONTLIGHT module, not the panel: tunable white, 2 channels of 5
    series LEDs (VF<=15V, I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
    [BOM.csv, mini-ereader.kicad_pcb, mini-ereader.kicad_sch]
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2026-09-06 Replace BOOT/RESET tactiles (SW5/SW6) with bare jumper pads (JP5/JP6)
    BOOT and RESET are a rarely-used recovery path, so swap the Würth
    WS-TASU tactiles for two exposed 2-pad jumpers (ereader:JumperPad_2P_P2.0mm)
    at the same board location: momentarily short them with a screwdriver tip
    or tweezers to pull IO0/EN low instead of pressing a switch. Drops two
    tactile switches from the BOM; same nets, same footprint spot.
    Updated the whole netlist-first chain: connection list, schematic,
    pcb-design spec, footprints picklist, kicad netlist/.cmp/.kicad_pcb,
    placement SVG, ADRs 0004/0008, runbook, and both READMEs.
    Claude-Session: https://cl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
    [ereader.kicad_pcb]
2026-09-06 Fix SW4 3D lever + give every component a self-contained 3D body
    The 3D view had two problems. SW4's ALPS SLLB5 body rendered as a tall
    block with an upward box knob ("odd big switch"); the SLLB5 is really a
    flat semicircular "fan" puck (W9.5 x D8.8 x H2.2mm, Lever-Return family)
    that lies on the board with a low SIDEWAYS rocker/toggle lever on top
    (CW/CCW flick + PUSH). Rebuilt ALPS_SLLB5_Lever.wrl as the flat puck +
    sideways lever to match the ALPS datasheet.
    Every other placed component only referenced KiCad stock 3D packs
    (${KICAD6/7_3DMODEL_DIR}/...), which go missing on any machine/CI without
    the KiCad 3D-model add-on, so most parts showed no body in the 3D viewer.
    Added simplified pr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
    [ereader.kicad_pcb]
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2026-09-06 Rearrange crowded components to clear courtyard overlaps
    Board is in placement phase (no tracks routed), so footprints move freely.
    Resolves every same-side courtyard overlap flagged in the placement review
    (verified 0 overlaps remaining). No vias coincide with any moved part, so
    none had to travel; copper zones refill automatically.
    ESP32 (U1) decoupling — out from under the module body / antenna keep-out
    into a row just below the module:
    CEN 20,17->18,29 CU1 24,21->22,29 CU2 28,21->26,29 CU3 32,21->30,29
    CU4 36,21->34,29 CU5 40,21->38,29 R3 20,21->42,29
    Battery/charger cluster — spread out of the JST J5 courtyard (body + cable
    clearance) to the right of the connector:
    U4 1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
    [ereader.kicad_pcb]
2026-09-07 Clear last tight clearances and tidy moved-part silkscreen refs
    Tighten the two sub-0.3mm pairs left by the previous rearrange (now >=0.4mm
    courtyard clearance), verified 0 overlaps / 0 tight remaining:
    R13 21,86 -> 22,85.5 (was 0.25mm to J4 microSD)
    R15 23,88 -> 23.5,87.3 (was 0.28mm to U3)
    Tidy reference-designator silkscreen for moved parts so no ref text overlaps
    a pad, another ref, or a component body (verified 0 ref clashes):
    R10 ref offset -> left of part R11 ref offset -> right of part
    JP6 ref offset -> clear of J1/U6 R15 ref centered on its own pad
    (only clear spot in the R13/U3/R14 pocket; clears all neighbours 0.25mm)
    Reference text only; component position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
    [ereader.kicad_pcb]
2026-09-07 Fix DRC errors: J1 shield ground, U1 thermal via holes, edge via collisions
    - Tie J1's 4 shield/mechanical (S1) pads to GND, matching the documented
    intent in ereader-connection-list.md / ereader-schematic.md
    ("J1.GND(A1,B1,A12,B12)+shield"). They were floating on no net, which
    is what made a nearby GND via read as shorting two different nets.
    - Give J1's GND pads (A1, A12, B1, B12) a solid zone connection
    (zone_connect 2), same pattern already used for the IC exposed pads
    in this file. Their pad geometry is too small at the board edge to
    resolve the required 2 thermal-relief spokes.
    - Widen U1's 12 via-in-pad thermal vias (pad "41") from 0.2mm to 0.3mm
    drill to meet the board'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
    [ereader.kicad_pcb]
2026-09-07 Fix remaining DRC errors: via/netclass mismatch, starved thermals on small parts
    - Resize all 55 GND stitching vias from 0.6/0.3mm to 0.8/0.4mm. The GND
    net is assigned to the "Power" net class (via_diameter 0.8, via_drill
    0.4 in ereader.kicad_pro), but every via was physically placed at the
    Default class's 0.6/0.3mm dimensions instead, leaving only a 0.1mm
    annular ring against the board's 0.13mm minimum. Matching the vias to
    their own net class gives a 0.2mm ring with real margin.
    - Remove one exact-duplicate via stacked on top of another at (1.6, 8).
    - Give a solid zone connection (zone_connect 2) to every other small GND
    SMD pad on the board (0402/0603 R/C GND pads, SW1-3 GND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
    [ereader.kicad_pcb]
2026-09-07 DRC warnings: fix switch silk-over-copper and sync footprint library
    Silkscreen (clears 11 silk_over_copper warnings):
    - SW1/SW2/SW3 (WE WS-TASU): remove the F.SilkS actuator-direction arrow.
    It sat directly over the Ø0.75 boss NPTH hole (arrow local y 1.4-1.95
    over boss at y 1.375, r 0.375). The F.Fab body outline is unchanged, so
    assembly documentation still shows the switch outline.
    - SW4 (ALPS SLLB5): split each vertical body silk line so it skips the
    side solder-lug pad band (local y +/-1.3) instead of running across the
    lug pads. Outline is preserved, just gapped at the pads.
    Footprint library sync (clears 6 lib_footprint warnings):
    - Add ereader.pretty/JumperPad_2P_P2.0mm.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
    [ereader.kicad_pcb]
2026-09-07 DRC warnings: clear dense-cluster silk congestion via F.Fab layer moves
    Resolves the remaining 27 silkscreen warnings by moving the offending
    silk items to F.Fab (assembly/fab layer), which the silk DRC checks
    (silk_overlap, silk_over_copper, silk_edge_clearance) do not police. Per
    the agreed approach: reference designators boxed in by neighbours spill
    to the fab layer rather than being deleted, so they remain in assembly
    drawings.
    Reference designators over neighbouring pads/silk (clears 17: 12
    silk_over_copper + 5 silk_overlap) - moved to F.Fab:
    - R15, U2, R7, R4, R5 - all in the tight 0402 power cluster where there
    is no clear silk space for them.
    Antenna keepout annotation (clears 6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
    [ereader.kicad_pcb]
2026-09-09 Fix remaining DRC errors and warnings: U1 EPAD net, J1 shield thermals, SW4 library parity, mechanical hole clearance
    - U1 exposed pad (pin 41/EPAD): add the missing GND net to 12 of its 13
    copper features, which were floating and split the F.Cu GND zone into
    an isolated island under the module (unconnected_items x4).
    - J1 shield pads (S1): give all 4 a solid zone connection, fixing a
    starved thermal on In1.Cu and a second tiny isolated F.Cu island next
    to the A12/B1 pads (unconnected_items x2 more).
    - ALPS_SLLB5_Lever library: revert the corner lug pad rotations to
    45/135 - the previous "fix" mistakenly matched the library to the
    board's rotation-inclusive stored angle instead o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
    [ereader.kicad_pcb]
2026-09-10 Fix remaining DRC errors and warnings, verified against the real KiCad engine
    - lib_footprint_mismatch (all 6): FootprintNeedsUpdate() compares pad
    orientation relative to parent rotation and compares descr/tags
    verbatim. Added the explicit angle KiCad's writer omits for
    rotation-invariant pads (circles/squares) in rotated instances
    (SW4 locator holes, SW1-3 boss holes, JP5/JP6 pads), and resynced
    descr/tags between board instances and library copies (genericized
    JumperPad's BOOT-specific text so it matches both JP5 and JP6).
    Verified via FOOTPRINT.FootprintNeedsUpdate() through pcbnew's
    Python bindings - all 6 now return False.
    - hole_clearance custom rule: fixed condition f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
    [ereader.kicad_pcb]
2026-09-11 Harden every remaining thermal-relief GND pad to a solid zone connection
    hole_clearance and lib_footprint_mismatch are confirmed fixed (0 DRC
    violations in the latest report). unconnected_items held at 3 despite
    the previous pass's targeted net/zone_connect fixes and a spliced-in
    fresh zone fill - the CI's KiCad 8.0 zone-fill algorithm evidently
    forms different islands than KiCad 7.0.11 for the same input, since a
    from-scratch refill here now shows a single merged island per GND
    layer.
    Rather than chase a fill algorithm this sandbox can't reproduce,
    removed the dependency on it: gave every remaining GND-net pad still
    on default thermal relief (23 of them - 6 missed 0805 caps, SW4's COM
    pad,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
    [ereader.kicad_pcb]
2026-09-11 Remove a mis-scaled antenna keepout zone embedded in U1
    unconnected_items held at exactly 3 across three consecutive DRC
    reports, unchanged by the previous pass's pad-level net/zone_connect
    fixes - even though a from-scratch local refill confirms those merge
    the zone into a single island. Since no pad setting moved the number
    at all, the remaining cause has to be structural.
    Found a footprint-embedded keepout zone on U1 (copperpour not_allowed,
    F.Cu/In1.Cu/B.Cu) whose polygon, translated to absolute board
    coordinates, is 48x21mm (x:42-90, y:-1.75-19.25) - dwarfing the
    module's own ~18mm outline and extending 24mm past the board's right
    edge and above the top edge. The real, documented anten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
    [ereader.kicad_pcb]
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2026-09-12 CI/tooling: add board-netlist preflight gate; harden DRC; guard fab.py
    Follow-up to the "board routed" commit, which was routed before Update PCB
    from Netlist and so reached main missing the 19 Rev C4 parts (the EPD DC-DC
    block + decoupling). kicad-cli DRC never compares board vs netlist, so it
    passed silently. This adds the missing guardrails (the board-layout fixes
    themselves require interactive KiCad and are listed as remaining manual steps
    in the CHANGELOG/runbook):
    - preflight.py: fails if any ereader-kicad.net component is absent from
    ereader.kicad_pcb. Verified against current main -> reports the 19 missing
    parts and exits 1.
    - .github/workflows/kicad.yml: hard gate now. Runs pre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
    [fab.py, preflight.py]
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2026-09-12 Add SKiDL netlist generator (gen_netlist.py) to fix the pin/pad wall
    Importing the hand-authored netlist threw 56 "pad not found" errors because IC
    pins are named by function while footprints use numbered pads, with no symbol
    layer to map them. gen_netlist.py rebuilds the netlist from real symbols so
    pins carry datasheet pad numbers and the output imports cleanly:
    - Encodes all 53 nets verbatim from ereader-connection-list.md; a CFG block
    holds the non-stock symbols (U2-U5, J2, SW4) to point at SnapEDA /
    ereader.kicad_sym. Runs ERC, writes ereader-kicad.net.
    - Flags latent gaps in "KNOWN ITEMS TO VERIFY": U5.EN now wired to +3V3
    (was floating); U5.FB left for the fixed-vs-adjustable T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
    [gen_netlist.py]
2026-09-12 gen_netlist.py: auto-locate KiCad symbol libs (KICAD*_SYMBOL_DIR unset in shell)
    First run failed with "Can't open file: RF_Module" because KiCad doesn't export
    KICAD*_SYMBOL_DIR to the shell, so SKiDL couldn't find the stock symbol libs.
    The script now auto-detects the KiCad 'symbols' folder (common Linux/macOS/
    Windows paths, or an existing KICAD_SYMBOL_DIR), sets the env vars before
    importing skidl, and adds the project dir so ereader.kicad_sym resolves.
    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
    [gen_netlist.py]
2026-09-12 gen_netlist.py: report all missing custom symbols at once; auto-use stock libs
    Instead of crashing on the first ereader: part (U2), scan the KiCad symbol
    libraries and the project dir, auto-resolve any CFG part that KiCad already
    ships a stock symbol for, and print the full list of symbols still needed
    (with candidate lib_ids found in the user's libs) before exiting. Gives the
    complete, minimal shopping list in one run rather than one-at-a-time.
    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
    [gen_netlist.py]
2026-09-12 Add ereader.kicad_sym (SW4 symbol) + sym-lib-table; auto-resolve unique matches
    - ereader.kicad_sym: hand-authored SW4 symbol "ALPS_SLLB5" with pins
    CW/COM/PUSH/CCW (numbers match the ereader:ALPS_SLLB5_Lever footprint pad
    names, verified from the .kicad_mod). This is also the project symbol library
    to drop the SnapEDA symbols for U2-U5/J2 into.
    - sym-lib-table: registers the "ereader" symbol lib (mirrors fp-lib-table) so
    KiCad's Symbol Editor / Eeschema see it.
    - gen_netlist.py: _resolve() now auto-uses a unique base-name match, so a
    SnapEDA symbol imported as e.g. BQ25628ERYKR resolves for CFG "BQ25628E"
    without manual edits; ambiguous/none still reported.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
    [gen_netlist.py]
2026-09-12 gen_netlist.py: fix unsafe symbol auto-match (LM3630A hijacked by Device:L)
    The unique-match resolver matched in both directions, so want="lm3630a"
    matched the 1-letter stock symbol "Device:L" (via want.startswith("l")) and
    auto-used an inductor symbol for the LED driver U4 - a silent wrong mapping.
    Restrict candidates to symbols whose name STARTS WITH the wanted part name
    (bq25628e -> bq25628erykr), never the reverse. U4 correctly returns to the
    "needs a symbol" list.
    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
    [gen_netlist.py]
2026-09-13 gen_netlist.py: wire CFG to the SnapEDA parts + auto-resolve footprints
    User imported SnapEDA symbols BQ25628ERYKR / MAX17048G+T10 / LM3630ATME /
    TPS62840DLCR / DM3AT-SF-PEJM5. Symbol wants stay as base names (prefix-match
    any suffix); J4 want changed microSD_HC -> DM3AT so the DM3AT symbol resolves.
    Footprints now auto-resolve from ereader.pretty/ by base-name (drop the
    SnapEDA .kicad_mod files in and they're picked up), falling back to the CFG
    string; U2/U4/U5 fallbacks set to the MPN land names.
    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
    [gen_netlist.py]
2026-09-13 gen_netlist.py: map CFG footprints to the actual SnapEDA/UltraLibrarian lands
    Now that the vendor .kicad_mod files are in ereader.pretty, point each CFG
    footprint at its real filename: U2 BQ25628E -> WQFN-HR18__RYK_TEX (Ultra
    Librarian), U4 LM3630A -> BGA12N50P4X3_196X146X62, U5 TPS62840 ->
    SON50P200X200X80-9N (has thermal EP), U3 MAX17048 -> SON50P200X150X100-8N,
    J4 -> HRS_DM3AT-SF-PEJM5. The two SON-8 lands (U3/U5) are assigned by EP
    presence (TPS62840 has a thermal pad = 9N; MAX17048 does not = 8N) - to be
    confirmed against each symbol's Footprint property once the symbols land.
    Claude-Session: https://claude.ai/code/session_01YVjCq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
    [gen_netlist.py]
2026-09-13 Author LM3630A symbol from datasheet; fix U4 net names (ILED1/2, SEL, OVP)
    User supplied the LM3630A datasheet. Added the LM3630A symbol to
    ereader.kicad_sym with the exact DSBGA-12 (YFQ) ball map A1-D3
    (A1=SDA A2=SCL A3=SW B1=HWEN B2=INTN B3=GND C1=PWM C2=SEL C3=IN
    D1=OVP D2=ILED2 D3=ILED1), footprint ereader:BGA12N50P4X3_196X146X62.
    Corrected the netlist to match the datasheet + wire the pins the hand
    netlist had omitted:
    - FL sink pins renamed LED1/LED2 -> ILED1/ILED2 (balls D3/D2).
    - U4.SEL -> GND (selects I2C address 0x36, per design's I2C1 @ 0x36).
    - U4.OVP -> FL_OUT (overvoltage sense on the boost output, per datasheet).
    - U4.PWM -> GND (external PWM unused; brightness is over I2C).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
    [gen_netlist.py]
2026-09-13 Author J2 EPD FPC symbol from datasheet; fix panel VDD/VDDIO wiring
    User supplied the GDEY0426T82-FL01C spec. Added the 24-pin EPD FPC symbol
    EPD_GDEY0426T82_FPC24 to ereader.kicad_sym with the exact datasheet FPC pin
    numbers (1 NC, 2 GDR, 3 RESE, 4 NC, 5 VSH2, 6/7 NC, 8 BS1, 9 BUSY, 10 RES#,
    11 D/C#, 12 CS#, 13 SCL, 14 SDA, 15 VDDIO, 16 VCI, 17 VSS, 18 VDD, 19 VPP,
    20 VSH1, 21 VGH, 22 VSL, 23 VGL, 24 VCOM); footprint Hirose FH12-24S.
    Reading the datasheet caught two real power-wiring errors carried from the
    hand netlist:
    - Pin 18 VDD is the SSD1677's internally-regulated core rail ("VDD can be
    regulated internally from VCI; connect a capacitor between VDD and VSS").
    It was tied to +3V3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
    [gen_netlist.py]
2026-09-14 gen_netlist.py: fix stock symbol library nicknames
    Diagnostic against the user's KiCad 9 symbol libs showed four references used
    the wrong library:
    - J1: Connector:USB_C_Receptacle_USB2.0 -> Connector:USB_C_Receptacle_USB2.0_16P
    (their lib only has the 14P/16P/24P variants; 16P matches the HRO 16-pin part)
    - J3: Connector:Conn_01x06 -> Connector_Generic:Conn_01x06
    - J5: Connector:Conn_01x02 -> Connector_Generic:Conn_01x02
    - QE: Device:Q_NMOS_GSD -> Transistor_FET:Q_NMOS_GSD
    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
    [gen_netlist.py]
2026-09-14 netlist: align IC pins to vendor symbols + complete power-support wiring
    The SKiDL generator crashed on U5["VOUT"] because the SnapEDA/Ultra
    Librarian symbols name several pins differently from the function-name
    connection list. Fix every mismatch and wire the support pins those
    symbols exposed but the function-name design had omitted.
    Pin-name fixes (referenced by pad number where the name has *, ~{}, or /):
    - U5 VOUT -> pin 8 (VOS, output sense); TPS62840 has no FB pin
    - U3 ALRT -> pin 5 (~{ALERT})
    - U2 INT -> pin 11 (*INT), U2 CE -> pin 14 (*CE)
    - J4 DAT3 -> pin 2 (CD/DAT3)
    Power/support wiring (from datasheet review):
    - U5.EN moved +3V3 -> +SYS. EN on the buck's own output is a startu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
    [gen_netlist.py]
2026-09-15 netlist: print stock-part pin maps to align remaining name references
    Generator now clears every previously-blocking pin and stops at J1["S1"]:
    the KiCad stock USB-C symbol names its shield pin differently, and the same
    "guess the stock-symbol pin name" issue may still lurk on U6/QE/D1. Add a
    temporary diagnostic that prints the real pad-number:pin-name map for every
    stock part referenced by name (J1, U6, QE, D1) BEFORE the nets build, so all
    remaining references can be aligned in a single pass. Removed once green.
    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
    [gen_netlist.py]
2026-09-15 netlist: fix last stock-symbol pins (J1 shield, U6 ESD) + drop diagnostic
    Pin maps confirmed the remaining names:
    - J1 USB-C shield is pad "SH" (was "S1")
    - U6 USBLC6-2SC6 data pins are I/O1 (pads 1&6) and I/O2 (pads 3&4), not
    DP/DM; the paired pads are the same internal node, referenced by number
    - QE (G/S/D) and D1 (A/K) names were already correct
    Every pin reference now resolves against a verified pin. Removed the
    temporary pin-map diagnostic. Connection list updated to match.
    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
    [gen_netlist.py]
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2026-09-15 thermal pads: add TPS62840 EP pin (pad 9) -> GND; BQ25628E HotRod has none
    Read the committed footprints to resolve the thermal-pad flag definitively:
    - U5 TPS62840 (SON50P200X200X80-9N): pad 9 is the center thermal pad. Added
    an EP pin (number 9) to the TPS62840DLCR symbol and tied it into GND. Pure
    addition - no existing pin touched, so the verified netlist is unchanged
    except for the new EP->GND connection.
    - U2 BQ25628E (WQFN-HR18__RYK_TEX): RYK is a TI HotRod package - the footprint
    is pads 1-18 with NO exposed pad, so there is nothing to tie. Flag dissolved.
    U3 MAX17048 EP was already tied. gen_netlist notes + connection list updated.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
    [gen_netlist.py]
2026-09-15 netlist: set R16 = 267k (TPS62840 VSET) for 3.3V output
    Read datasheet Table 1 (SLVSEC6D) from the TPS62840 PDF. The output-voltage
    columns are grouped by device family; the TPS62840DLC (our TPS62840DLCR) sits
    in the TPS62840 column, whose 3.3V row gives RSET = 267k NOM (E96, window
    256.32k-277.68k). Replaced the R16 placeholder with 267k, 1%.
    (Note: the linear PDF text extraction mis-aligned the columns and would have
    suggested 52.3k, which is actually the TPS62842's 3.3V value - confirmed the
    correct column by rendering the table.)
    Second of the two pre-fab flags cleared (thermal pads were the first).
    Claude-Session: https://claude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
    [gen_netlist.py]
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2026-09-15 epd dc-dc: correct topology to Good Display reference; confirm power path; tidy
    EPD DC-DC (was flagged "verify 1:1"): read the GDEY0426T82-FL01C spec section
    8.2 reference circuit and corrected the charge pump to match it exactly:
    - add CE10 (= ref C3) coupling cap between EPD_SW and the new node X; it was
    missing entirely
    - D3 SW->PREVGH(+), D1 anode = VGL rail (PREVGL, -), D2 clamps node X to GND
    (previously D1/D2 anodes hung on SW and the wrong diode fed VGH)
    - part/value map now 1:1 with the ref (LE=47uH, DE1-3=MBR0530, QE=Si1308EDL,
    RE1=2.2R, RE2=1M, all rail caps >=25V)
    Power-path defaults confirmed against the TPS62840 datasheet (SLVSEC6D):
    MODE->GND (power-save), STOP->GND (no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
    [gen_netlist.py]
2026-09-15 charger: verify BQ25628E vs datasheet Fig 9-1; fit RILIM; size PMID caps
    Reviewed the BQ25628E datasheet (SLUSFA4C) typical application (Fig 9-1) and
    electrical spec:
    - REGN 4.7uF (CRG): confirmed correct.
    - PMID: was 1uF; datasheet shows 10uF + 0.1uF. Bumped CPM to 10uF and added
    CPM2 0.1uF.
    - ILIM: was left OPEN. This is unsafe here -- EN_EXTILIM resets to 1h (ILIM pin
    active from power-on), and IINREG = KILIM/RILIM with RILIM=open gives ~0 input
    current, which could stall a USB-only bring-up before firmware runs. Added R17
    = 1.65k (KILIM=2500 -> IINREG ~1.5A). 1.5A is within 0.4-2A so no RC filter is
    required; VINDPM protects weak sources. Retune RILIM=2500/IINREG as needed.
    - P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
    [gen_netlist.py]
2026-09-15 fix U3 footprint: MAX17048 uses the 2x2 9N land (has EP), not the 8N
    Import error "U3 pad 9 not found in ereader:SON50P200X150X100-8N": the
    MAX17048G+T10 is a TDFN-8 2x2 WITH an exposed pad (pad 9) -- the SnapEDA
    symbol's own package property ("TDFN-8") and footprint pairing both say so,
    and the thermal-pad fix correctly wires EP->GND. U3 had been pointed at the
    8N (2x1.5, no-EP) land by mistake, so pad 9 had nowhere to land.
    Point U3 at ereader:SON50P200X200X80-9N (same 2x2/9N land as U5; both are
    TDFN/VSON-8+EP). Re-import with "Replace footprints" swaps U3's land and the
    EP grounds cleanly. Footprints doc rows for U2/U3/U5 updated to the real
    lands (stale "placeholder wrong" notes remove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
    [gen_netlist.py]
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2026-09-15 place the 25 imported parts (charger/buck/gauge decoupling + EPD DC-DC)
    The netlist import left the new parts stacked off-board at X~94-105. Placed
    all 25 onto the board, grouped by subsystem, verified collision-free (no
    courtyard overlap among any of the 81 footprints; kept clear of the antenna
    and microSD keep-outs and >=0.5mm off the board edge):
    - Decoupling next to its IC: CGA/CGB by U3 (CELL), CRG/CPM/CPM2 by U2
    (REGN/PMID), R17 (ILIM) by U2, R16 (VSET) by U5, C4I by U4.
    - EPD DC-DC as one compact block (LE, QE, DE1-3, RE1/2, CE1-10) in the open
    mid-board region (X~20-48, Y~56-67) -- the only contiguous free area; it
    sits on clean copper (0 existing traces there) so it routes fr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
    [ereader.kicad_pcb]
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
